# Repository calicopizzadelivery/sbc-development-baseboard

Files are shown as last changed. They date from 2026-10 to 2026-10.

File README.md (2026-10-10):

# sbc-development-baseboard

One board carrying the hardware you need to develop on and remotely manage an
attached single-board computer: a microcontroller that is a USB device to the
target and a console to you, four individually switched USB-A ports, an FTDI
header straight to the workstation, two isolated
SPDT relays on screw terminals, a level-shifted serial console, and a switched
supply for the target itself.

It replaces a bench that currently takes an FRDM-K64F, a QT Py, an 8-channel
relay board, a two-tier USB hub cascade and a CP2102N dongle, wired together by
hand and documented in a port map that has to be re-surveyed whenever anything
is replugged.

## What it does

| Function | How |
|---|---|
| Type at the target | USB HID keyboard + mouse from the K64's device port |
| Cut power to any USB device | Four USB-A ports on two stacked receptacles, each with its own current-limited switch |
| Hard power-cycle the target | Switched +5V_TGT rail up to 3 A behind an eFuse, or any PSU up to 30 V / 5 A through an isolated relay |
| Toggle target I/O — FORCE_RECOVERY and friends | Two SPDT relays, dry contacts, Phoenix terminals |
| Read the target's serial console | MCU-owned UART, auto level translation 1.2–3.6 V |
| Read it from the workstation directly | FT231X on an internal hub port, standard 6-pin FTDI header, 3.3 V |
| Do all of it from somewhere else | 10/100 Ethernet to the workstation |
| Do all of it with no network | USB CDC console over the onboard DAPLink |

Every one of those is addressable from the same ASCII protocol the relay
controller and the HID injector already speak — one line in, one line out,
starting `OK` or `ERR`. See **[docs/protocol.md](docs/protocol.md)**.

## The shape of it

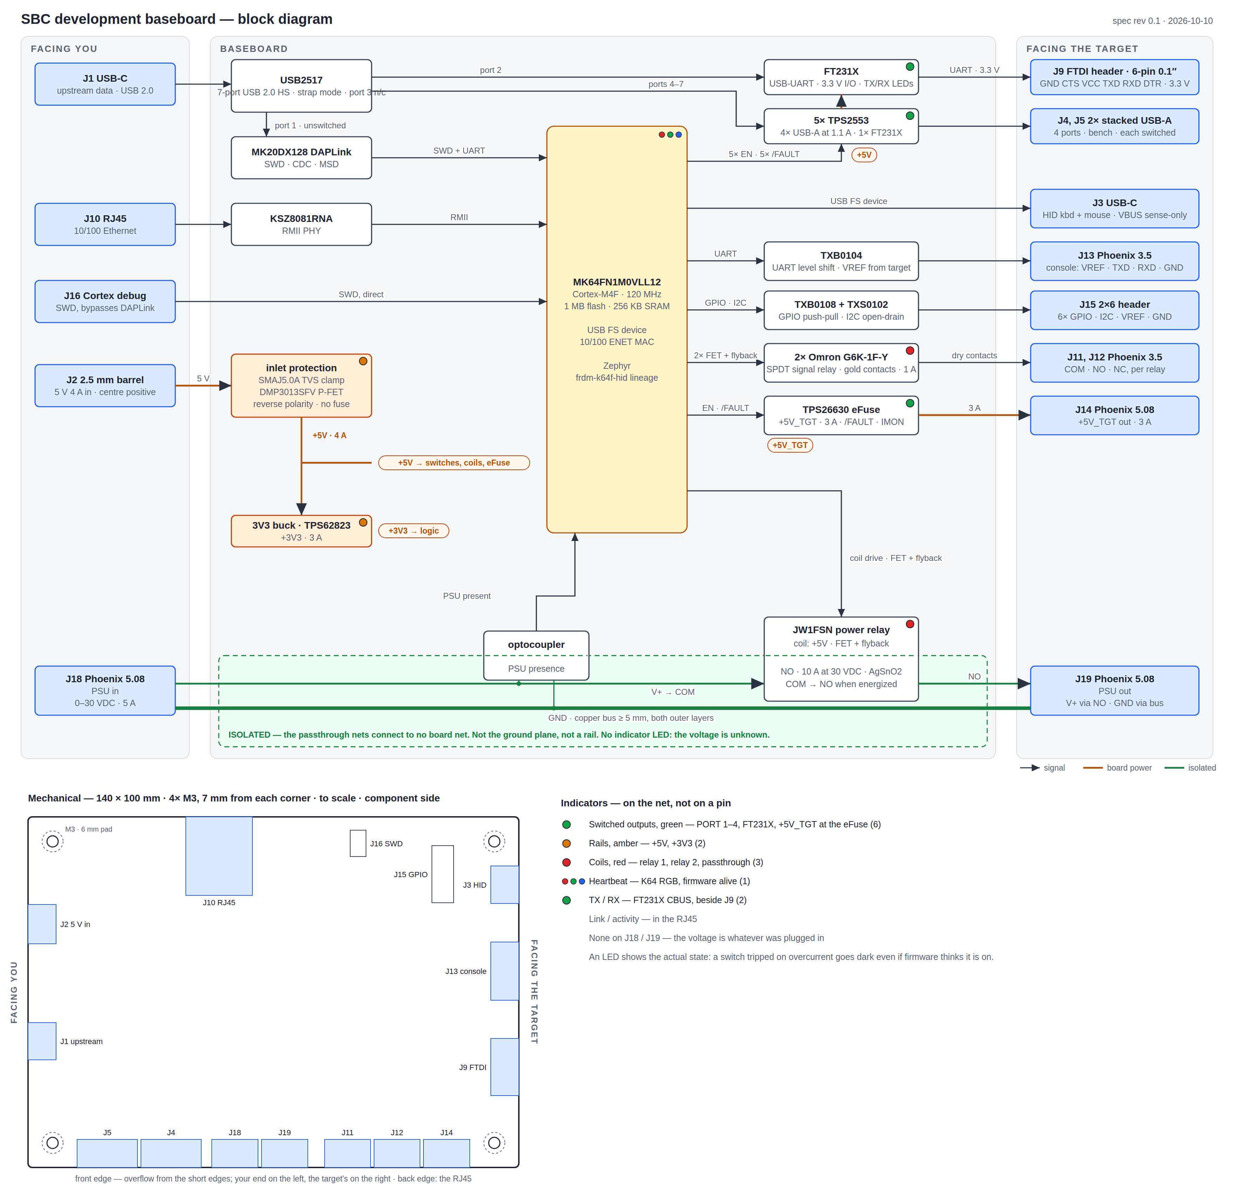
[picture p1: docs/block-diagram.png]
Block diagram


```
workstation ──USB-C──> hub ──> 4x USB-A (switched)     ──> whatever you hang on the bench
                           ──> FT231X, FTDI header     ──> target's console, direct
            ──RJ45───> K64 ──> USB-C device port       ──> target's USB host port
                           ──> UART + VREF             ──> target's console
                           ──> 2x SPDT dry contacts    ──> target's recovery/reset pins
                           ──> switched +5V, 3 A       ──> target's supply
 target PSU ──Phoenix──> isolated relay, NO, 5 A       ──> target's supply, any voltage
 5 V adapter ──barrel──> +5V, one rail, 4 A, 20 W      ──> everything but the passthrough
```

140 × 100 mm, four M3 corner holes. Your connectors leave the left edge, the
target's the right; an LED on every rail, every switched output and every relay
coil, and none on the passthrough, whose voltage is whatever you plugged in.

One USB-C for the workstation and a barrel jack for power (2026-10-10; two
USB-C inlets, a PD charger beside the workstation port, until then). A
workstation port that carries data offers 15 W at best, and four switched ports
plus a target rail need more than that, so power has its own connector: a
5 V 4 A adapter on a 2.5 mm barrel jack, 20 W, which firmware budgets across
the ports and the target rail. A USB-C PD sink feeding two 5 V bucks did that
job first, and went because of what it cost the board rather than the bench:
339 parts became 270, and the one rail layer no longer carries a 3 A inlet
beside two 6 A rails, which is where the router stalled at 98 open connections
on six layers. Keeping power off the workstation link also means the board stays
alive when that link is down, so the MCU can power-cycle the entire USB tree
including its own path back to you.

## Where the design came from

Most of the non-obvious decisions here are bench scars from the Jetson work, not
preferences. They are written up in full in
**[docs/hardware-spec.md](docs/hardware-spec.md)**; the short version:

- **Nothing the MCU depends on sits downstream of a switch it controls.** The
  DAPLink, the Ethernet PHY and the MCU itself are all upstream. `OFF ALL` can
  never take out the console.
- **Rails boot to the state that does no harm.** USB ports and the target rail
  come up powered; relays come up de-energized. Resistors set this while the MCU
  is still in reset, so a reset never drops a load or asserts recovery.
- **The device port cannot back-feed the target.** Its VBUS is sense-only
  through a blocking element. This is the fix for the failure where cutting the
  target's power left it half-alive for 90 seconds because a self-powered
  FRDM-K64F was pushing 5 V up its own device port.
- **The relays are signal relays with gold-clad contacts.** Switching a 1.8 V
  logic pin is a dry circuit; silver power-relay contacts grow an oxide film
  that such a signal cannot break down.
- **The MCU owns the target's console.** No USB-UART bridge to wedge and look
  exactly like a target that is not booting.
- **The target's PSU passes through on its own nets.** A 19 V / 3 A return
  current has no business on the board's ground plane or its USB shields. It
  crosses one relay contact — normally open — so nothing powers until the
  baseboard says so, and a dead baseboard leaves the target off.

## Status

Specification, a generated schematic (KiCad 10, a root sheet and eight sub-sheets, ERC clean) and
a generated, placed six-layer board, both in
[`hardware/kicad/sbc-baseboard/`](hardware/kicad/sbc-baseboard/) with a
[PDF](hardware/kicad/sbc-baseboard/sbc-baseboard.pdf) of the schematic for
review. The board is placed and bulk-routed by the house standard's engine
(see [hardware/kicad/README.md](hardware/kicad/README.md)) and is being
routed again for the barrel-jack inlet (2026-10-10; the board routed before
it, with the PD inlet and the two bucks, stopped at 98 open connections on
six layers and 116 on four); the hand pass that finishes the routing is open.
No firmware.

Next: the routing and the hand pass on the board, then firmware.

## Layout

```
docs/hardware-spec.md   block diagram, part selection, power and pin budgets,
                        safe states, and the open questions
docs/protocol.md        the console protocol, across both transports
docs/block-diagram.*    the diagram above, SVG source and rendered PNG
scripts/block-diagram.py regenerates both; run it with every configuration change
hardware/kicad/         the KiCad project (sbc-baseboard/) and the generator that
                        produced its first pass (gen/) — see hardware/kicad/README.md
hardware/datasheets/    the parts that matter
```

## Related

- [`frdm-k64f-hid`](../frdm-k64f-hid) — the HID injector firmware this board inherits
- [`qtpy-relay-controller`](../qtpy-relay-controller) — the relay protocol and its safe-state rules
- [`nvidia-jetson-tv`](../nvidia-jetson-tv) — the target that motivated all of it

## Licence

Apache-2.0. See [LICENSE](LICENSE).

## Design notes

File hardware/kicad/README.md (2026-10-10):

# KiCad project

`sbc-baseboard/` is the KiCad 10 project: a root sheet and eight sub-sheets,
a project symbol library for the parts the standard libraries lack, an ERC
report, a PDF of every sheet and a BOM.

```
sbc-baseboard/
  sbc-baseboard.kicad_pro   project
  sbc-baseboard.kicad_sch   root: sheet index, mounting holes, the verify-before-fab list
  power.kicad_sch           barrel-jack inlet J2, its TVS and reverse-polarity FET, +5V bulk, the +3V3 buck
  mcu.kicad_sch             K64, USB device port J3, SWD J16, heartbeat
  ethernet.kicad_sch        KSZ8081RNA, magjack
  hub.kicad_sch             USB2517, upstream J1, four switched USB-A, FT231X switch
  ftdi.kicad_sch            FT231X, J9 header, jumpers
  daplink.kicad_sch         MK20DX128 DAPLink
  target.kicad_sch          console, GPIO/I2C breakout, +5V_TGT eFuse
  relays.kicad_sch          two signal relays, PSU passthrough relay and its opto monitor
  libs/                     the house symbol libraries (ecad-libraries), a git submodule pinned to a tag
  sym-lib-table             names them calico-ic and calico-electromechanical, as ${KIPRJMOD}/../libs/...
                            and the stacked USB-A as two units (one per port)
  sbc-baseboard.pdf         all nine sheets
  erc.txt, bom.csv
```

Reference designators are numbered by sheet: R1xx/C1xx power (the inlet
and the +3V3 buck), 2xx MCU, 3xx Ethernet, 4xx hub, 5xx FTDI, 6xx DAPLink,
7xx target I/O (the +5V_TGT eFuse among them), 8xx relays and passthrough.

## How it was made, and the handoff

The schematic was **generated**, by `gen/build.py`. That generator pulls
symbols from KiCad's own libraries (so the embedded copies match what KiCad
ships), builds the missing symbols from datasheet pin tables, lays each sheet
out around its main component (`gen/fanout.py`: lanes leave the IC's pins at
pin pitch, and connectors, series parts, pull-ups and power symbols are drawn
at the ends of the lanes — the style in
[ecad-standards](https://github.com/calicopizzadelivery/ecad-standards)), and
writes the `.kicad_sch` files directly. It then runs `kicad-cli sch erc` and
exports the PDF and BOM. Pin-position maths and power-symbol net naming were
calibrated against `kicad-cli`'s netlist export before any real sheet was
built.

Five checks guard every build and all pass at zero: `kicad-cli sch erc
--severity-all`; `gen/check_geom.py`, which finds wire ends and pin ends that
land on a foreign wire with no junction (the shorts a netlist shows only as a
merged net) and any two wires drawn over each other;
`gen/netcheck.py`, which traces wire-level connectivity in each sheet and
reports any net carrying two rails; and `gen/check_layout.py`, which reports
text over outlines, wires or other text, wires through a part body, and power
symbols pointing the wrong way (GND always hangs down, rails always stand up),
anything on the sheet frame or the title block, pin numbers treated as text
like any other, and pin names inside a symbol that print over each other
(`gen/check_pins.py`, run on library symbols too; its `--gaps` option lists the
closest name pairs). Text widths come from a per-glyph table fitted to the text
extents KiCad writes into its own PDF export. The fifth is reproducibility:
build, `git add` the outputs, build again, and `git status` must be empty. The netlist was also diffed against the
first label-style pass with passive renumbering factored out, so the re-layout
changed drawing, not connectivity (the JP501 default and the J1 VBUS divider
tap, which became a local label, are the two intended exceptions).

**Nothing is drawn over anything else.** Routes into a stacked connector
from one side take staggered columns and rows (the route bound for the
farthest pin gets the outermost column and the nearest row), a tag before a
route ends where the route's target lies, several routes into one pin share
one stub, and a second tap on a wire lands beside the first, never on it.
The geometry check is at zero on every sheet: no wire end on a foreign wire
without a junction, no two wires sharing a stretch.

**The FTDI header is an Adafruit FTDI Friend.** J9 is GND, CTS, VCC, TX, RX,
RTS in that order; VCC is 5 V by default (JP502, bridged A–C) or 3.3 V from
the FT231X's regulator (B–C); pin 6 is RTS by default (JP501, bridged A–C)
or DTR. Logic is 3.3 V. The first pass left J9's VCC pin on an open jumper
only, so it floated by default; the bridged jumpers fix that.

**The DAPLink K20 follows the FRDM-K64F OpenSDA circuit.** DAPLink's k20dx
port reads SWDIO on PTC7 and drives it on PTC6, so both are on the SWDIO
net; the FRDM's 33 Ω series resistors on the K20's USB pair are fitted. See
[reference-design-review.md](../../docs/reference-design-review.md).

**Differential pairs are named for the router.** Every USB 2.0 pair carries
net names `<base>_P` / `<base>_N`, the suffixes KiCad's PCB editor pairs up:
`J1_D`, `J3_D` and `PORT1_D`..`PORT4_D` on the receptacle side of each ESD
array, `HUB_UP` and `HUB_DN1`..`HUB_DN7` at the hub, `K64_USB` and
`FTDI_USB` at the chips (the ESD arrays' pass-through pins and the FT231X's
series resistors each split a pair into two nets, and both halves are named).
The project file carries a `USB` net class matched by pattern
(`*_USB_?`, `*_D_?`, `*HUB_UP_?`, `*HUB_DN?_?`); the patterns are globs over
the full hierarchical name, so a sheet-local net such as `/USB hub/PORT1_VBUS`
is matched only by a pattern that starts with `*` (the port VBUS nets sat in
`Default` until 2026-10-08 for want of that star, and the standard's engine
now stops on a class that no net resolves to). Its differential width and
gap are 0.33 / 0.20 mm, 90 Ω over the ground plane beside each outer layer on
the six-layer stackup (the fab's calculator rules when the stackup is
confirmed); the `ETH` class 0.29 / 0.25 mm for 100 Ω. Route each pair as a pair, no stubs,
over an unbroken reference plane. The power classes are matched the same
way: `PWR_4A` (2.5 mm tracks or pours, 1.0 mm / 0.5 mm vias, three rail vias
per pad) for `+5V` and `*+5V_TGT`, the one inlet rail and the eFuse's
switched output (2026-10-10; until then `PWR_6A` carried the two bucks'
6 A outputs and the PD inlet's `VBUS_IN` ran at 3 A); `USB_VBUS_3A` (2 mm,
1.0 mm vias) for `*PORT?_VBUS` and `*FTDI_VBUS` only; `PWR_1A` (0.6 mm) for
`+3V3`; `PSU_3A` and `PSU_ISO` for the passthrough and its sense lines;
`Default` at 0.2 mm.

**Builds are reproducible.** Every UUID in the generated files is derived,
not drawn: a UUID5 in a namespace made from the project name, keyed by what
the element is (a symbol by its reference and unit, a pin by its symbol, a
wire by its sheet and ends, a label by its sheet, net and position, a sheet by
its file name; identical keys get a counter in draw order). The ERC report
header and the PDF's creation date are pinned to the title-block date. So two
builds of one design give byte-identical files, a commit touches only the
sheets whose design changed, and once layout starts a regenerated sheet keeps
its footprints linked, since the board links footprints to symbols by UUID
path. The costs are the ones KiCad itself has: renaming a reference is a new
symbol, moving a wire or label is a new UUID (nothing outside the sheet refers
to those), and the power symbols, numbered in draw order per sheet, renumber
when one is inserted before them. Keep it that way: never write a random UUID
into the output, and never let an export's timestamp into a tracked file.

**The generator is bring-up tooling, not the source of truth.** The moment
anyone edits the schematic in KiCad, the KiCad files are the design and
`gen/` is history: re-running `build.py` would overwrite the edits. The honest
next step is layout.

```bash
cd gen && ./build.py        # regenerate everything (only while nothing has been hand-edited)
```

## Layout

The board file `sbc-baseboard.kicad_pcb` was generated once, by the
standard's placement engine (`standards/tools/placer.py`, the ecad-standards
repository as a submodule at `standards/`, on KiCad's `pcbnew` Python module)
called from `gen/pcb.py`, from the schematic's netlist, the project file and
the directives in `gen/layout.py`, which are
[docs/layout-directives.md](../../docs/layout-directives.md) as data. It
carries the 140 × 100 mm outline with 2 mm corners, the four M3 holes on GND
7 mm from the corners with their corner keep-outs, Advanced Circuits' 6-layer
stackup, the 270 footprints with their nets (339 until 2026-10-10, when the
USB-C PD inlet, its STUSB4500 controller, bus buffer and programming header
and the two 5 V bucks went and a barrel jack came; 481 connections, 499
before), the L2 and L5 ground planes with the isolated PSU_GND islands, and
`sbc-baseboard.kicad_dru` with the passthrough's isolation rules.

The placement follows
[ecad-standards/layout.md](https://github.com/calicopizzadelivery/ecad-standards/blob/main/layout.md)
section 3: the edge connectors are locked at the directives' positions,
facing outward; the ICs are anchored by flow (the table in the directives:
power enters at J2 on the left edge, its reverse-polarity FET Q101 anchored
at (20, 30) behind the jack with the TVS, gate pull-down, bulk capacitors
and LED around it as the inlet island, the +3V3 buck U105 at (41, 41) as
the one regulator city, laid out from its datasheet figure, and the eFuse
U704 behind J14; the corner the two bucks occupied, x 10..70, y 3..36, is
largely empty since 2026-10-10);
the two parts that straddle the isolation barrier are fixed; every other
part is placed at the pin it serves, by the generator, in five passes (small
decoupling capacitors at their pins, the large parts on an IC's own pins,
bulk capacitors, the small parts on those pins, then parts hosted by other
passives), each on its host's nearest side with the pad on the host's net
facing it, packed outward in rings; since 2026-10-10 the owner's hand
placement outranks all of this (the directives' Placement section: the
saved board is harvested into `gen/hand_placement.py` by the standard's
`tools/handplace.py`, every part fixed where the owner put it, and the
generator reproduces it), so the engine's own placement is what a part
gets until the owner moves it. Small resistors, capacitors, diodes and
transistors that are not on a current-carrying, pair or switching-loop net go
to the bottom, tucked under their host's pin row, clear of through-hole pads
and exposed-pad via fields (the directives' Sides section); the rest stay on
top. The lanes the directives declare (the PSU passthrough: J18 to the relay
to J19) are laid first as footprint keep-outs on both sides and as 2 mm
tracks, so nothing is placed in the way of the 3 A path. ESD parts go down
before anything else, on top, in the first ring at their connector's signal
pins; the USB arrays are flow-through, turned with their receptacle-side
pins toward the receptacle, and both nets of each pair are in the `USB`
class (the schematic build refuses a `_P`/`_N` pair outside it). `placement.txt`
records every part's host, side and ring; the generator prints the parts it
could not keep within 8 mm of their pin. The silkscreen pass places each reference designator where it
overlaps nothing (1.0 mm, then 0.8 mm text) and omits it otherwise, per the
standard's section 6; ICs and connectors are never omitted, their designator
steps out to the nearest pocket instead, and the generator lists those too.
The fabrication layer keeps every designator.

The pairs are laid by the engine as pair lanes (both members at the class's
differential geometry, escapes, the USB-C bridges, two layer changes where
a pair must pass under the port pairs, lengths matched by a bump), the ESD
arrays and series parts anchored for it; the PSU passthrough is laid as
single-net lanes; the one rail, +5V, is a chain of rectangles on L4
referenced to the L5 ground plane, from the jack (x 3..42, y 22..40)
through the 3V3 buck's input, down beside the relay region, along the port
switches, across above the passthrough region to the FTDI switch, the
relays and the eFuse behind J14, which the standard's rails gate holds to
one piece (2026-10-10; until then VBUS_IN, +5V_PORTS and +5V_TGT were
three rails on that layer, the two 6 A ones and the 3 A inlet competing
for it); +5V_TGT leaves the eFuse to J14 as a track in the same class;
+3V3 is routed, in its 0.6 mm `PWR_1A` class, since on six layers a plane
for it would cost the third routing layer. What is left is routed by
FreeRouting through the standard's `tools/autoroute.py` with all of that
locked (`gen/pcb.py --route`; the directives' `FREEROUTING` setting names
the binary), and the hand pass finishes from there. KiCad Routing Tools
was tried on the same board as a second opinion (2026-10-07): two hours in
it had 25 connections left and 1 646 DRC errors, having routed below the
fab's track and via floors and through the keep-outs; FreeRouting honours
the Specctra rules and the fixed lanes, so it stays the bulk router.

`gen/pcb.py` also runs `kicad-cli pcb drc --severity-all --refill-zones`
(the planes are filled for the check and not saved, so a plane that fails to
fill or strays into a keep-out shows; the unconnected count is the ratsnest's
and does not credit the planes); its report is `drc.txt`.

The board as last routed (2026-10-09, six layers, with the PD inlet and the
two bucks still on it; the barrel-jack board of 2026-10-10 started from a
copper reset and is being placed by hand before it is routed again, so
until that routing is committed these are the previous board's figures) is the engine's
placement on the 140 × 100 mm outline, bulk-routed by FreeRouting on L1,
L3 and L6 over the locked lanes, rail vias and planes (`gen/pcb.py --route
--copper`, 24 passes, 5 h 12 min on one thread of which 55 min were its
fanout stage, 122 open connections by its own count after its optimiser)
and given the standard's copper pass: 3 050 track segments, 42 % of the
track length on the top, 37 % on L3 and 21 % on the bottom (of the
router's own, 47 % on L3); 939 vias, of which 237 are the rail vias beside
the pads on the plane nets (156 on ground, 39 on +5V_PORTS, 26 on VBUS_IN,
14 on +5V_TGT, 2 on the passthrough's ground; 14 pads fewer than their
class's count and 115 none at all, both listed in `placement.txt`), 24 the
lanes' own layer changes, 332 ground stitching on the 5 mm grid (2.3
stitching vias per cm² outside the isolated region, 3.5 ground vias per
cm² with the rail vias) and 346 the router's; ground floods over 54 % of
the top and 67 % of the bottom, notched around the passthrough block,
which floods its own `PSU_GND`, all saved filled; the ground planes on L2
and L5 over 76 % each. The three L4 rails are each one piece; +3V3 is
routed at 0.6 mm, 243 segments and 496 mm. The 282 lane tracks are locked
and intact: nine pairs matched to 0.00 mm (six by bumps, three by
symmetric legs), the two Ethernet pairs 2.5 mm apart over their 7.4 to
10.9 mm from jack to PHY, where no bump fits. The router laid the wide
classes at the 2 mm cap apart from the pad-entry necks; five segments run
on at a pad's width more than a millimetre beyond the pad (three on +3V3,
one each on +5V_PORTS and FTDI_VBUS) and are listed for the hand pass to
widen. 98 of the 499 connections
are left for the hand pass: 27 on ordinary signals (61 on four layers), 2
on the HUB_DN2 pair (its shunt capacitors, off the lane), 20 on +3V3, 21
on the port and FTDI VBUS nets, 15 on the 6 A class (the eFuse output's 2
among them), 9 on ground (3 of them the RJ45's ground pin and shield pegs,
inside the magnetics void where no plane reaches), 3 on the passthrough's
sense lines and 1 on the passthrough: the power ones mostly pads with no
room beside them for a rail via, and the port and FTDI VBUS stubs. DRC reports no
errors; its warnings are 23 starved thermals (10 at the three USB-C
receptacles' outer ground pads, whose peg holes leave a flood one spoke,
the rest IC, connector and passive ground pads the routing crowds; the
generator writes that check at warning severity) and one flood neck narrower than
the fab's minimum beside a ground via. From here the board file is the
source of truth and is edited in KiCad; `gen/pcb.py` is not run again over
it, except `--copper`, which adds only what is missing and saves the
board with its fills (the pours are in the file as it is opened and rendered;
until 2026-10-08 the pass stripped them, so the renders showed bare laminate
where the floods are). The schematic generator stays usable: its
derived UUIDs keep the footprints linked.

**The router's settings were measured** (2026-10-08 and 09) on scratch
copies of this placement, each routed from the same placed board with the
standard's wrapper and given the copper pass; open connections after it:
FreeRouting's own costs with the 10 µm clearance margin, 116 (the four-layer
board of 2026-10-08); the margin removed and the small via allowed to every class, 122
(noise: the router had been using the small via on the wide nets all
along); the width cap at 1 mm, 111 (17 fewer on the wide nets, 10 more on
the signals); the cap with via cost 25 and starting rip-up cost 200, 96;
the costs alone with the 2 mm cap, 99, the best on the signals (48 against
61) and on +3V3 (9 against 13). Opening the rail layer to signal routing
made FreeRouting drop the rails as connections (888 open at its first
pass) and run out of time. The costs are the wrapper's defaults from
ecad-standards 743d3a5 on; the cap stays at 2 mm, the margin is gone. The
six-layer board above was routed with them.

The ICs' own layout rules, with sources, are in
[docs/layout-guidelines.md](../../docs/layout-guidelines.md).

The engine's numbers (ring gap, tuck depth, through-hole margin, designator
sizes, which side decoupling takes) are calibrated against 79 published
KiCad boards from Olimex, MNT, SparkFun and Raspberry Pi, measured by
`scripts/harvest-placement.py` (the standard's `tools/harvest.py`) over a
local mirror; the comparison and the
decisions are in [docs/reference-boards.md](../../docs/reference-boards.md)
and in the standard's section 9.

Layout order, per the standard's section 8: the edge connectors against the
mechanical drawing (done: they are locked), the isolated passthrough block
(done: fixed parts, island, rules), then by hand the far-placed parts and
the indicator LEDs, the USB 2.0 pairs from each receptacle through its ESD
array to the hub, the 3V3 buck's switching loop and the +5V rail's `PWR_4A`
pours, and the rest.

State on 2026-10-10, after the first hand pass and the lane redraw: the
generator reproduces the hand placement (271 parts fixed, 84 on the
bottom), the lanes were redrawn around the hand-placed parts where a path
exists (K20_USB enters the DAPLink from the resistors' side over C605 and
past C603; HUB_DN2 crosses the board at y = 54.8, below the DAPLink's
crystal and above Q803; PORT2_D_N's bottom leg passes U408; the standard's
corridors now keep parts off a leg's own side only, so C301 under the ETH
lanes and R211, R435 and D404 under HUB_DN6's leg no longer count), and
`placement.txt`'s "hand placement" section lists what still stands on a
lane: C403 and C406 under the hub's bottom row (HUB_DN1, HUB_DN2, HUB_DN4,
HUB_DN5), the crystal Y401 and its load capacitor C416 at its left column
(HUB_UP, HUB_DN6, HUB_DN7) and R209 at U408's exit (HUB_DN4): the hub's
USB pairs and +3V3 pins alternate along those rows, so a decoupling
capacitor laid against its pin on top sits across a pair's exit, and the
crystal at its pins sits across the upstream pair's. The DRC gate reports
66 errors (138 before the redraw): the lanes laid through those five parts
(shorts, clearance, keep-outs, mask bridges, four hole clearances) and
six hand-placed courtyard overlaps (R211/R433, C105/U105, U403/R208,
C417/R208, U408/R209, C606/Y601); the crossings are gone. 24 pairs of
hand-fixed parts stand closer than the packing margin and 23 gaps between
cities are narrower than 2 mm. The board is not routed before the gate is
clean.

## Design decisions that were made during capture

These are also reflected in `docs/hardware-spec.md`.

- **Hub port map, strap mode.** USB2517 in strap mode (CFG_SEL = 000) so the
  USB tree needs no firmware. In strap mode the self-powered flag shares a pin
  with the non-removable strap, which only covers ports 1-3 — so the DAPLink
  and FT231X went to ports 1 and 2, port 3 is strap-disabled, and the USB-A
  ports are hub ports 4-7. The hub's SMBus is not connected to the K64.
- **Clock tree.** KSZ8081RNA with a 25 MHz crystal in its default 25 MHz mode;
  its 50 MHz REF_CLK output drives the K64's EXTAL0. This is the FRDM-K64F
  arrangement and what Zephyr's `frdm_k64f` board file expects.
- **Power inlet.** A 5 V 4 A (20 W) adapter on a Kycon KLDX-0202-BC barrel
  jack, 2.5 mm centre pin, centre positive, through-hole on the left edge
  (2026-10-10; a USB-C PD inlet with an STUSB4500 sink, its PCA9517A-buffered
  I2C and Qwiic programming header and two TPS54560B 5 V bucks until then,
  which cost 69 of the board's 339 parts and two 6 A rails). An SMAJ5.0A
  TVS at the centre pin; a DMP3013SFV P-channel MOSFET as reverse-polarity
  protection, drain at the jack, source on the rail, gate to GND through
  100 kΩ, body diode toward the rail; 2 × 47 µF, a 100 µF electrolytic and 100 nF on the one +5V
  rail; an amber LED. No series fuse: the adapter limits the inlet, the eFuse
  the target rail, the TPS2553s the ports. The rail feeds the four port
  switches, the FT231X's switch, the three relay coils, the TPS62823 +3V3
  buck and the eFuse. The four ports at their limits, the target at 3 A and
  the board's 0.5 to 0.7 A can sum past 4 A; firmware keeps the 20 W
  budget. The K64's I2C0 and the three PD pins are no-connect, five GPIO
  freed.
- **eFuse.** TPS26630 (in the library) switches +5V_TGT to J14 at 3 A
  (RILIM 6.04 kΩ 1 %, the datasheet's 18 kΩ·A / IOL; 3.65 kΩ for 5 A until
  2026-10-10), UVLO 4.3 V (196k/75k), IMON through 20 kΩ to a K64 ADC pin
  (about 1.7 V at 3 A) and /FLT to a K64 GPIO.
- **I2C translation.** TXS0102 instead of PCA9306, because a 3.3 V target gives
  VREF equal to the K64 rail, which PCA9306 cannot handle.
- **Magjack.** Kycon G7LX-A88S7-BP-GY, because its library symbol names the
  LED pins.
- **K64 USB regulator.** VREGIN is fed only from J3's VBUS through a Schottky,
  so the K64 cannot back-feed the target and its D+ pull-up vanishes when the
  target is off.

## Verify before fab

Listed on the root sheet and in the spec's open questions: K803 JW1FSN pad
mapping, DAPLink k20dx pin assignments, TPS2553 ILIM and TPS26630 UVLO/ILIM
(6.04 kΩ → 3 A) at bring-up, the inlet FET's drop at 4 A, USB2517 VBUS_DET
divider, KSZ8081 crystal load. (The TPS54560B compensation, the STUSB4500
from VSYS alone and the PCA9517A isolation with VCC(B) = 0 went with the PD
inlet, 2026-10-10.)

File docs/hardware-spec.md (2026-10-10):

# SBC development baseboard — hardware specification

*Rev 0.1, 2026-09-12. Specification only; nothing here has been built.*

The board consolidates the hardware used to develop on and remotely manage an
attached SBC. It follows the FRDM-K64F paradigm — an application MCU with a USB
device port facing the target and a separate debug/console path facing the
developer — and extends it with switched USB port power, switched target power,
isolated relay contacts and a level-shifted target console.

---

## 1. Block diagram

Block diagram

*Generated by [`scripts/block-diagram.py`](../scripts/block-diagram.py), which
writes the SVG and renders the PNG, dated in the corner. **When the
configuration changes, change the script, run it, and commit all three in the
same commit as the spec.** The mermaid version below is the same topology, kept
for GitHub's inline rendering.*

```mermaid
flowchart LR
  subgraph WS["facing you"]
    direction TB
    J1["J1 USB-C<br/>upstream data"]
    J10["J10 RJ45<br/>10/100"]
    J2["J2 barrel jack<br/>5 V 4 A in"]
    J18["J18<br/>PSU in"]
  end

  subgraph BD["baseboard"]
    direction TB
    HUB["USB2517<br/>7-port USB 2.0 HS"]
    DAP["MK20DX128<br/>DAPLink<br/>SWD + CDC + MSD"]
    MCU["MK64FN1M0VLL12<br/>Cortex-M4F 120 MHz"]
    PHY["KSZ8081RNA<br/>RMII"]
    INL["SMAJ5.0A + DMP3013SFV<br/>clamp, reverse polarity"]
    B33["TPS62823<br/>+3V3"]
    SW["5x TPS2553<br/>4 ports + FT231X"]
    FTDI["FT231X<br/>USB-UART, 3.3 V"]
    TSW["TPS26630 eFuse<br/>+5V_TGT, 3 A"]
    RLY["2x SPDT<br/>signal relay"]
    PT["passthrough<br/>SPDT power relay, 5 A NO"]
    LT["TXB0104 / TXB0108<br/>TXS0102"]
  end

  subgraph TG["facing the target"]
    direction TB
    J3["J3 USB-C<br/>HID"]
    J13["J13<br/>console"]
    J11["J11, J12<br/>COM/NO/NC"]
    J14["J14<br/>supply"]
    J9["J9<br/>FTDI header"]
    J19["J19<br/>PSU out"]
    J15["J15<br/>GPIO + I2C"]
  end

  J1 --> HUB
  HUB -->|"ports 4-7"| SW --> UA["J4, J5<br/>2x stacked USB-A"]
  HUB -->|"port 2"| FTDI --> J9
  SW -.->|VBUS| FTDI
  HUB -->|"port 1, unswitched"| DAP
  DAP -->|"SWD + UART"| MCU
  J10 --> PHY --> MCU
  J2 --> INL
  INL -.->|"+5V"| SW
  INL -.->|"+5V"| TSW
  INL -.->|"+5V"| RLY
  INL -.->|"+5V"| PT
  INL -.->|"+5V"| B33

  MCU -->|"6x EN + 6x /FAULT"| SW
  MCU -->|"USB FS device"| J3
  MCU -->|UART| LT --> J13
  MCU -->|"GPIO + I2C"| LT --> J15
  MCU -->|"2x FET + flyback"| RLY --> J11
  MCU -->|"EN + /FAULT"| TSW --> J14
  J18 --> PT --> J19
  MCU -->|"FET + flyback"| PT
```

Power is a separate tree; see [§4](#4-power).

Read the arrows into `SW` and `TSW` as the important ones: **port power is
switched by the MCU's own GPIO, not by the hub.** The hub's `PRTPWR` outputs
respond to the *host's* `SetPortFeature(PORT_POWER)` requests, which is the
wrong authority for a bench tool. Cutting a port has to work whether or not a
host is attached and whether or not the host agrees.

---

## 2. Connectors

| Ref | Type | Faces | Purpose |
|---|---|---|---|
| J1 | USB-C receptacle | workstation | Hub upstream data. USB 2.0 only, UFP (5.1 kΩ Rd on both CC). |
| J2 | 2.5 × 5.5 mm barrel jack | adapter | 5 V 4 A (20 W) power in, centre positive: Kycon KLDX-0202-BC, through-hole, horizontal. No data. (2026-10-10; a USB-C PD sink until then.) |
| J3 | USB-C receptacle | target | K64 USB FS device port — HID keyboard/mouse. UFP, **VBUS sense-only**. |
| J4, J5 | USB-A, 2× double-stacked | bench | Hub ports 4–7, two per receptacle, each individually switched (port 1 is the DAPLink, port 2 the FT231X, port 3 disabled). |
| J9 | 6-pin 0.1″ header | target | FT231X UART on hub port 6. Standard FTDI pinout: GND, CTS, VCC, TXD, RXD, RTS/DTR. **3.3 V levels.** |
| J10 | RJ45 + magnetics + LEDs | workstation | 10/100 Ethernet. |
| J11, J12 | 3-pos pluggable 3.5 mm | target | Relay 1 and 2: COM, NO, NC. |
| J13 | 4-pos pluggable 3.5 mm | target | Console: VREF, TXD, RXD, GND. |
| J14 | 2-pos pluggable 5.08 mm | target | Switched +5V_TGT and GND. |
| J15 | 2×6 header, 2.54 mm | target | 6× level-shifted GPIO, I2C SDA/SCL, VREF, GND. |
| J16 | 10-pin Cortex debug | you | Direct SWD to the K64, bypassing DAPLink. |
| J18 | 2-pos pluggable 5.08 mm | PSU | Target passthrough in: V+, GND. 0–30 VDC, 5 A. Isolated from every board net. |
| J19 | 2-pos pluggable 5.08 mm | target | Target passthrough out: V+ through the relay's **NO** contact, GND on the copper bus. Unpowered until commanded. |

Pluggable terminal blocks rather than fixed: a relay's wiring can be unplugged
as a unit and reinstalled the same way, which fixed screw terminals do not give
you. Phoenix MC 1,5/n-G-3,5 headers with MC 1,5/n-ST-3,5 plugs; MKDS 1,5/n-5,08
if you would rather have fixed terminals and do not mind rewiring.

### Why a barrel jack

The brief asked for one USB-C. It cannot be the one, for a reason worth
stating plainly: a USB-C receptacle is a data role and a power role at once.
The board has to be a **UFP** for data, because the hub's upstream port is the
device side of the link to the workstation, and a workstation port that
presents data sources 5 V at 0.9 A, or 15 W if it does PD — enough for the
MCU, not for four switched ports, a bridge and a target rail. Power Role Swap
could in principle ask the workstation for more, but what you get back
depends entirely on the host, which makes the board's capability a property
of whatever it is plugged into. That is not a bench tool. So **J1 is data,
J2 is power**, and J2 carries no data.

Until 2026-10-10 J2 was a second USB-C receptacle: a PD sink negotiating
60 W from a charger into two 5 V bucks, one for the ports and one for the
target, so that every port at its limit plus a 5 A target fitted at once. It
went for the layout's sake. The inlet and its bucks were 69 of the
board's 339 parts (270 since), and the inlet's 3 A rail competed with two 6 A rails for the
one rail layer — the four-layer board plateaued at 116 open connections
after FreeRouting (99 with tuned costs), and six layers reached 98. The 60 W
rationale is withdrawn with them. J2 is now a 2.5 mm barrel jack for a
5 V 4 A adapter, and **the board is budgeted at 20 W**.

What 20 W means: the limiters on the board — four port switches at 1.1 A,
the eFuse at 3 A, the board's own 0.5 to 0.7 A — add up to about twice what
the adapter supplies, and the adapter is the only limit on the sum. Firmware
keeps the budget, refusing to enable more load than 20 W allows (§4). The
typical bench — ports at 2 A, a target at 1 to 2 A, the board at 0.5 A — is
the adapter; every port at its limit and a 3 A target at once is not, and is
no longer a case the board is built for.

The split is still a feature rather than a cost. With J2 alone the MCU, the
relays, the PHY and the target rail are all live, so the board can
power-cycle the whole USB tree — including J1, the path back to the
workstation — and come back. A single-inlet board cannot cut its own
upstream without cutting itself.

### J9, the FTDI header

A second serial console, and a different kind from J13. J13 is owned by the
K64: level-adaptive, captured to a ring buffer, reachable over Ethernet. J9 is
an FT231X on hub port 6, so it appears on the **workstation** as a plain
`/dev/ttyUSB*` and the K64 never sees it. That is the one you want when the
thing you are debugging is the baseboard's own firmware, or when a tool insists
on a real serial device.

The pinout is the one every "FTDI header" means — the TTL-232R cable and the
SparkFun/Arduino breakouts agree on pins 1–5:

| Pin | Signal | Cable colour | Direction |
|---|---|---|---|
| 1 | GND | black | |
| 2 | CTS# | brown | into the FT231X |
| 3 | VCC | red | see below |
| 4 | TXD | orange | **out** of the FT231X — wire to the target's RX |
| 5 | RXD | yellow | **into** the FT231X — wire to the target's TX |
| 6 | RTS# / DTR# | green | out of the FT231X |

Pin 1 is silkscreened `BLK` and pin 6 `GRN`, as the breakouts do, because that
is how people actually orient the cable. TXD and RXD are named from the
FT231X's side, which is also the convention, and the silkscreen carries arrows.

**The header is the Adafruit FTDI Friend** (decided 2026-10-06), jumpers
included. **Pin 6 is RTS# by default** (JP501, bridged A–C), DTR# when the
jumper is cut and bridged B–C; the Friend ships RTS and the Arduino IDE
toggles both, so either uploads to a Pro Mini. **Pin 3 VCC is 5 V by
default** (JP502, bridged A–C), from `FTDI_VBUS` — the switched port supply,
so FTDI CYCLE cuts it — or the FT231X's `3V3OUT` (50 mA) when bridged B–C.
This is a deliberate exception to the §5 back-feed rule: an FTDI header is
expected to power the little board it is plugged into, exactly as the Friend
does, and it is the only board rail that reaches the target by design.

**It is a 3.3 V port.** `VCCIO` comes from `3V3OUT`. Connected to a 1.8 V
console, TXD drives 3.3 V into the target's RX pad. 470 Ω in series with TXD
and pin 6 holds that to a couple of milliamps through the target's clamp, so
the mistake is survivable, but it is still a mistake — **1.8 V consoles go on
J13**, which follows VREF. Question 12 asked whether pin 3 should be able to
*take* a VREF instead; it cannot, because the Friend's pin 3 is an output.

**Its VBUS goes through a TPS2553, like a port, but it is not a port.** The
bench notes record a CP2102N that stayed enumerated and openable while
delivering nothing, and was read as a dead target. The remedy was to
power-cycle its hub port. The FT231X is a better chip, and the failure is not
specific to a chip. So its VBUS is switchable — `FTDI CYCLE` — but under its
own verb, **outside the `PORT ALL` sweep**, booting on. The thing you are
reading the boot log on cannot be swept away.

Hub ports 6 and 7 are flagged non-removable in the USB2517's configuration,
which is what they are. Two LEDs on the FT231X's CBUS pins show TX and RX
activity at the header. TVS on all four signals; the header will be hot-plugged.

### Placement and form factor

**140 × 100 mm (140 × 80 until 2026-10-07, when the routed board proved
too tight and 20 mm was added between the middle blocks and the front
edge), four M3 mounting holes 7 mm in from each corner (10 mm until the
first placement pass, 2026-10-06); connectors, ICs, relays and large parts
on top, small passives on the bottom (one side until the placement pass).** Connectors that face you leave the **left** edge; connectors that
face the target leave the **right** edge. Those are the rules. Here is what
they produce once the arithmetic is done.

A corner hole with a 6 mm standoff pad keeps edge connectors out of the first
~13 mm at each end of an edge (the edges were packed from 14 mm with the
holes at 10 mm; at 7 mm the keep-out is 10.5 mm and the connectors stayed), so
each 100 mm edge has about **74 mm** of usable length (54 mm while the
board was 80 mm tall) and each 140 mm edge about **114 mm**. The target-side
connectors alone — J3, J13, J11, J12, J14, J19, at Phoenix 3.5 and 5.08 mm
body widths — come to **73 mm**. They did not fit on an 80 mm edge in any
order, and on the 100 mm edge they would fill it to the last millimetre, so
the arrangement below stands.

So the short edges carry the primary cable connectors, and the rest go on the
**front** long edge at the end that matches their direction — your things at
the left end, the target's at the right. The back edge was to carry nothing,
so the board could sit against a wall or a DIN rail; at layout (2026-10-06)
the RJ45 moved there, alone, so the two left-edge connectors (both USB-C until 2026-10-10)
could spread along the left edge. The wall and the rail are given up.

| Edge | Connectors | Bodies |
|---|---|---|
| Left, 74 mm usable | J2 power in · J1 upstream, split around the middle | 22 mm |
| Back, 114 mm usable | J10 RJ45 | 19 mm |
| Right, 74 mm usable | J3 HID · J13 console · J19 PSU out | 37 mm |
| Front, left end | J4, J5 USB-A stacks · J18 PSU in | 39 mm |
| Front, right end | J9 FTDI (right-angle) · J11, J12 relays · J14 +5V_TGT | 52 mm |
| Inboard, vertical | J16 Cortex debug · J15 GPIO header | — |

Revised at layout (2026-10-06), see [layout-directives.md](layout-directives.md):
the RJ45 measures 22 mm, so it went to the back edge; J19 moved beside J18
so the isolated passthrough is one region; J9 took the right edge. The
barrel jack (2026-10-10) took the USB-C PD receptacle's place on the left
edge: its front face at the edge, its body 14.5 mm inboard, the
reverse-polarity FET and the clamp behind it.

J16 and J15 are pin headers that take a ribbon or jumpers from any direction,
so they earn no edge. J9 is right-angle because that is what an FTDI header is.

If everything must leave the short edges, the board needs to be **100 mm**
tall: 74 mm usable per edge takes the target-side set with 13 mm of gaps to
spare. That is the alternative to the front-edge overflow, and a one-line
change here.

The mechanical inset on the block diagram is to scale.

---

## 3. Part selection

| Block | Part | Notes |
|---|---|---|
| Application MCU | **MK64FN1M0VLL12** | 100-LQFP, Cortex-M4F 120 MHz, 1 MB flash, 256 KB SRAM, USB FS OTG, 10/100 MAC. Same die as the FRDM-K64F, whose schematic is public and serves as the reference design. |
| Ethernet PHY | **KSZ8081RNA** | RMII, same part as the FRDM, so the Zephyr devicetree carries over. Clocked the FRDM way: 25 MHz crystal on XI/XO, RMII 25 MHz mode (the RNA power-up default), REF_CLK outputs 50 MHz into the K64's EXTAL0. Zephyr's `frdm_k64f` board file says `microchip,interface-type = "rmii-25MHz"`, which is this arrangement. |
| Debug/console MCU | **MK20DX128VFM5** running DAPLink | CMSIS-DAP SWD + USB CDC + mass-storage drag-drop, exactly as OpenSDA v2 does today. |
| USB hub | **USB2517** (or USB2517i) | Strap-configured (CFG_SEL = 000), so the USB tree comes up with no firmware: port 1 DAPLink, port 2 FT231X, port 3 disabled by strap, ports 4–7 to the USB-A receptacles. NON_REM = 11 and LOCAL_PWR = 1 from three resistors. The hub's SMBus is not connected to the K64. 24 MHz crystal. |
| Port switches, 5× | **TPS2553** | Four USB-A ports and the FT231X's VBUS. Adjustable current limit via `ILIM`, soft-start, open-drain `/FAULT`. |
| USB-A receptacles, 2× | double-stacked USB 2.0 Type-A, through-hole | Würth WR-COM dual-port class (61400826021). Two ports per body, shield tabs to chassis. Four ports on two bodies rather than five with one on its own. |
| USB-UART bridge | **FT231XS** | SSOP-20 (`FT231XQ` for QFN). Bus-powered from hub port 6; `3V3OUT` feeds `VCCIO`. CBUS0/1 drive TX/RX LEDs. |
| FTDI header | 6-pin 0.1″, right-angle, board edge | J9. Two solder jumpers: pin 6 RTS#/DTR#, pin 3 VCC. 470 Ω series on TXD and pin 6. |
| Target rail switch | **TPS26630RGE** | 4.5–60 V, 0.6–6 A eFuse, in the KiCad library (TPS25940 is not). ILIM 6.04 kΩ 1 % → 3 A, the datasheet's RILIM = 18 kΩ·A / IOL (3.65 kΩ → 5 A until 2026-10-10, when the 20 W inlet set the budget); UVLO 196k/75k → 4.3 V; `/FLT` to the K64; IMON 20 kΩ, about 1.7 V at 3 A, into a K64 ADC pin for target current. Its input is +5V, its output the switched target rail +5V_TGT. |
| Power inlet | **Kycon KLDX-0202-BC** | J2: 2.5 mm centre pin, 5.5 mm sleeve, centre positive, through-hole, horizontal, for a 5 V 4 A (20 W) adapter. KiCad's `Barrel_Jack_Switch` symbol, the switch contact (pin 3) unused. (2026-10-10; a USB-C PD receptacle with an STUSB4500 sink and two TPS54560B 5 V bucks until then — §2.) |
| Inlet clamp | **SMAJ5.0A** | D101, SMA, from the jack's centre pin to GND. |
| Reverse-polarity protection | **DMP3013SFV** | Q101, P-channel, PowerDI3333-8: −30 V, 12 A, 9.5 mΩ. Drain at the jack, source on +5V, gate to GND through R102 100 kΩ, body diode toward the rail. 2 × 47 µF + 100 µF/10 V 1210 and 100 nF on +5V behind it, and the rail's amber LED. No series fuse: the adapter limits the inlet, the eFuse the target rail, the TPS2553s the ports. |
| 3V3 buck | **TPS62823DLC** | U105. 3 A synchronous, +5V → +3V3. ("Buck 3" until 2026-10-10, when bucks 1 and 2 went with the PD inlet.) |
| Magjack | **Kycon G7LX-A88S7-BP-GY** | 10/100 with LEDs. Chosen over the Würth part because its library symbol names the LED pins. |
| Relays, 2× | **Omron G6K-1F-Y**, 5 V coil | 1 Form C (SPDT), gold-clad contacts, 1 A / 30 VDC, ~30 mA coil. |
| Power relay | **Panasonic JW1FSN-DC5V** | 1 Form C, load on the **NO** contact: 10 A at 30 VDC resistive, AgSnO2, sealed. 530 mW coil, 106 mA at 5 V. Alternates: Omron G2R-1 DC5, G5LE-1 DC5. Ratings in §4. |
| Relay drivers, 3× | 2N7002 (signal relays), AO3400A (power relay) + 1N4148W flyback each | One FET per coil (Q801, Q802, Q803), gate pulldown to ground — see §5. |
| PSU presence detect | LTV-817-class optocoupler | Optional. The only component that touches the passthrough, across an isolation barrier — see §4. |
| UART translation | **TXB0104** | Auto-direction, push-pull. `VCCA` from J13's VREF pin. |
| I2C translation | **TXS0102** | Open-drain auto-direction with internal pull-ups. Chosen over PCA9306 because a 3.3 V target makes VREF equal to the K64 rail, and PCA9306 needs VREF2 > VREF1. Range 1.65–3.6 V. **Do not** use a TXB part for I2C. |
| GPIO translation | **TXB0108** | Same VREF as the console. |
| ESD | USBLC6-2SC6 or TPD2E2U06 per USB pair | Plus TVS on the screw-terminal nets. |

### Two notes on parts that are easy to get wrong

**Relay contact material.** The two relays exist to short things like
FORCE_RECOVERY to ground — a *dry circuit*, microamps at 1.8 V. Silver contacts
on a general-purpose power relay develop a sulphide film that needs tens of
volts or hundreds of milliamps to break down, so such a relay can read as closed
on a multimeter and still not pull a logic pin low. Gold-clad contacts on a
signal relay are specified for exactly this. The ceiling is then 1 A, which is
why target power is a separate switched rail rather than a third relay.

**TXB parts are push-pull only.** A TXB0104 or TXB0108 has weak (~4 kΩ) one-shot
assisted drivers and will fight any external pull-up below about 50 kΩ; on an
open-drain net it simply does not work. The console is push-pull, so TXB is
right there; I2C is open-drain, so it gets a PCA9306. The GPIO breakout is TXB,
which means **the header's pins are push-pull and must not be used as
open-drain** — document that on the silkscreen.

### Indicators

An LED on every load switch output, every power rail, and every relay coil, so
a glance at the board answers "is it powered" and "is it asserted" without a
console. Colour says which kind:

| Colour | Means | On | Count |
|---|---|---|---|
| **Green** | a switched output is live | PORT 1–4 switched VBUS · FT231X switched VBUS · +5V_TGT at the eFuse output | 6 |
| **Amber** | a rail is up | +5V at the inlet · +3V3 | 2 |
| **Red** | a coil is energized | relay 1 · relay 2 · passthrough relay | 3 |
| RGB | heartbeat | K64 — firmware alive, which profile | 1 |
| Green ×2 | TX / RX | FT231X CBUS, beside J9 | 2 |
| Link / act | | in the RJ45 | — |

The output and coil LEDs sit **on the net, not on an MCU pin**: a port LED
hangs off the switched VBUS, a coil LED sits across the coil and is driven by
the FET. They show the actual state rather than the commanded one — a switch
that has tripped on overcurrent goes dark even though firmware thinks it is on
— and they cost no pins. About 25 mA in total; not budgeted separately.

**No LED on the passthrough.** J18 and J19 carry whatever the target's PSU is,
5 to 30 V, and an indicator sized for one end of that range is wrong at the
other. The only element across the passthrough is the optocoupler's emitter,
which exists *because* the voltage is unknown and has its series resistance
sized for the whole range. `psu=present` on the console is the indicator.

---

## 4. Power

### Tree

```
J2 ──> D101 ──> Q101 ──> +5V ──┬──> 4x TPS2553 ──> J4, J5
     SMAJ5.0A   DMP3013SFV     ├──> 1x TPS2553 ──> FT231X
     to GND     reverse        ├──> 3x relay coil
                polarity       ├──> TPS62823 ──> +3V3
                               └──> TPS26630 eFuse ──> +5V_TGT ──> J14
```

One 5 V rail, straight from the adapter (2026-10-10; a USB-C PD inlet, an
STUSB4500 sink and two TPS54560B 5 V bucks — one for the ports, one for the
target — until then). The inlet is a clamp and a pass FET. D101, an SMAJ5.0A,
clamps the jack's centre pin to ground. Q101, a DMP3013SFV P-channel MOSFET, passes
it to the rail: drain at the jack, source on +5V, gate held at ground by
R102 100 kΩ, body diode toward the rail. A reversed adapter leaves the FET
off and the body diode reverse-biased; a correct one turns it on through
9.5 mΩ, about 40 mV at 4 A. Behind it C101 and C102, 47 µF/10 V, C103, 100 µF/10 V electrolytic (the hub's
downstream ports want 120 µF of bulk on their rail), and C104,
100 nF, are the rail's bulk capacitance, and D102, amber, shows the rail.

There is no series fuse: the adapter limits the inlet, the eFuse limits the
target rail and the TPS2553s limit the ports.

The second buck used to keep a target's inrush — large and poorly
characterised, since you do not know what is on the other end of J14 — off
the rail the hub ports share. The eFuse does that now: +5V_TGT is behind its
3 A current limit, so the target cannot pull more than that from the shared
rail at any instant. What the ports and the board draw beside it is the
budget below.

`+3V3` is the TPS62823, U105, from `+5V`: a regulated input and a narrow
conversion ratio for the logic supply.

The target passthrough (J18 → J19) is deliberately absent from this tree. It
is not a board rail and draws nothing from the adapter; see below.

### Budget

| Rail | Load | Typical | At the limiters |
|---|---|---|---|
| +5V | 4× USB-A, each TPS2553 at 1.1 A | 4 × 0.5 A = 2.0 A | 4 × 1.1 A = 4.4 A |
| | FT231X, and J9 VCC if jumpered | 10 mA | 60 mA |
| | 3× relay coil — 2× G6K at 30 mA, JW1FSN at 106 mA | 170 mA | 170 mA |
| +5V_TGT | target SBC, behind the 3 A eFuse | 1.0–2.0 A | 3.0 A |
| +3V3 | K64 ~100 mA, KSZ8081 ~60 mA, USB2517 ~250 mA, DAPLink ~30 mA, translators ~20 mA | 0.30 A | 0.50 A |
| **Total at 5 V** | | **≈4 A (20 W)** | **≈8 A (40 W)** |

The adapter is 5 V at 4 A, and it is the only limit on the sum: the port
switches, the eFuse and the board can together ask for about twice what it
gives, and nothing on the board — no inlet fuse, no contract — stops them.
So **firmware keeps the budget**. It refuses to enable more load than 20 W
allows, reporting `ERR POWER BUDGET` rather than browning out the rail and
dropping every device at once; `POWER` reports the rail's presence and the
eFuse's `IMON` current, the one measurement the board has, and there is no
contract to read (2026-10-10; until then the STUSB4500's negotiated RDO set
the budget). This is the single most load-bearing argument for the MCU
owning port power rather than the hub: the hub has no idea what the inlet
can give. The typical bench — ports at 2 A, a target at 1 to 2 A, the board
at 0.5 A — is the adapter. Every port at its limit plus a 3 A target is
twice it.

Per-port limit is set to ~1.1 A by the `ILIM` resistor: a 500 mA device plus
inrush headroom, and well under what a single port could otherwise pull from a
shared rail.

### Target passthrough

Not every target runs from 5 V. An Xavier AGX ships with a 19 V / 3 A supply,
and the board's own +5V_TGT rail — inside the 20 W budget, behind a 3 A eFuse — is
the wrong tool for it. So J18 and J19 pass an external PSU straight through,
the board's only involvement being one relay contact in the high side.

```
J18 (PSU in)   V+  ──> relay COM ── NO ──> V+   J19 (target out)
               GND ──> copper bus, ≥5 mm, both outer layers ──> GND
```

**The passthrough nets are independent of every board net.** Not the ground
plane, not any rail. The relay's coil is on the board; its contacts are not.
Three reasons, all of which matter at 19 V / 3 A:

- The board is not in the PSU's return path. 3 A does not flow through the
  ground plane, out through the USB shields to the workstation, or down the
  console cable's GND.
- Any PSU can be attached — 5 to 30 V, either polarity, floating or
  earth-referenced — and the board neither knows nor cares.
- A fault on the target's supply side cannot reach the board's logic.

The target's ground still meets the board's through J3 and J13, as it would on
any bench. The point is that the *power* current does not.

**NO, not NC.** The relay is de-energized with the target *off*. Nothing on J19
powers until the baseboard is up and has been told to, and a baseboard that has
lost its own power, or been unplugged, leaves the target off. A target cannot
come up unexpectedly, and a coil cannot energize by accident. Rev 0.1 had this
the other way — NC, the §5 rule taken one step further, so a dead baseboard
still passed power — and it was switched on 2026-10-03 for the workflow: on this
bench, power is something the baseboard *grants*.

The cost is the mirror image, and it is a real one: **a baseboard reset is a
target power cycle.** The gate pulldown drops the coil the instant the K64
enters reset, and firmware cannot pick it up until it is running — a few hundred
milliseconds at best, which is longer than an SBC's input capacitance will hold
it up. Firmware persists the commanded state and restores it first thing at
boot, so the target comes back without anyone asking; but it does come *back*.
The §5 line "resetting the baseboard must not reset the target" holds for
+5V_TGT and the ports, and not for this rail. If that ever matters, the hardware
answer is a latching relay — Omron's G2RK-1 is the double-winding version of the
G2R-1, in the same datasheet, 5 A at 30 VDC, and it holds its state with no coil
power through any reset and through power loss. It is not fitted.

**The load sits on the NO contact, so the headline rating is the one that
applies.** It was going to sit on NC, where SPDT power relays are commonly
derated in a table further into the datasheet, which is why these were read off
the datasheets on 2026-10-03; the table stays as the record:

| Relay | Form C at 30 VDC, resistive | NC derated? | Contacts | 5 V coil |
|---|---|---|---|---|
| **Panasonic JW1FSN** | **10 A** | no | **AgSnO2** | 530 mW |
| Omron G2R-1 | 10 A | no | Ag-alloy | 530 mW |
| Omron G5LE-1 | 8 A, carry 10 A | no | Ag-alloy | ≈400 mW |
| Schrack RT314005 | 16 A rated; ≈10 A at 30 VDC off the breaking curve | no — NC rated 16 A | AgNi 90/10 | 400 mW |
| Omron G5Q-1 | 5 A NO | **3 A NC** | — | — |
| Omron G5LE-1-E | 16 A NO at 250 VAC | **12 A NC** | — | — |

The G5Q-1 is the trap in one line: a "10 A" relay whose NC contact carries 3 A.
On NO, every part in the top half is simply its headline figure. The JW1FSN
stays the pick for its AgSnO2 contacts: an SBC's input is a bank of bulk
capacitance, so every `TGT PSU ON` closes into an inrush of tens of amps for
microseconds, which AgSnO2 tolerates and AgNi pits under. At an AGX's 3 A the
contact runs at 30 % of rating; at the design figure of 5 A, 50 %. The 5 A
design rating stays, and the copper with it. Resistive and capacitive loads are
assumed and no snubber is fitted, so an inductive load on J19 needs its own.

**Copper.** 5 A continuous at a 10 °C rise wants about 2.7 mm of 1 oz outer
copper by IPC-2221. The run is not short: J18 is at the front-left and J19 on
the right edge (§2), so V+ and GND each cover about 110 mm. At **8 mm** wide on
both outer layers, via-stitched and paralleled, that is roughly 4 mΩ per
conductor — 20 mV and 0.1 W each at 5 A. Use ≥8 mm, and put the relay next to
J19 so the switched segment is the short one. The relay's contact pins get solid
pads, no thermal relief. Keep ≥1 mm from every board net, so the isolation is
visible in the layout and not only in the netlist.

**Presence detect, optional, fitted by default.** An optocoupler across J18: LED
in series with a resistor sized to stay within limits from 5 to 30 V (split for
dissipation), an antiparallel diode so a reversed PSU does no harm, transistor
side on a K64 GPIO. That gives `psu=present` in `STATE` without breaking the
isolation, and it is the only component on the board that touches the
passthrough at all. It is the difference between "the target is not booting"
and "the PSU is not plugged in".

---

## 5. Safe states

Every rail's state while the MCU is in reset is set by a resistor, not by
firmware, because K64 GPIO are inputs at reset and stay that way until code
runs. Choose each switch's enable polarity so the passive state is the safe one.

| Load | State in reset | Set by | Why |
|---|---|---|---|
| J4, J5 USB-A ports, FT231X | **ON** | pull-up on active-high `EN` | Never silently drop power. A watchdog reset must not disconnect the console adapter you are reading the target's boot log on — which on this board may be the FT231X itself. |
| +5V_TGT | **ON** | pull-up on `EN` | Same. Resetting the baseboard must not reset the target. |
| Relay 1, 2 | **DE-ENERGIZED** | 100 kΩ gate pulldown | A relay that energizes at boot asserts FORCE_RECOVERY on every reset of the controller. Which way that fails is the installer's choice — SPDT gives both NO and NC on the terminal block. |
| Passthrough relay | **OFF** (de-energized, NO open) | 100 kΩ gate pulldown, and the relay itself | Nothing on J19 powers until firmware is up and has been told to. The cost — a baseboard reset drops the target — is accepted; see §4. |

This is carried straight from the relay controller, where the two firmware
profiles boot opposite ways for exactly these reasons, and where a unit test
asserts each one.

Two matching firmware rules:

1. **Write the output register before enabling the driver.** On K64, `PDOR`
   before `PDDR`. Reversing them drives the pin's reset value for as long as it
   takes to reach the next instruction, which is enough to click a relay.
2. **The relay pins are never configured as anything but GPIO outputs.** No
   alternate-function pin shared with a peripheral that might drive it.
3. **Restore the passthrough's persisted state immediately after rule 1**,
   before the network, before USB, before anything that can block. Every
   millisecond here is target downtime.

### Back-feed

The failure to design out: a self-powered board pushing 5 V up its own device
port into the target, so cutting the target's power leaves it half-alive. On the
current bench this takes 90 seconds to decay, the console goes silent, and the
whole thing reads as a dead module rather than a power problem. `jetson-power.py`
works around it in software by cutting the back-feed port first.

Here it is a hardware rule: **J3's VBUS is an input only.** A >100 kΩ divider for
presence detection, and if the K64's `VREGIN` is fed from it at all, through a
blocking element. No path from any board rail onto J3's VBUS, on any layer.

That removes the VBUS path entirely. What remains is the 1.5 kΩ D+ pull-up,
which can trickle a milliamp or so into the target's PHY rail — orders of
magnitude below what holds an SBC alive, and not worth a data mux to fix.

---

## 6. Pin budget

100-LQFP, checked against function so that pin count does not become a surprise
during capture.

| Function | Pins |
|---|---|
| RMII to PHY — TXD0/1, TXEN, RXD0/1, RXER, CRS_DV, MDIO, MDC | 9 |
| RMII 50 MHz reference | 1 |
| USB FS device — DP, DM, VREGIN, VOUT33 | 4 (dedicated) |
| Port power — 4× EN, 4× /FAULT | 8 |
| FT231X power — EN, /FAULT | 2 |
| Target power — EN, /FAULT | 2 |
| Relays — 3× gate | 3 |
| PSU presence — optocoupler | 1 |
| Target UART — TXD, RXD | 2 |
| DAPLink CDC UART — TXD, RXD | 2 |
| I2C — target breakout (separate bus) | 2 |
| GPIO breakout | 6 |
| Hub `RESET_N`, PHY interrupt | 2 |
| SWD — SWCLK, SWDIO, `RESET_b` | 3 |
| Status — RGB heartbeat; every other LED is on its net, §3 | 3 |
| **Total signal** | **50** |

Comfortable in a 100-LQFP after power and analogue pins, and five pins freer
than it was (2026-10-10: the PD sink's I2C0 and its three status lines went
with the PD inlet; 53 signal pins until then). Two things to note: the
target's I2C is on its own bus, I2C1, so a target that hangs SDA low takes
out nothing of the board's — I2C0 is free and the hub's SMBus is not
connected; and the port LEDs can move behind a shift register if layout
wants the pins back, since their timing does not matter.

### Allocation (as captured)

| K64 pins | Function |
|---|---|
| PTA5, PTA12–17, PTB0, PTB1 | RMII (same as FRDM-K64F) |
| PTA18 (EXTAL0) | 50 MHz REF_CLK from the PHY |
| PTA0, PTA3, RESET_b | SWD (J16 and DAPLink) |
| PTB16, PTB17 | UART0 to the DAPLink CDC |
| PTC3, PTC4 | UART1 to the target console (J13) |
| PTC10, PTC11 | I2C1 to the target (J15) through the TXS0102 |
| PTC0, PTC1, PTC2, PTC5 / PTC6–PTC9 | PORT1–4 EN / FAULT |
| PTC12, PTC13 | FTDI EN / FAULT |
| PTC14, PTC15, PTB2 | TGT_EN, TGT_FAULT, TGT_IMON (ADC0_SE12) |
| PTC16, PTC17, PTC18 | relay 1, relay 2, passthrough coil |
| PTB3 | PSU_PRESENT |
| PTB18, PTB22 | HUB_RESET, PHY_INT |
| PTB19, PTB20, PTB21 | heartbeat RGB |
| PTD0–PTD5, PTD6 | GPIO1–6 to J15, J3 VBUS sense |
| spare | PTA1, PTA2, PTB23, PTD7, PTE0–6, PTE26, the ADC/DAC pins; PTE24, PTE25 (I2C0) and PTB9, PTB10, PTB11 (pins 31, 32, 57, 58, 59), no-connect since the PD inlet went (2026-10-10) |

---

## 7. Firmware

Zephyr, extending `frdm-k64f-hid`. That application already splits its command
layer from its transport — it takes a line and a reply function — so the
Ethernet listener is an addition rather than a rewrite.

Three transports, one parser:

| Transport | Path | For |
|---|---|---|
| USB CDC | DAPLink on hub port 1 → J1 | Local work, bring-up, and whenever the network is the thing that is broken |
| TCP | Ethernet → J10 | Remote management, the normal case |
| SWD | DAPLink → J16 | Debugging the baseboard itself |

J9 is not a transport. It reaches the workstation through the hub and the K64
cannot see it; the only thing firmware does with it is power-cycle it.

Protocol in **[protocol.md](protocol.md)**. It keeps the `OK`/`ERR` single-line
convention both existing firmwares use, and the persistent `SETID` identity from
the relay controller — several of these will share a workstation, and a script
that picks the wrong board cuts power to the wrong machine.

The RGB heartbeat from the QT Py carries over: a glance at the board says the
firmware is running and its loop is not wedged.

---

## 8. Open questions

| # | Question | Blocks |
|---|---|---|
| 1 | ~~Per-port current limit — 0.75 A or 1.1 A?~~ **Resolved** at four ports: 1.1 A. See §4. | — |
| 2 | ~~Clock tree~~ **Resolved** from Zephyr's `frdm_k64f` board file (`rmii-25MHz`): 25 MHz crystal on the PHY, its 50 MHz REF_CLK into the K64. Captured that way. | — |
| 3 | DAPLink board ID and MSD volume name. A custom DAPLink build can name the volume anything; `frdm-k64f-hid/scripts/flash.sh` already reads `LABEL=${MBED_LABEL:-MBED}`, so agreeing with it is one environment variable rather than a change. Decide the name. | Firmware tooling |
| 4 | USB VID/PID. **Deferred indefinitely, by decision (2026-10-03).** `frdm-k64f-hid` ships `2fe3:0001`, the Zephyr project's VID, and the hub and DAPLink will want identifiers too; all of it stays as-is on the bench. Revisit only if a board leaves the lab. | — |
| 5 | K64 lead time. If it is bad, the fallback is an RP2350 + W5500, which costs the Zephyr board port and the FRDM tooling. | BOM |
| 6 | ~~Does J14 need a raw inlet pass-through for 12 V targets?~~ **Resolved** by J18/J19: any PSU passes through, isolated. J14 stays for 5 V targets that want to live inside the 20 W budget without a PSU of their own. | — |
| 7 | ~~Form factor and mounting~~ **Resolved:** 140 × 100 mm (140 × 80 until 2026-10-07), four M3 at 7 mm from each corner (10 mm until the first placement pass), you on the left edge, the target on the right, overflow to the front edge. §2. | — |
| 8 | Authentication on the TCP transport. Today anything that can reach the port can cut the target's power and assert its recovery pins. A trusted segment is the assumption; decide whether that is good enough. | Remote management outside the lab |
| 14 | ~~DAPLink k20dx HIC pin assignments~~ **Resolved** (2026-10-06) against DAPLink's `k20dx/IO_Config.h` and `uart.c` and the FRDM-K64F OpenSDA schematic: SWCLK PTC5, SWDIO out PTC6 **and SWDIO in PTC7** (both on the SWDIO net, as on the FRDM), nRESET PTB1, LED PTD4, UART1 PTC3 RX / PTC4 TX. The FRDM's 33 Ω series resistors on the K20's USB D+/D− are now fitted. PTD6 (POWER_EN) and PTD7 (VTRG_FAULT_B) stay unconnected: nothing here for them to switch or sense. | — |
| 15 | Component values around every IC follow its datasheet typical application or evaluation board; the comparison and the deliberate deviations are in [reference-design-review.md](reference-design-review.md). Still to confirm at bring-up: crystal load capacitors against the crystals ordered, TPS26630 MODE/OVP strapping and ILIM (6.04 kΩ → 3 A), TPS62823 inductor saturation, the inlet FET's drop at 4 A, JW1FSN pad mapping. | power / hub / target sheets |
| 11 | ~~Power relay NC rating~~ **Resolved** against the datasheets: Panasonic JW1FSN-DC5V, 10 A at 30 VDC on the form C with no NC derate, AgSnO2. G2R-1 and G5LE-1 also pass; G5Q-1, at 3 A NC, does not. The load has since moved to the NO contact, where the headline figure applies. Table in §4. | — |
| 12 | ~~J9 pin 3 as a VREF input~~ **Resolved** (2026-10-06): J9 mirrors the Adafruit FTDI Friend, whose pin 3 is a VCC *output*. Pinout GND, CTS, VCC, TX, RX, RTS; VCC = 5 V by default (JP502 A–C bridged) or 3.3 V (B–C); pin 6 = RTS by default (JP501 A–C bridged) or DTR; 3.3 V logic. No VREF-input position; 1.8 V consoles use J13. | — |
| 13 | ~~Passthrough at boot~~ **Resolved:** restore the last commanded state. A watchdog reset must not strand a remote target. The G2RK-1 latching relay stays unfitted unless the reset gap proves to matter. | — |

Item 4 is deferred on purpose. It only becomes expensive if a board leaves the
lab, and a VID has lead time of its own, so that is the moment to start it.
Items 9 and 10 were about the PD sink's NVM and its programming circuit, and
went with the PD inlet (2026-10-10).

---

## 8a. Stackup and controlled impedance

Advanced Circuits' standard 6-layer 0.062" stackup (their drawing,
2026-10-09; the board was four layers until then and ran out of routing
room): 1 oz copper on all six layers, two 2116 prepreg sheets (≈ 0.009",
εr ≈ 4.3; 9.8 mil pressed by their prepreg guide) between L1 and L2, L3
and L4, and L5 and L6, a 0.014" core between L2 and L3 and between L4 and
L5; 0.062" ± 10 %. Their standard stackups are not guaranteed unless the
order specifies them: order the board as Custom / Controlled Dielectric,
and confirm at quote time that both cores are 0.014" (one of their pages
shows 0.005" for the second core; if that is what they build, the rail
and the inner routing layer swap places). L2 and L5 are the
ground planes, L3 routes, L4 carries the +5V rail, drawn as rectangles
(the three power rails until 2026-10-10). The USB 2.0 pairs run
on the outer layers as 90 Ω edge-coupled microstrip over the ground plane
beside them: **0.33 mm traces, 0.20 mm gap** (centred on 90 Ω across the
Kirschning-Jansen and IPC-2141 estimates for a 0.249 mm dielectric at
εr 4.3 with 1 oz copper); the Ethernet pairs at 100 Ω, 0.29 mm and
0.25 mm. These are the `USB` and `ETH` net classes'
differential width and gap in the project file. State the stackup in the
fab notes and ask for controlled impedance on those classes; the fab's
impedance calculator has the last word on the width and gap.

### Current pathways

Laid out for the current in the class name, on 1 oz outer copper at a
10 °C rise (IPC-2221: 3 A ≈ 1.4 mm, 4 A ≈ 2.3 mm), rounded up. Each class
is a net class directive flag on the schematic and a pattern in the project
file.

| Class | Nets | Current | Width | Vias per layer change |
|---|---|---|---|---|
| `PSU_3A` | PSU_VP, PSU_VOUT, PSU_GND (J18 → K803 → J19) | 3 A continuous | 2 mm or pour | two, 0.5 mm drill |
| `USB_VBUS_3A` | PORT1–4_VBUS, FTDI_VBUS | 3 A each | 2 mm or pour | two, 0.5 mm drill |
| `PWR_4A` | +5V, +5V_TGT | 4 A (+5V_TGT 3 A, at the eFuse) | 2.5 mm or pour; +5V is rectangles on L4 | two, 1.0 mm vias on a 0.5 mm drill; three rail vias beside each pad |
| `PWR_1A` | +3V3 | 1 A | 0.6 mm, routed on an inner layer | one |

`PWR_4A` replaced `PWR_6A` (4 mm, +5V_PORTS and +5V_TGT at 6 A) on
2026-10-10, when the one 4 A inlet rail replaced the two buck rails, and
VBUS_IN left `USB_VBUS_3A` with the PD inlet.

J1's and J3's VBUS carry no load (sense only) and are not classed.

## 9. Schematic

Captured 2026-10-04 in KiCad 10, under
[`hardware/kicad/sbc-baseboard/`](../hardware/kicad/sbc-baseboard/): a root
sheet and eight sub-sheets (power, MCU, Ethernet, hub, FTDI, DAPLink, target
I/O, relays and passthrough), 331 parts and 354 nets at capture, 270 parts
since the PD inlet went (2026-10-10), **ERC clean at every severity**, with
[`sbc-baseboard.pdf`](../hardware/kicad/sbc-baseboard/sbc-baseboard.pdf) for
review and a BOM. Reference designators are numbered by sheet (1xx power …
7xx target I/O, 8xx relays).

Every sheet is drawn around its main component: nets leave the IC as wires,
fanning out in pin order, and whatever a net connects to sits at the end of
its wire — the connector at the page edge, the series part in line, the
pull-up hanging from its rail. Labels are kept for nets that leave the page
(and three local taps: the two VBUS dividers and the J15 breakout). The rules
are written down in the
[ecad-standards](https://github.com/calicopizzadelivery/ecad-standards)
repository so later boards read the same way. How this one was generated,
and the rule that the KiCad files become the source of truth the moment they
are hand-edited, is in [`hardware/kicad/README.md`](../hardware/kicad/README.md).

Two part-level details settled during capture, worth knowing when reading
the sheets: the single-line ESD diodes on the console and FTDI lines
are PESD5V0S1UL in SOD-882, drawn with KiCad's own symbol so the cathode is
on the line and the anode on GND; and the stacked USB-A receptacles J4/J5 use
a two-unit project symbol, one unit per port, so each port block (switch,
ESD array, receptacle) is drawn as its own straight-through cluster.

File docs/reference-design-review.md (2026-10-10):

# Reference-design review

Every IC's surrounding parts were checked against the implementation its
maker publishes: the datasheet's typical application or design example, and
the evaluation board where its schematic was available. The point is to ship
proven values and to know exactly where and why this board departs from them.
Checked 2026-10-04 against the documents named per part; "changed" means the
schematic was brought in line in commit `reference-design review`. On
2026-10-10 the USB-C PD inlet went and a 5 V 4 A barrel jack came: the rows
for the STUSB4500, its PCA9517A bus buffer and the two TPS54560B bucks are
gone, the rows for the jack and the reverse-polarity FET are new, and the
rows that named the old rails are reworded.

| IC | Source | Reference implementation | This board | Verdict |
|---|---|---|---|---|
| Kycon KLDX-0202-BC (J2) | Kycon drawing: 2.5 mm centre pin, 5.5 mm sleeve, through-hole, horizontal, with a switch contact | three pins: centre, sleeve and the switch contact | KiCad's `BarrelJack_Kycon_KLDX-0202-xC_Horizontal`, drawn from the drawing (not re-measured here); the `Barrel_Jack_Switch` symbol with pin 3, the switch contact, unused; centre positive, the sleeve on GND; D101 SMAJ5.0A from the centre pin to GND (2026-10-10) | Matches as far as the library's footprint does; the drawing is to be checked against the ordered part's revision before fabrication. |
| DMP3013SFV (Q101) | Datasheet (no application figure: a reverse-polarity pass FET needs none) | P-channel, −30 V, 12 A, 9.5 mΩ, PowerDI3333-8; as a reverse-polarity switch its drain faces the supply, its source the load, its gate goes to ground, and the body diode conducts toward the load until the channel enhances | drain at the jack's centre pin, source on +5V, gate to GND through R102 100 kΩ, body diode toward the rail; C101/C102 47 µF/10 V 1210 and C103 100 nF on +5V, D102 amber through R101 1 kΩ | Matches. No series fuse by design: the adapter limits the inlet, the eFuse the target rail, the TPS2553s the ports. |
| TPS62823 (U105) | Datasheet §9.2 typical application, §9.2.2.2–3 | L 470 nH (XFL4015-471, 6.6 A sat); C_in 10 µF; C_out 2×10 µF or 22 µF (up to 150 µF allowed); R2 100 kΩ recommended, R1 = R2·(VOUT/0.6 − 1); C_ff = 12 µs / R2 = 120 pF | L101 470 nH/4 A; C104 10 µF; C105/C106 22 µF; R104 100 kΩ, R105 453 kΩ (3.32 V), C107 120 pF (the power sheet's designators renumbered on 2026-10-10 when the PD inlet and the two 5 V bucks went; the input is the inlet's +5V, buck 1's +5V_PORTS until then); EN tied to VIN; PG open | **Changed**: the divider was 100 kΩ/22.1 kΩ with no feed-forward capacitor; now the recommended set. Check the chosen inductor's saturation rating is at least 4.5 A. |
| TPS2553 (U403–U407) | Datasheet §10.2.3 "typical application as USB power switch" | 0.1 µF at IN; R_FAULT 100 kΩ; R_ILIM 20 kΩ (1.2 A example), 15–232 kΩ allowed; ≥ 120 µF bulk per hub on the downstream side | 100 nF at each IN plus the rail's bulk; FAULT pull-ups 10 kΩ (faster edge, within limits); R_ILIM 23.7 kΩ ≈ 1.1 A; 22 µF per port plus the inlet's two 47 µF on +5V (194 µF on buck 1's +5V_PORTS until 2026-10-10) | Matches. The FAULT pull-ups sit at the K64 as one column of resistors to +3V3 (the datasheet allows them anywhere on the net). |
| TPS26630 (U704) | Datasheet §9.2.2.1 (R_ILIM = 18/I_OL kΩ), electrical characteristics (UVLO 1.2 V, dVdT 2 µA / 25 V/V, IMON 27.9 µA/A) | R_ILIM 9.09 kΩ for 2 A; dVdT capacitor per ramp time; IMON resistor sized for the ADC | R708 6.04 kΩ → 3 A (2026-10-10, the 20 W inlet's budget; 3.65 kΩ → 4.9 A for the 60 W PD inlet's 5 A target until then); UVLO 196 kΩ/75 kΩ → 4.34 V rising; dVdT 10 nF → 5 V/ms; IMON 20 kΩ → 0.56 V/A, about 1.7 V at 3 A; MODE, OVP, PGTH to GND; PGOOD open | Matches the spec's intent. Confirm at bring-up that MODE = GND selects the wanted fault response (latch or retry) and that OVP tied low is acceptable. |
| USB2517 (U402) | Datasheet pin table; EVB-USB2517 schematic | RBIAS 12.0 kΩ 1 %; 24 MHz crystal with 33 pF; VDD18 and VDD18PLL 1 µF + 0.1 µF; VDD33 0.1 µF per pin + 4.7 µF; VBUS_DET from upstream VBUS through 100 kΩ/100 kΩ with 1 µF; RESET_N 100 kΩ pull-up + 0.1 µF; straps 10 kΩ; TEST to GND | R404 12.0 kΩ 1 %; 24 MHz + 2×33 pF; 1 µF + 100 nF on each 1.8 V pin; 7×100 nF + 4.7 µF; VBUS_DET 100 kΩ/100 kΩ + 1 µF; RESET_N 10 kΩ + 1 µF, driven by the K64; 10 kΩ straps; TEST to GND | **Changed**: VBUS_DET was 10 kΩ/22 kΩ (3.4 V at the pin, above VDD33); now the evaluation board's divider. |
| KSZ8081RNA (U301) | Datasheet pin table, §11 magnetics | REXT 6.49 kΩ 1 %; VDD_1.2 2.2 µF + 0.1 µF; MDIO and INTRP each need an external 1.0 kΩ pull-up; 25 MHz crystal; REF_CLK 50 MHz to the MAC; on-chip termination; transformer centre taps to 0.1 µF each, not to a supply; PHYAD straps have internal pull-downs (address 0) | R311 6.49 kΩ 1 %; C306/C307 2.2 µF + 100 nF; MDIO 1 kΩ, INTRP 1 kΩ; 25 MHz + 2×22 pF; 33 Ω series on REF_CLK; TCT/RCT 100 nF to GND; no straps (the K64's RMII pins are inputs at reset); 75 Ω ×4 + 1 nF/2 kV Bob Smith | **Changed**: the MDIO pull-up was 4.7 kΩ; the datasheet requires 1.0 kΩ. Crystal load capacitors depend on the crystal's CL: confirm 22 pF against the part ordered. |
| MK64FN1M0VLL12 (U201) | Datasheet; FRDM-K64F arrangement (RMII clock from the PHY, USB regulator) | VREGIN 2.2 µF, VOUT33 2.2 µF; VDDA filtered; VBAT; RESET_b and NMI_b pulled up; 32.768 kHz crystal with load capacitors per its CL | C201/C202 2.2 µF; FB201 + 100 nF + 10 µF on VDDA/VREFH; VBAT to +3V3; 10 kΩ pull-ups, 1 µF on reset; Y201 with 2×12 pF; EXTAL0 fed by the PHY's 50 MHz through R307 33 Ω; D201 BAT54 feeds VREGIN only from J3 VBUS | Matches. Confirm 12 pF against the 32.768 kHz crystal's CL (FRDM-K64F uses a 12.5 pF part). |
| MK20DX128VFM5 (U601) | mbed HDK "DAPlink-K20DX v1.0.0" interface schematic; DAPLink k20dx HIC | USB 5 V into VREGIN, VOUT33 feeds VDD/VDDA; crystal on XTALIN/XTALOUT (8 MHz per the k20dx firmware); SWD and UART pin use per the HIC; reset button | VREGIN from +5V with 2.2 µF; VOUT33 → K20_3V3 with 2.2 µF + 2×100 nF; 8 MHz + 2×18 pF; SWCLK PTC5, SWDIO PTC6, UART1 PTC3/PTC4, nRESET PTB1, LED PTD4; 10 kΩ + 100 nF + button on RESET | Matches. Confirm 18 pF against the 8 MHz crystal's CL. |
| FT231XS (U501) | Datasheet fig. 6.1 "bus powered configuration" | 27 Ω in series with USBDM/USBDP and 47 pF to GND on the bus side; VCC through a ferrite bead with 10 nF + 4.7 µF + 100 nF; 3V3OUT 100 nF; VCCIO from 3V3OUT; RESET# may be tied to 3V3OUT; CBUS LEDs | R504/R505 27 Ω, C502/C503 47 pF; VCC is the TPS2553-switched FTDI_VBUS with 10 µF + 100 nF at the pin and 10 µF at the switch (no ferrite); C501 100 nF; VCCIO from 3V3OUT; RESET# 10 kΩ to 3V3OUT; 470 Ω LEDs | **Changed**: the USB series resistors and capacitors were missing. The ferrite bead is replaced by the power switch and its bulk capacitor: a deliberate deviation. |
| TXB0104, TXB0108, TXS0102 (U701–U703) | Datasheets | 0.1 µF per supply; OE pulled low through a resistor until the supplies are up; VCCA ≤ VCCB | 100 nF per supply; OE tied to VCCA = VREF_TGT, which is the target's own rail; VCCB = +3V3 is always up | Deviation by design: OE follows the target rail, so the translators are off whenever the target is off, and VCCA never exceeds VCCB. |
| USBLC6-2SC6, PESD5V0S1UL, SMAJ5.0A (ESDA25W at the PD inlet's CC pins until 2026-10-10) | Datasheets | Line-side placement next to the connector | As drawn | Matches. |
| LTV-817, G6K-2F-Y, JW1FSN | Datasheets | 1–10 mA LED current; 5 V coils with flyback diodes; drivers rated for the coil current | 2×1.8 kΩ (1–8 mA over 5–30 V); 1N4148W on every coil; 2N7002 for the 20 mA signal relays, AO3400A for the 106 mA power relay | Matches. |
| GCT USB4105 (J1, J3; J2 too until 2026-10-10) | Drawing rev B4, "Recommended PCB Layout": 12 × 1.15 contact pads, 2 × Ø0.65 board-lock peg holes 5.78 mm apart, 4 × Ø0.60 shell slots | KiCad's footprint reproduces the drawing; its outer ground pads sit 0.19 mm from the peg holes | House footprint (ecad-libraries 0.3.6): the same pad for pad, with the four outer ground pads A1, A12, B1, B12 shortened 1.15 → 1.05 mm at the peg end, hole to copper 0.29 mm at those pads; the next pads in (A4, A9, B4, B9) stay at KiCad's 0.26 mm, the footprint's new minimum | Deviates from the drawing by 0.1 mm on four ground pads (9 % less solder area each) so the fab's 0.25 mm hole-to-copper minimum holds without an exception; the shell slots carry the mechanical load. |

## FRDM-K64F OpenSDA, revisited for the DAPLink K20 (2026-10-06)

The FRDM-K64F schematic (rev E4, sheet 4 "OpenSDA interface") agrees with
DAPLink's `k20dx` IO_Config.h: SWCLK PTC5, SWDIO PTC6 driving and PTC7
reading the same line, nRESET PTB1, LED PTD4, UART1 PTC3/PTC4. Two things
the first pass missed, both now fitted: PTC7 was unconnected (DAPLink reads
SWDIO through it, so SWD would never have worked), and the FRDM's 33 Ω
series resistors on the K20's USB D+/D− (R20/R22). The FRDM's level shifters
between the K20 and its target are not needed here: the K64 target runs at
the K20's 3.3 V. PTD6 (POWER_EN) and PTD7 (VTRG_FAULT_B) are left open; the
firmware drives one and ignores the other.

## Open items for bring-up

- Crystal load capacitors (24 MHz 33 pF, 25 MHz 22 pF, 8 MHz 18 pF, 32.768 kHz
  12 pF) are right only for crystals with the matching CL: confirm when the
  crystals are chosen.
- TPS26630: MODE and OVP strapping (the limit is 3 A since 2026-10-10,
  under the 4 A adapter; until then 4.9 A, checked against the buck's 6 A
  switch limit).
- TPS62823: inductor saturation rating (≥ 4.5 A).

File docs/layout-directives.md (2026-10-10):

# Layout directives

What the board is placed from. Everything here comes from
[hardware-spec.md](hardware-spec.md) §2 and §8a and the block diagram; when
one of them changes, this file changes with it. The origin is the board's
top-left corner, X to the right, Y down, in millimetres, as KiCad draws it.

## Outline and stackup

- **140 × 100 mm**, 1.6 mm, 2 mm corner radius (140 × 80 until 2026-10-07,
  when 20 mm of board was added below y = 52: everything behind the front
  edge, from the USB-A stacks and the passthrough region to the relays and
  the eFuse, moved 20 mm with the edge, and the band between the hub, the
  3V3 buck and the K20 and the front-edge blocks is the room gained. The
  routed 140 × 80 board was discarded with the change and stays in history).
  Components on **both sides** by the rule under Sides below (2026-10-06; top
  side only before that).
- Advanced Circuits standard 6-layer 0.062" (their drawing, 2026-10-09;
  four layers until then: the router left 116 connections open on two
  routing layers, 99 with its costs tuned, and the wall was the layer
  count): 1 oz on all six layers; L1 signal and ground flood, two 2116
  sheets (9.8 mil pressed), L2 **ground plane**, 0.014" core, L3 signal,
  two 2116 sheets, L4 the **+5V rail**, 0.014" core, L5 **ground plane**, two 2116
  sheets, L6 signal and ground flood. Order it Custom / Controlled
  Dielectric (their standard stackups are not guaranteed otherwise) with
  controlled impedance on the `USB` and `ETH` classes, and confirm both
  cores are 0.014".

## Mounting holes

Four M3, plated, on GND, centred **7 mm in from each corner**: (7, 7),
(133, 7), (7, 93), (133, 93), moved out from 10 mm on 2026-10-06 for 3 mm
more room inboard. A 6 mm standoff pad on each; the corner square of
10.5 mm around each hole carries nothing else. The edge connectors were
packed from 14 mm after each corner while the holes were at 10 mm and stay
where they are (their positions are locked in `gen/layout.py`).

## Edges and what faces where

The user sits at the **left** edge; the target is at the **right** edge; the
**front** long edge takes the overflow, each end matching its direction; the
**back** edge carries the RJ45 alone (2026-10-06: moved there from the left
edge so the two left-edge connectors, both USB-C then, could spread out
around the middle of the left edge and the lower-left corner stopped
crowding; the board no longer lies flat against a wall or a DIN rail, which
the spec accepted).

| Edge | Connectors, in order from the back corner to the front | Faces | Courtyards (measured) |
|---|---|---|---|
| Left (x = 0), 74 mm usable | J2 barrel power in (Kycon KLDX-0202-BC, 2.5 × 5.5 mm, through-hole, horizontal, centre positive: origin y = 30, its front face at the edge and its body 14.5 mm inboard, pins at y 30 and 34.7; a USB-C PD receptacle until 2026-10-10) · J1 USB-C upstream (centred y = 64; y = 74 until 2026-10-10, when it moved 10 mm up the edge toward the middle), split around the middle | adapter / workstation | 11.2 + 10.6 = 21.8 mm |
| Back (y = 0), 114 mm usable | J10 RJ45, from x = 45 (from x = 14 until 2026-10-07, when the PD inlet's two 5 V bucks took the back-edge corner beside J2; from x = 71 until 2026-10-10, when the bucks had gone and the jack and its PHY moved 26 mm back toward the corner to open the K64's side, the two reset buttons in a column beside the jack) | workstation | 19.0 mm wide, 22.4 mm deep |
| Right (x = 140), 74 mm usable | J3 USB-C HID (centred y = 19.3) · J13 console (origin y = 49.2) · J9 FTDI right-angle (origin y = 65.0), J13 moved 10 mm and J9 20 mm down the edge on 2026-10-07, leaving 11 mm between courtyards (they were packed 1.5 mm apart in the back half) | target | 10.6 + 16.5 + 16.3 = 43.4 mm |
| Front (y = 100), left end | J5, J4 USB-A stacks (J5 at x = 19, J4 at x = 37: swapped on 2026-10-06 so each stack's pairs reach the hub row they are wired to without crossing) · J18 PSU in (x = 56.4) · J19 PSU out (x = 70.7), both 2 mm right since 2026-10-08 so J4's shield pads stand 2.6 mm from the passthrough region (their copper still enters its 2 mm creepage band by 0.9 mm; the fills keep the creepage, DRC agrees) | bench / PSU | 17.2 + 17.2 + 13.2 + 13.2 = 60.8 mm |
| Front (y = 100), right end | J14 +5V_TGT · J12, J11 relays | target | 13.2 + 13.05 + 13.05 = 39.3 mm |
| Inboard | J16 Cortex debug · J15 GPIO header · J601 K20 SWD (J17, the PD programming header, top entry, until 2026-10-10) | any | — |

Four things moved from the spec's first table once the footprints were
measured (2026-10-06): the RJ45's courtyard runs 22 mm along the edge, not 16, so the left edge
could not also take J17, the PD programming header, which went inboard as a
top-entry part (and went altogether with the PD inlet on 2026-10-10); the
RJ45 then went to the back edge so J1 and J2 could spread;
**J19 sits beside J18** so the PSU passthrough is one compact isolated
region behind the two of them instead of a strip across the board; and J9
takes J19's place on the right edge, where an FTDI header facing the
target belongs anyway. Bodies are packed 1 mm apart from 14 mm after each
corner. Edge connectors sit with their mating face flush with the edge, or
on the footprint's own "PCB Edge" mark where it has one (the USB-C
receptacles overhang by 1.1 mm; the barrel jack's front face sits at the
edge). The mating face is the end of the body
farthest from the solder pins, which sit at the rear of every horizontal
connector in KiCad's library (the RJ45's long axis runs inboard, so it mates
along it); a pin header mates where its pins point. Checked in the 3D view.

## Keep-outs

- The 10.5 mm square at each corner (standoff pad and screw head): nothing
  but the hole, enforced as rule areas.
- **Isolation**: the PSU passthrough (J18, J19, K803's contact side, the
  opto-coupler's LED side, D807, R810, R811) sits in its own region behind
  J18/J19 at the front, x 50–86, y 62–100 (x 48–84 until 2026-10-08, y
  42–80 on the 80 mm board), with the barrier running through K803 between
  its coil and contact pins and through U801 between its LED and transistor
  pins, both at x = 66. A part of the region keeps the 2 mm creepage from
  every part and connector outside it by placement, and a board-net plane
  that enters the region's grown outline is refused at generation. It has its own **PSU_GND** copper on
  L2 with **no board ground plane under it**, and a 2 mm creepage gap to
  every board net, enforced by DRC rules (`sbc-baseboard.kicad_dru`: board
  nets' tracks and vias are kept out of the region, a board-net zone may not
  lie inside it, and the creepage clearance applies to every board-net item
  that carries a net; the relay's unused NC contact has no net and sits inside
  the region by placement). The L2 ground plane is drawn as one outline
  notched around the region from the front edge. Only the opto-coupler and
  the relay body cross the gap.
- **Lanes** (below): no part on a leg's own side inside its corridor, and
  none on either side around a lane via (standard 2.5, since 2026-10-10;
  until then both sides everywhere).
- Under J10: no plane or pour on any layer under the jack's body (its pins
  span the body, so the whole body is the void; the pins' tracks pass),
  drawn by the generator as the rule area `void_J10_magnetics` from
  `COPPER_VOIDS`.
- **Voids between cities** (standard 3.1): every two parts of different
  schematic islands on one side of the board keep 2 mm apart; the routing
  between blocks runs in those voids. The void holds per side, so a split
  channel's switch may sit under the other channel's. Connectors, holes, ESD parts and lone
  symbols at a connector stand outside the cities.
- No part other than an edge connector within 3 mm of any edge (a
  tailoring of ECSS-Q-ST-70-12C 14.3.2 c, whose 5 mm is for the assembler's
  conveyor; the assembler is consulted).
- Parent standard for everything not stated here: ECSS-Q-ST-70-12C Rev.1,
  with the tailorings listed in ecad-standards/layout.md section 0.

## Lanes

A lane is a corridor reserved for one routed path, from pad to pad through
axis-aligned legs, as wide as its class's track plus the class clearance plus
0.25 mm each side, kept free of parts on both sides of the board, and laid as
copper by the generator at the class width. Two lanes carry the PSU
passthrough (`LANES` in `gen/layout.py`):

| Lane | Net, class | Path |
|---|---|---|
| PSU_VP | PSU_VP, `PSU_3A` (2 mm) | J18 pin 1, up to y = 85, right to the x of K803 pin 6 (COM), up into the relay |
| PSU_VOUT | PSU_VOUT, `PSU_3A` (2 mm) | K803 pin 4 (NO), down to y = 93 under J19's body past its GND pin, left to the x of J19 pin 1, up into it |

PSU_GND goes from J18 pin 2 to J19 pin 2 through the PSU_GND island on L2.

The pairs are lanes too (standard, section 2 step 5 and section 3.8): the
generator lays both members at the class geometry, matched in length, with
the escapes, the receptacles' bridges and the layer changes it needs, and
refuses a lane whose members would cross. The ESD arrays and the series
parts are anchored so the lanes can be declared before placement.

| Pair lane | From | To | Path | Layer changes |
|---|---|---|---|---|
| J1_D | J1 (B7/A6 members; A7/B6 bridged behind the row) | U401 | direct | — |
| HUB_UP | U401 | U402 pins 59/58 | right to x = 15, up to the pins' row under the port pairs, right to x = 31.5 and into the hub | 2 (under HUB_DN6/DN7) |
| PORT1_D, PORT3_D | J4 / J5 front rows | U408 / U410 | direct, straight above their pads | — |
| PORT2_D, PORT4_D | J4 / J5 back rows | U409 / U411 | single-net lanes on the bottom through the front row's pin gaps, up to the array's pads | 1 each |
| HUB_DN4, HUB_DN5 | U408, U409 | U402 bottom row | up to y = 69, left, up (DN4); up to y = 67.5, left, up (DN5) | — |
| HUB_DN6, HUB_DN7 | U410, U411 | U402 left row | up the left of the hub, right into the row, nested, 1.2 mm apart | — |
| HUB_DN1 | U402 pins 2/1 | R602/R603 (hub side) | down to y = 66.6, under the port pairs on the bottom, up along x = 50.5, right across the band at y = 38.75 | 2 |
| K20_USB | R602/R603 | U601 pins 3/4 | right to x = 60, up to y = 41.7 over C605, right to x = 77.5, down past C603 and into the K20's left row, which faces the resistors since the hand pass (until 2026-10-10: right to x = 92 and back into the row from the east) | — |
| HUB_DN2 | U402 pins 4/3 | R505/R504 (hub side) | down to y = 65.6, under the port pairs, up along x = 52.1, right across the band at y = 54.8 below the DAPLink's crystal and above Q803, down at x = 112, right above the FTDI at y = 62, down at x = 126.6, left into the resistors (until 2026-10-10 the band was y = 41.5, through where the hand pass put the DAPLink; a band at y = 48 between the DAPLink and its crystal would have cut the crystal's and C602/C604's tracks off from the chip) | 2 |
| FTDI_USB | R505/R504 | U501 pins 11/12 | direct | — |
| J3_D | J3 (A7/A6 middle members; B7/B6 bridged at both ends of the row) | U202 | direct | — |
| K64_USB | U202 | U201 pins 10/11 | left, up to y = 6 along the back edge, left, down into the K64's top row | — |
| ETH_TD, ETH_RD | J10 pins 1/2, 3/6 | U301 pins 6/5, 4/3 | 100 Ω class ETH; TD jogs right to its pins, RD straight down | — |

Four arrays (U408 to U411) and U202 are drawn with the house symbol
USBLC6-2SC6-IO2up (D- on I/O2), because with their connector-side pins toward
the receptacle the pair would otherwise cross itself (standard 3.8); U401
keeps the stock symbol. The hub's two downstream pairs for the K20 and the
FTDI leave adjacent 0.5 mm pins: their centre lines are shifted 0.1 mm
apart and the FTDI pair turns first.
The VP leg at y = 85 keeps the 2 mm creepage to the opto-coupler's board-side
pins (y ≤ 82); the VOUT leg at y = 93 clears J19's GND pad by the class
clearance. The lanes' corridors stop at the courtyards of the parts they join
and appear in the board as footprint keep-out rule areas named `lane_*`, one
per leg on the leg's own layer, and `lane_*_via` on both layers around each
lane via. The USB 2.0 pairs get their lanes when the pairs are placed
(standard, section 8.3).

After the first hand pass (2026-10-10) the lanes were redrawn around the
hand-placed parts where a path exists: K20_USB and HUB_DN2 as in the table,
PORT2_D_N's bottom leg at x = 43.1 past U408 with its via at y = 81.9, and
the legs that only had bottom-side parts under them (C301 under the ETH
lanes; R211, R435 and D404 under HUB_DN6's vertical leg) are clear under
the per-side rule. No path exists into the hub's left column and bottom
row: its USB pairs and +3V3 pins alternate along both (pins 1-4, 8-9 and
11-12 with +3V3 at 5 and 10; pins 53-56 and 58-59 with +3V3 at 52 and 57),
so a decoupling capacitor laid against its pin on top (C403 and C406 under
the bottom row) sits across a pair's exit, where the pair's escape runs
1.2 mm straight past the pad tips (1.5 mm from the pad centres) before
it can turn; the crystal Y401 at (30, 61), at the XTAL pins 60/61 with its
load capacitor C416 above it, closes the left column's approach (the
engine had put the crystal at (31.9, 63.5), below HUB_UP's line, with C416
beside it); and R209 stands 0.4 mm into HUB_DN4's exit from U408. Those
lanes keep their straight paths and the report names the parts, with the
depth by which each corridor overlaps them.

## Planes

L2 (In1.Cu) and L5 (In4.Cu) are the ground planes, one outline each
notched around the isolation region, which holds its own PSU_GND island on
both and on the rail layer; L3 (In2.Cu) routes with the outer layers. L4 (In3.Cu) carries the
one heavy rail, +5V (class `PWR_4A`), as rectangles, referenced to L5
across the core (the autorouter's DSN reader takes no concave plane), each
at its own priority, the rail one piece (the standard's rails gate
rasterises each rail with the others carving it and stops on a rail in
pieces): from the jack's centre pin, the FET and the bulk capacitors in the
inlet corner (x 3–42, y 22–40) to the 3V3 buck's input (x 36–62, y 40–48),
down the middle beside the relay (x 48–64, y 48–80), along the band over the
port switches (x 10–48, y 70–83; their pads at y 78.5 to 80.5), across
above the region to the DAPLink's VBUS (x 62–100, y 45–57) and on to the
FTDI switch (x 86–126, y 52–57), down to the relays (x 88–108, y 57–82)
and the switch behind J9 (x 108–126, y 57–77), and to the eFuse's input
behind J14 (x 108–137, y 77–97), which +5V_TGT leaves as a track to J14.
One rail since 2026-10-10; until then three: VBUS_IN at 3 A in the inlet
corner under the two bucks' VIN pins and down to the PD controller's VBUS
parts, +5V_PORTS at 6 A from buck 1's inductor along the path the +5V rail
now takes, and +5V_TGT at 6 A from buck 2's inductor down to a band at
y 36–40, across it below the PHY to the right edge and down it to the eFuse
and J14. +3V3 is
routed, in its 0.6 mm `PWR_1A` class (0.5 mm on four layers; an inner 1 oz
track carries about half of an outer one; on six layers a plane for
it would cost the third routing layer, so it stays routed): before that an
+3V3 base lay under the rails in five pieces, and the three rails of the
time cut it into
three islands that no rail via or router track joined, with 16 of its 45
rail vias standing in copper another rail had carved away; on one rail
layer the two 6 A trees and the 3 A inlet left no planar room for a fourth
net. The generator drops the rail vias into the rail; the autorouter adds
its own; the hand pass joins the pads the report lists with no room.

## Floods and stitching

Ground floods both outer layers (`GND_F`, `GND_B`) on the plane's outline,
notched around the isolation region by the 2 mm creepage, and the region
floods its own `PSU_GND` on both outer layers inside its outline
(`PSU_GND_F`, `PSU_GND_B`), all at the lowest priority with thermal
reliefs. Ground stitching sits on a 5 mm grid, 1.5 mm in from the edge,
kept out of the isolation region grown by its creepage; the region's own
ground is stitched on the same grid inside its outline inset by the
creepage. Vias are 0.6 mm on a 0.3 mm drill. The standard's `copper.py`
draws all of it over the routed board (`gen/pcb.py --copper`), moving a
via to the nearest clear spot where the routing is in the way, dropping one
that would cut a sliver off a rail or that the filled floods reach on fewer
than two layers, and adding one inside any pour island that holds a ground
pad but no via. Before the router, the generator drops **rail vias** beside
every SMD pad on a plane net (`RAIL_VIAS`: three for `PWR_4A`, two for the
3 A classes `USB_VBUS_3A` and `PSU_3A`, one otherwise; three for `PWR_6A`
until 2026-10-10), joined by a stub at the class width or the pad's narrower side, and
reports the pads the packed rings leave no room beside.

## Sides

Connectors, ICs, relays, inductors, crystals and their load capacitors,
switches, jumpers, LEDs, test points, the bulk and large capacitors, the
parts of the 3V3 buck's switching loop, the ESD arrays and the series parts on
the USB pairs, and every part on a `USB_VBUS_3A`, `PWR_4A` or `PSU_3A` net
stay on the **top**. Resistors and capacitors up to 1206, small diodes
(SOD-123) and SOT-23 transistors may go to the **bottom**, under the pin they
serve, 1 mm inside their host's courtyard edge, never within 1 mm of a
through-hole pad (hand soldering) or 0.6 mm of an exposed pad's via field.
The two stacked USB-A receptacles each carry two ports: the back rows'
load switches (U404, U406) and their capacitors go to the **bottom**
(`SIDES`, standard 3.7, 2026-10-07), the front rows' (U403, U405) stay on
top with the ESD arrays, so the area in front of each stack holds one
port's switch per side; the ports' indicator LEDs and their series
resistors stay on top. The corner keep-outs, the 3 mm edge zone, the lanes
and the isolation rule apply on both sides. The bottom carries nothing
taller than 3 mm (the standoffs). The area this frees on top is for the
blocks' copper zones.
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

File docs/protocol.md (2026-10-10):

# Console protocol

One ASCII command per line, one reply line starting `OK` or `ERR`. Verbs and
arguments are case-insensitive, `\n` and `\r\n` both work, blank lines are
ignored silently. This is the convention `qtpy-relay-controller` and
`frdm-k64f-hid` already use, so existing host tooling and shell idioms carry
over.

Identical over all three transports:

| Transport | Address | Notes |
|---|---|---|
| USB CDC | DAPLink on hub port 7, via J1 | 115200 baud, nominal — it is a CDC port |
| TCP | J10, port 7373 (configurable) | Several control sessions may be open at once |
| — | J16 SWD | Not a console; debug only |

Commands are atomic single lines, so interleaved control sessions cannot corrupt
each other. `CONSOLE` attach is the exception and is exclusive — see below.

> **There is no authentication.** Anything that can reach port 7373 can cut
> power to the target and assert its recovery pins. Put the management port on a
> trusted segment. Adding auth is [open question 8](hardware-spec.md#8-open-questions).

---

## Switching

| Command | Effect |
|---|---|
| `PORT <1-4\|ALL> ON\|OFF\|TOGGLE` | Power a USB-A port |
| `PORT <n\|ALL> PULSE [ON\|OFF] <ms>` | Invert (or force a state) for *ms*, then revert |
| `PORT <n>` | Report one port |
| `RELAY <1-2\|ALL> ON\|OFF\|TOGGLE` | Energize a relay coil |
| `RELAY <n\|ALL> PULSE [ON\|OFF] <ms>` | As above |
| `RELAY <n>` | Report one relay |
| `TGT 5V ON\|OFF\|TOGGLE` | The board's switched +5V_TGT rail on J14 |
| `TGT PSU ON\|OFF\|TOGGLE` | The external PSU passthrough, J18 → J19 |
| `TGT 5V\|PSU PULSE OFF <ms>` | Hold that supply dark for *ms* |
| `TGT CYCLE [5V\|PSU] [<ms>]` | `PULSE OFF` on one supply, or both if none is named. Default 5000 ms |
| `TGT` | Report both supplies |
| `FTDI ON\|OFF\|TOGGLE` | VBUS to the FT231X behind J9 |
| `FTDI CYCLE [<ms>]` | Power-cycle it, default 2000 ms; it re-enumerates on the workstation |
| `FTDI` | Report it |

Pulses are non-blocking and several can run at once; the console stays
responsive throughout, and the revert happens even if the host wanders off. A
pulse reverts to whatever the channel was set to beforehand, so `PULSE ON 500`
on something that was off returns it to off. Setting a channel outright cancels
any pulse still running on it. Range is 1–3600000 ms.

`ON` always means *the thing the channel exists to do is happening*: a port is
powered, the target is powered, a relay is energized. Which way a relay's
contacts run at that point is a wiring choice — SPDT gives you NO and NC on the
terminal block — so the protocol does not need to know.

`TGT PSU ON` energizes the passthrough relay and the target powers; de-energized
is off, which is also what an unpowered baseboard does. Firmware restores the
last commanded state at boot ([spec, open question 13](hardware-spec.md#8-open-questions)),
so a baseboard reset is a brief power cut to the target rather than a change of
state. A `PULSE` in flight across a reset is lost; the channel comes back to its
pre-pulse state.

`FTDI` is deliberately not `PORT 6`, though that is the hub port it sits on.
`PORT ALL OFF` does not touch it: the bridge you are reading the boot log on
must not be swept away by a script that is clearing the bench. `FTDI CYCLE`
exists for one reason — a USB-UART bridge that stays enumerated and openable
while delivering nothing, which the bench notes record happening and being
misread as a dead target.

`TGT CYCLE` with no supply named cycles both. A target uses one of the two, so
cycling the other is a no-op — and if a target ever uses both, cycling both is
the only thing that is actually a power cycle.

### There is no bare `ON` or `OFF`

`qtpy-relay-controller` accepts `OFF 3`, because on that board there was only
one kind of channel. Here there are three, and they do very different things:

```
> OFF 3
ERR AMBIGUOUS say PORT, RELAY or TGT
```

Guessing would mean a script written for the old board silently cutting the
target's power instead of a USB port. Refusing costs one edit per script and
cannot do that.

Note also that **`RELAY` means the two SPDT contacts, not USB power.** On the
old board `RELAY` addressed what were physically relays switching USB port
power; here those are `PORT`.

---

## Target console

| Command | Effect |
|---|---|
| `CONSOLE` | Attach this session to the target's UART. Escape with `~.` at line start |
| `CONSOLE BAUD <n>` | Set the target UART rate, persisted |
| `CONSOLE TAIL [<n>]` | Last *n* lines from the ring buffer, default 40 |
| `CONSOLE CLEAR` | Empty the ring buffer |

The MCU captures the target's console into a ring buffer continuously, whether
or not anyone is attached. So a boot that failed overnight is still readable in
the morning, and `CONSOLE TAIL` composes in a script — which an attached
interactive session does not.

Only one session may be attached at a time; a second gets
`ERR CONSOLE BUSY <transport>`.

This is J13. The other console, J9, is an FT231X that the workstation talks to
directly as a serial device; it has no commands here beyond `FTDI`.

---

## HID to the target

Unchanged from `frdm-k64f-hid` — the target sees a plain USB keyboard and mouse
on J3 and cannot tell the difference between this and someone at a keyboard.

| Command | Effect |
|---|---|
| `TYPE <text>` | Type the rest of the line literally, case preserved |
| `KEY <combo>` | Press and release, e.g. `KEY ctrl+alt+t` |
| `KEYDOWN <combo>` / `KEYUP <combo>` | Press and hold / release |
| `RELEASE` | Release every held key and button |
| `MOUSE MOVE <dx> <dy>` | Relative move, −127..127 per report |
| `MOUSE SCROLL <n>` | Wheel clicks |
| `MOUSE CLICK\|DOWN\|UP <button>` | `left`, `right` or `middle` |

`ERR USB NOT READY` means the target has not configured the HID interfaces.

---

## Breakout header

| Command | Effect |
|---|---|
| `GPIO <1-6> HIGH\|LOW\|IN` | Drive or release a breakout pin |
| `GPIO <n>` | Read one pin |
| `I2C SCAN` | Addresses present on the target bus |
| `I2C READ <addr> <reg> [<len>]` | Default length 1 |
| `I2C WRITE <addr> <reg> <byte>...` | |

The header's outputs are **push-pull** — a TXB0108 cannot drive an open-drain
net, and an external pull-up below ~50 kΩ will fight it. `HIGH` and `LOW` drive;
`IN` releases to high-impedance, which is the closest thing to open-drain the
translator can do.

Levels follow J13's VREF. With the target unpowered, VREF is 0 V, the translator
is disabled, and `GPIO` returns `ERR NO VREF` rather than pretending.

---
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

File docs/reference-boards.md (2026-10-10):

# Reference boards: measured placement practice

Why this exists: the layout engine (`hardware/kicad/gen/pcb.py`) and the
layout standard ([ecad-standards/layout.md](https://github.com/calicopizzadelivery/ecad-standards/blob/main/layout.md))
carry numbers (ring gaps, tuck depths, text sizes, side rules). Rather than
guess them, we measure them on boards that other people laid out well and
published in KiCad, and we set the standard from the measurement, so every
project after this one starts from the same calibrated rules.
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

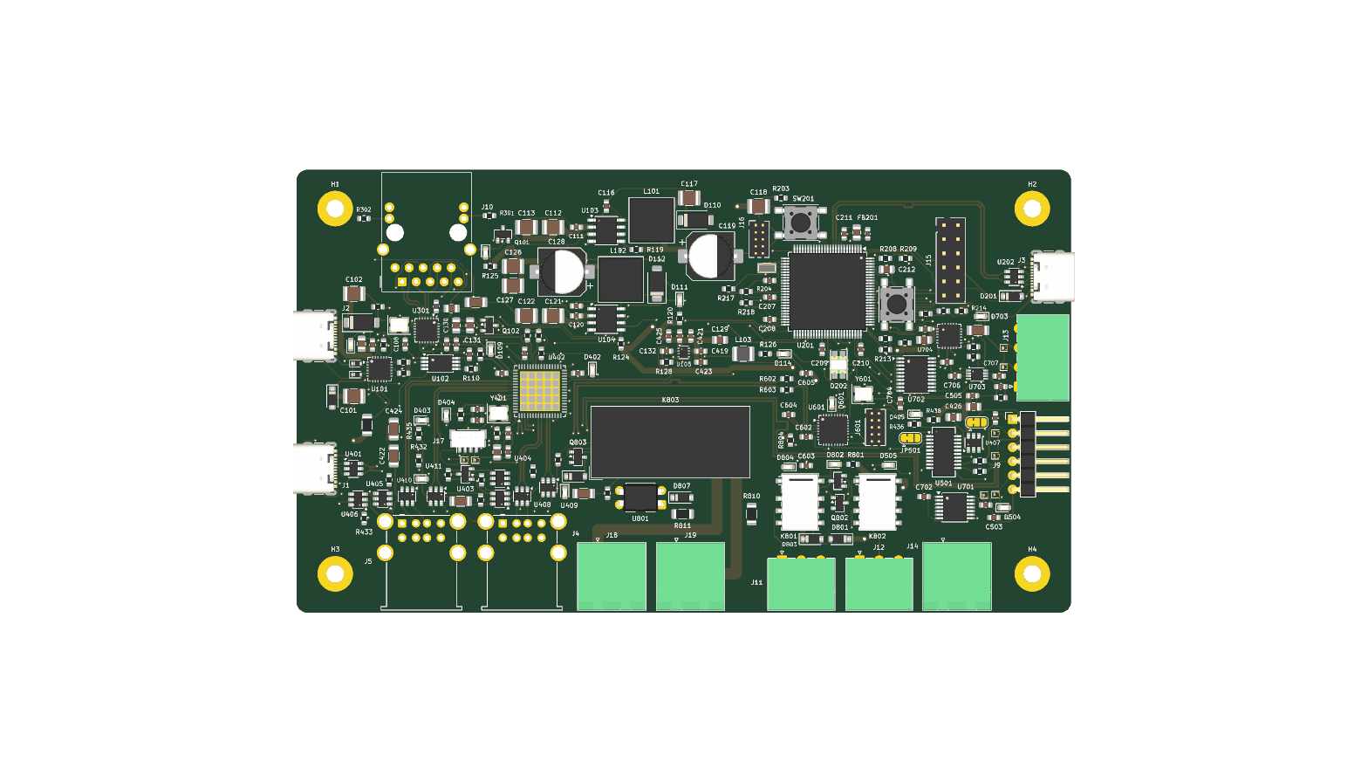
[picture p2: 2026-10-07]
docs/board-first-placement.png

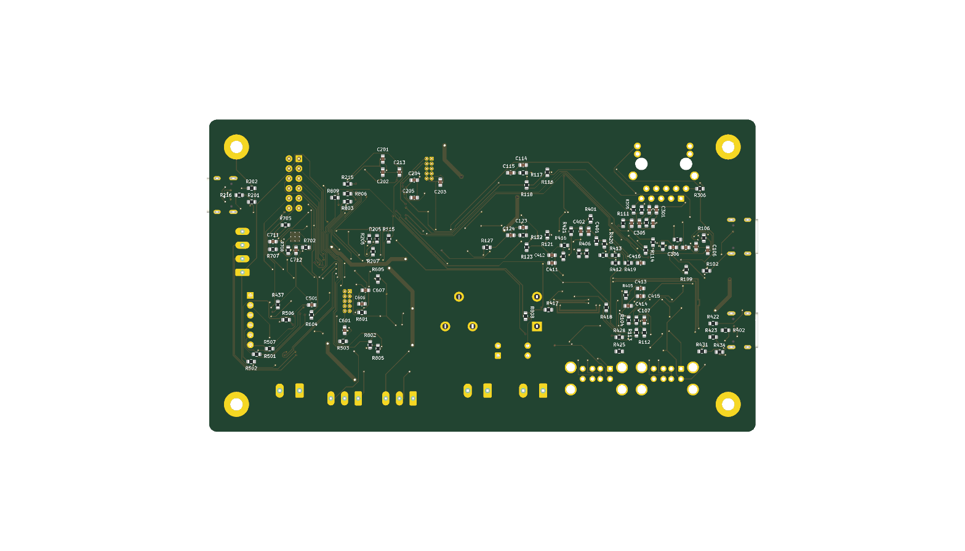
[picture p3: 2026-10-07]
docs/board-first-placement-bottom.png

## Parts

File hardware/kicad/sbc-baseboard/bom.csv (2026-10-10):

Reference | Value | Footprint | QUANTITY
C101,C102 | 47u/10V | Capacitor_SMD:C_1210_3225Metric | 2
C103 | 100u/10V | Capacitor_SMD:CP_Elec_8x10.5 | 1
C104,C206,C207,C208,C209,C210,C211,C213,C301,C302,C305,C309,C310,C403,C404,C405,C406,C407,C408,C409,C412,C414,C417,C419,C421,C423,C425,C501,C505,C601,C603,C604,C701,C702,C703,C704,C705,C706,C707,C708 | 100n | Capacitor_SMD:C_0603_1608Metric | 40
C105,C212,C214,C426,C504,C709 | 10u | Capacitor_SMD:C_0805_2012Metric | 6
C106,C107,C308 | 22u | Capacitor_SMD:C_0805_2012Metric | 3
C108 | 120p | Capacitor_SMD:C_0603_1608Metric | 1
C201,C202,C304,C602,C605 | 2u2 | Capacitor_SMD:C_0603_1608Metric | 5
C203,C401,C402,C411,C413 | 1u | Capacitor_SMD:C_0603_1608Metric | 5
C204,C205 | 12p | Capacitor_SMD:C_0603_1608Metric | 2
C303 | 1n/2kV | Capacitor_SMD:C_1206_3216Metric | 1
C306,C307 | 22p | Capacitor_SMD:C_0603_1608Metric | 2
C410 | 4u7 | Capacitor_SMD:C_0805_2012Metric | 1
C415,C416 | 33p | Capacitor_SMD:C_0603_1608Metric | 2
C418,C420,C422,C424,C710 | 22u | Capacitor_SMD:C_1206_3216Metric | 5
C502,C503 | 47p | Capacitor_SMD:C_0603_1608Metric | 2
C606,C607 | 18p | Capacitor_SMD:C_0603_1608Metric | 2
C711 | 1n | Capacitor_SMD:C_0603_1608Metric | 1
C712 | 10n | Capacitor_SMD:C_0603_1608Metric | 1
D101 | SMAJ5.0A | Diode_SMD:D_SMA | 1
D102,D103 | LED AMBER | LED_SMD:LED_0603_1608Metric | 2
D201 | BAT54 | Diode_SMD:D_SOD-123 | 1
D202 | RGB heartbeat | LED_SMD:LED_RGB_1210 | 1
D401,D402,D403,D404,D405,D504,D505,D601,D703 | LED GREEN | LED_SMD:LED_0603_1608Metric | 9
D501,D502,D503,D506,D701,D702 | PESD5V0S1UL | Diode_SMD:D_SOD-882 | 6
D801,D803,D805,D807 | 1N4148W | Diode_SMD:D_SOD-123 | 4
D802,D804,D806 | LED RED | LED_SMD:LED_0603_1608Metric | 3
FB201,FB301 | 600R@100MHz | Inductor_SMD:L_0603_1608Metric | 2
H1,H2,H3,H4 | M3 | MountingHole:MountingHole_3.2mm_M3_Pad | 4
J1 | USB-C upstream | calico:USB_C_Receptacle_GCT_USB4105-xx-A_16P_TopMnt_Horizontal_PegClear | 1
J2 | 5 V in, 2.5 mm | Connector_BarrelJack:BarrelJack_Kycon_KLDX-0202-xC_Horizontal | 1
J3 | USB-C HID to target | calico:USB_C_Receptacle_GCT_USB4105-xx-A_16P_TopMnt_Horizontal_PegClear | 1
J4,J5 | USB-A x2 | Connector_USB:USB_A_Wuerth_61400826021_Horizontal_Stacked | 2
J9 | FTDI header | Connector_PinHeader_2.54mm:PinHeader_1x06_P2.54mm_Horizontal | 1
J10 | RJ45 magjack 10/100 | Connector_RJ:RJ45_Kycon_G7LX-A88S7-BP-xx_Horizontal | 1
J11,J12 | COM/NO/NC | Connector_Phoenix_MC:PhoenixContact_MC_1,5_3-G-3.5_1x03_P3.50mm_Horizontal | 2
J13 | Console | Connector_Phoenix_MC:PhoenixContact_MC_1,5_4-G-3.5_1x04_P3.50mm_Horizontal | 1
J14 | +5V_TGT out | Connector_Phoenix_MSTB:PhoenixContact_MSTBA_2,5_2-G-5,08_1x02_P5.08mm_Horizontal | 1
J15 | GPIO + I2C | Connector_PinHeader_2.54mm:PinHeader_2x06_P2.54mm_Vertical | 1
J16 | SWD | Connector_PinHeader_1.27mm:PinHeader_2x05_P1.27mm_Vertical | 1
J18 | PSU in (isolated) | Connector_Phoenix_MSTB:PhoenixContact_MSTBA_2,5_2-G-5,08_1x02_P5.08mm_Horizontal | 1
J19 | PSU out (isolated) | Connector_Phoenix_MSTB:PhoenixContact_MSTBA_2,5_2-G-5,08_1x02_P5.08mm_Horizontal | 1
J601 | SWD (K20) | Connector_PinHeader_1.27mm:PinHeader_2x05_P1.27mm_Vertical | 1
JP501 | RTS/DTR | Jumper:SolderJumper-3_P1.3mm_Bridged12_RoundedPad1.0x1.5mm | 1
JP502 | VCC 5V/3V3 | Jumper:SolderJumper-3_P1.3mm_Bridged12_RoundedPad1.0x1.5mm | 1
K801,K802 | G6K-2F-Y DC5 | Relay_SMD:Relay_DPDT_Omron_G6K-2F-Y | 2
K803 | JW1FSN-DC5V | Relay_THT:Relay_SPDT_Panasonic_JW1_FormC | 1
L101 | 470n/4A | Inductor_SMD:L_1210_3225Metric | 1
Q101 | DMP3013SFV | Package_SON:Diodes_PowerDI3333-8 | 1
Q801,Q802 | 2N7002 | Package_TO_SOT_SMD:SOT-23 | 2
Q803 | AO3400A | Package_TO_SOT_SMD:SOT-23 | 1
R101,R309,R310,R426,R429,R432,R435,R438,R705,R803,R806,R809 | 1k | Resistor_SMD:R_0603_1608Metric | 12
R102,R104,R216,R401,R402,R701,R802,R805,R808 | 100k | Resistor_SMD:R_0603_1608Metric | 9
R103,R501,R502,R503,R507,R605 | 470 | Resistor_SMD:R_0603_1608Metric | 6
R105 | 453k | Resistor_SMD:R_0603_1608Metric | 1
R201,R202,R422,R423 | 5.1k | Resistor_SMD:R_0603_1608Metric | 4
R203,R204,R208,R209,R210,R211,R214,R308,R403,R405,R406,R407,R408,R409,R410,R411,R412,R413,R414,R415,R416,R417,R418,R419,R420,R421,R424,R427,R430,R433,R436,R506,R601,R604,R704,R706,R812 | 10k | Resistor_SMD:R_0603_1608Metric | 37
R205,R206,R207,R301,R302 | 330 | Resistor_SMD:R_0603_1608Metric | 5
R212,R213 | 4.7k | Resistor_SMD:R_0603_1608Metric | 2
R215 | 47k | Resistor_SMD:R_0603_1608Metric | 1
R303,R304,R305,R306 | 75 | Resistor_SMD:R_0603_1608Metric | 4
R307,R602,R603 | 33 | Resistor_SMD:R_0603_1608Metric | 3
R311 | 6.49k 1% | Resistor_SMD:R_0603_1608Metric | 1
R404 | 12.0k 1% | Resistor_SMD:R_0603_1608Metric | 1
R425,R428,R431,R434,R437 | 23.7k | Resistor_SMD:R_0603_1608Metric | 5
R504,R505 | 27 | Resistor_SMD:R_0603_1608Metric | 2
R702 | 75k | Resistor_SMD:R_0603_1608Metric | 1
R703 | 196k | Resistor_SMD:R_0603_1608Metric | 1
R707 | 20k | Resistor_SMD:R_0603_1608Metric | 1
R708 | 6.04k 1% | Resistor_SMD:R_0603_1608Metric | 1
R801,R804,R807 | 2.2k | Resistor_SMD:R_0603_1608Metric | 3
R810,R811 | 1.8k | Resistor_SMD:R_1206_3216Metric | 2
SW201 | RESET | Button_Switch_SMD:SW_SPST_PTS645Sx43SMTR92 | 1
SW601 | DAP RESET | Button_Switch_SMD:SW_SPST_PTS645Sx43SMTR92 | 1
U105 | TPS62823DLC | Package_SON:Texas_VSON-HR-8_1.5x2mm_P0.5mm | 1
U201 | MK64FN1M0VLL12 | Package_QFP:LQFP-100_14x14mm_P0.5mm | 1
U202,U401,U408,U409,U410,U411 | USBLC6-2SC6 | Package_TO_SOT_SMD:SOT-23-6 | 6
U301 | KSZ8081RNA | Package_DFN_QFN:QFN-24-1EP_4x4mm_P0.5mm_EP2.6x2.6mm | 1
U402 | USB2517 | Package_DFN_QFN:QFN-64-1EP_9x9mm_P0.5mm_EP7.15x7.15mm | 1
U403,U404,U405,U406,U407 | TPS2553DBV | Package_TO_SOT_SMD:SOT-23-6 | 5
U501 | FT231XS | Package_SO:SSOP-20_3.9x8.7mm_P0.635mm | 1
U601 | MK20DX128VFM5 | Package_DFN_QFN:QFN-32-1EP_5x5mm_P0.5mm_EP3.45x3.45mm | 1
U701 | TXB0104PW | Package_SO:TSSOP-14_4.4x5mm_P0.65mm | 1
U702 | TXB0108PW | Package_SO:TSSOP-20_4.4x6.5mm_P0.65mm | 1
U703 | TXS0102DCU | Package_SO:VSSOP-8_2.3x2mm_P0.5mm | 1
U704 | TPS26630RGE | Package_DFN_QFN:Texas_RGE0024H_VQFN-24-1EP_4x4mm_P0.5mm_EP2.7x2.7mm_ThermalVias | 1
U801 | LTV-817 | Package_DIP:DIP-4_W7.62mm | 1
Y201 | 32.768kHz | Crystal:Crystal_SMD_3215-2Pin_3.2x1.5mm | 1
Y301 | 25MHz | Crystal:Crystal_SMD_3225-4Pin_3.2x2.5mm | 1
Y401 | 24MHz | Crystal:Crystal_SMD_3225-4Pin_3.2x2.5mm | 1
Y601 | 8MHz | Crystal:Crystal_SMD_3225-4Pin_3.2x2.5mm | 1

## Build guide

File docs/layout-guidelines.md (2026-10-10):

# Layout guidelines from the ICs' datasheets

What each part's maker says about placing it, with the source, and how the
board meets it. Rule 3.2 of
[ecad-standards/layout.md](https://github.com/calicopizzadelivery/ecad-standards/blob/main/layout.md):
best effort, written down; a row that is not met says why. Status is
*planned* until the board is routed, then *met* or *not met (reason)*.

| Part | Guideline (source) | On this board | Status |
|---|---|---|---|
| **USBLC6-2SC6** U202, U401, U408–U411 | Flow-through ESD array for USB 2.0: placed as close as possible to the connector, the pair routed through the device (connector-side pins 1/3, device-side pins 6/4) with no stub, ground pin to the plane by a via, the pair kept at its impedance through it (ST USBLC6-2 datasheet, application information; st.com unreachable to the fetcher, wording to confirm against the PDF). | Generated placement puts each array first, on top, in the receptacle's first ring at its D+/D- pins, pins 1/3 toward the receptacle; both nets of each pair are in the `USB` class (0.33 / 0.20 mm, 90 Ω on the six-layer stackup); ecad-standards/layout.md 3.8. | planned |
| **PESD5V0S1UL** D501–D503, D506, D701, D702 | Single-line ESD at the connector, the protected trace passing the diode, short ground return (Nexperia datasheet, application information). | At J9's and J13's pins, first ring, on top, pad toward the pin. | planned |
| **KLDX-0202-BC** J2, **SMAJ5.0A** D101, **DMP3013SFV** Q101 | The inlet (2026-10-10; a USB-C PD receptacle, the STUSB4500 and two TPS54560B bucks until then): the jack's front face at the board edge with its pins at the rear (the Kycon drawing); the TVS at the jack's pin like any ESD part, first, on top, its ground pad to the plane by a via (standard 3.8); the reverse-polarity pass FET in the rail directly behind the jack with its gate pull-down at the gate pin and the bulk capacitors at its source, the current path short and wide (the DMP3013SFV datasheet has no layout figure: a pass FET needs none). | J2 at (13.9, 30) on the left edge; D101 at (19.3, 34) in J2's first ring at the centre pin, on top; Q101 anchored at (20, 30), drain at the jack, source on +5V; C103 100 nF in its first ring and C101/C102 47 µF at (12, 22.7) and (7.3, 22.8) on the rail side, R102 100 kΩ on the bottom under the gate pin, the amber LED and R101 at (13, 20); the +5V rail leaves the corner as an L4 rectangle (x 3–42, y 22–40, class `PWR_4A`) | planned |
| **TPS62823** U105 | Input capacitor(s) as close as possible to VIN and PGND; SW connection to the inductor short; the VOUT regulation loop (COUT and its ground) short; the FB divider close to FB and AGND. (datasheet SLVSDV6C §11.1) | a city above the hub, where the +5V rail's inlet rectangle hands to the next (at buck 1's output until 2026-10-10), placed from Figure 52 as a template (standard 3.2, `LAYOUTS["TPS62823"]`): input 10 µF 1.7 mm from VIN beside the inductor on the power-pin side, inductor 5.8 mm from SW (the figure butts it to the IC; the XAL inductor's courtyard sets ours), output 22 µF 4.8 and 7.0 mm at the inductor's output, divider and feed-forward at FB on the opposite side, all top side | planned |
| **TPS2553** U403–U407 | 100 nF bypass near IN and GND with a low-inductance trace; bulk plus 100 nF on OUT for transient loads; RILIM trace as short as possible; PowerPAD to the ground plane with wide short copper. (datasheet SLVS841F §12.1) | each switch between its hub pins and its receptacle; 100 nF at IN, 22 µF at OUT, RILIM at the pin | planned |
| **TPS2663** U704 | 0.1 µF or more from IN_SYS to GND, loop minimised; high-current path short and sized for at least twice full load; RILIM, dVdT, IMON, UVLO, OVP, PGTH parts at their pins with short ground returns; RILIM trace short and away from switching signals; protection parts at OUT and GND; PowerPAD soldered to the ground plane under the device. (datasheet SLVSE94G §9.6.1) | target group behind J14; the +5V rail reaches IN as an L4 rectangle (x 108–137, y 77–97) and +5V_TGT leaves OUT to J14 as a track, both in class `PWR_4A` (2.5 mm, 1.0 mm / 0.5 mm vias, three rail vias per pad); RILIM 6.04 kΩ for 3 A (2026-10-10; a `PWR_6A` polygon and 3.65 kΩ for 5 A until then) | planned |
| **USB2517** U402 | All GND to one solid ground plane, no separate planes. 0.1 µF at each VDDA33 pin (5, 10, 52, 57) plus 1 µF shared; 1 µF + 0.1 µF at VDD33CR (24); 0.1 µF at VDD33 (46); 0603 or smaller. RBIAS 12 kΩ 1 % as close to pin 63 as possible with a dedicated low-impedance ground. Crystal: load capacitors at XTAL1/XTAL2 to ground, values from the crystal's CL and stray capacitance. TVS on the same layer as the USB trace, vias behind it, 5 pF budget for connector, trace and protection; USB connector GND straight to a large ground plane. (Hardware Design Checklist DS00004211A §2.3, 3.0, 4.2, 6.1, 7.1) | one ground plane on L2; decoupling per pin from the schematic; RBIAS at pin 63; crystal cluster at pins 60/61; ESD arrays at each receptacle on L1 | planned |
| **KSZ8081RNA** U301 | VDD_1.2: 2.2 µF + 0.1 µF; VDDA_3.3 from the 3.3 V rail through a ferrite bead with 22 µF + 0.1 µF; VDDIO 22 µF + 0.1 µF. Magnetics: the PHY-side centre taps not connected to any supply, each to ground through its own 0.1 µF, TX and RX centre taps separate; cable-side TX centre tap through 75 Ω and 1 nF/2 kV to chassis. Continuous ground plane under the PHY and the traces to the magnetics, no other signals through the area; TX/RX as 100 Ω pairs, length matched. (datasheet DS00002199E §3.11, §11; Microchip application notes) | magnetics inside J10 (magjack); the PHY beside the jack with the pairs straight in; no copper on any layer under the jack's magnetics side | planned |
| **FT231XS** U501 | USB D+/D− as a matched pair with the 27 Ω series resistors and 47 pF close to the pins; 3V3OUT decoupled with 100 nF close to the pin; VCC decoupling at the pin; solid ground. (datasheet DS_FT231X §6; AN_146 USB Hardware Design Guidelines, to be read: the site blocks automated fetches) | FTDI group behind J9; pair from the hub side, series parts at the pins | planned, source to confirm |
| **MK64FN1M0VLL12** U201, **MK20DX128VFM5** U601 | 100 nF at every VDD pin, bulk nearby; VDDA through the ferrite with its own capacitors; VREFH decoupled; crystal next to EXTAL/XTAL with the load capacitors between; USB pair direct to the ESD array. (FRDM-K64F reference design; Kinetis hardware design guidelines) | decoupling per pin from the schematic; crystals in their clusters | planned |
| **USBLC6-2SC6** U202, U401, U408–U411 | In line with the pair next to the receptacle, on the pair's layer, ground pin straight to the plane. (USB2517 checklist §4.2 for any TVS) | each at its receptacle | planned |
| **G6K-2F-Y** K801, K802; **JW1FSN** K803; **LTV-817** U801 | Creepage across the contact-to-coil and LED-to-transistor barriers per the parent's insulation distances; the isolated region's rules in the directives (2 mm). | barrier through the relay and opto bodies, DRC rule | planned |
| **Phoenix MC / MSTB**, USB-A, USB-C, RJ45 | Plug entry at the edge, body flush or on the footprint's edge mark; the pins at the rear. | generator rule, 3D check | planned |

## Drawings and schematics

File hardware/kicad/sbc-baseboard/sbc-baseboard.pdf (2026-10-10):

1 | 2 | 3 | 4 | 5 | 6 | 7 | 8

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
Size: A3 | Rev: 0.1
KiCad E.D.A. 10.0.6 | Id: 1/9 | F Date: 2026-10-03

## Title: SBC development baseboard

### File: sbc-baseboard.kicad_sch

### Sheet: /

### sbc-development-baseboard

### 140 x 80 mm, four M3. Spec: docs/hardware-spec.md

USB hub

File: hub.kicad_sch

Target I/O

File: target.kicad_sch

Relays File: relays.kicad_sch Power File: power.kicad_sch | MCU

File: mcu.kicad_sch

FTDI File: ftdi.kicad_sch | DAPLink File: daplink.kicad_sch
Ethernet File: ethernet.kicad_sch H2M3 H1M3 | H3M3 | H4M3 GND | GND | GND | GND Reference designators: 1xx power, 2xx MCU, 3xx Ethernet, 4xx hub, 5xx FTDI, 6xx DAPLink, 7xx target I/O, 8xx relays and passthrough. - KSZ8081 crystal load (22 pF) and 50 MHz REF_CLK series resistor - USB2517 VBUS_DET divider (10k/22k) vs the EVB; LED_A/B strap pull-downs

VERIFY BEFORE FAB (also in docs/hardware-spec.md section 8): - TPS2553 ILIM at bring-up; TPS26630 UVLO/ILIM (6.04k -> 3 A); the inlet FET's drop at 4 A - DAPLink K20: pins verified against DAPLink k20dx and the FRDM-K64F OpenSDA circuit; confirm SWD at bring-up

switched +5V_TGT eFuse, and an isolated PSU passthrough on a 5 A relay. 5 V 4 A in on a 2.5 mm barrel jack. 140 x 100 mm, six layers.

One board for remote development on an attached SBC: K64 as USB HID to the target and Ethernet to the workstation,

### SBC DEVELOPMENT BASEBOARD - schematic first pass, generated 2026-10-04

four switched USB-A ports, FT231X FTDI header, two isolated SPDT signal relays, level-shifted console and GPIO/I2C, - K803 JW1FSN contact pad mapping (COM 6 / NO 4 / NC 2) against the Panasonic drawing

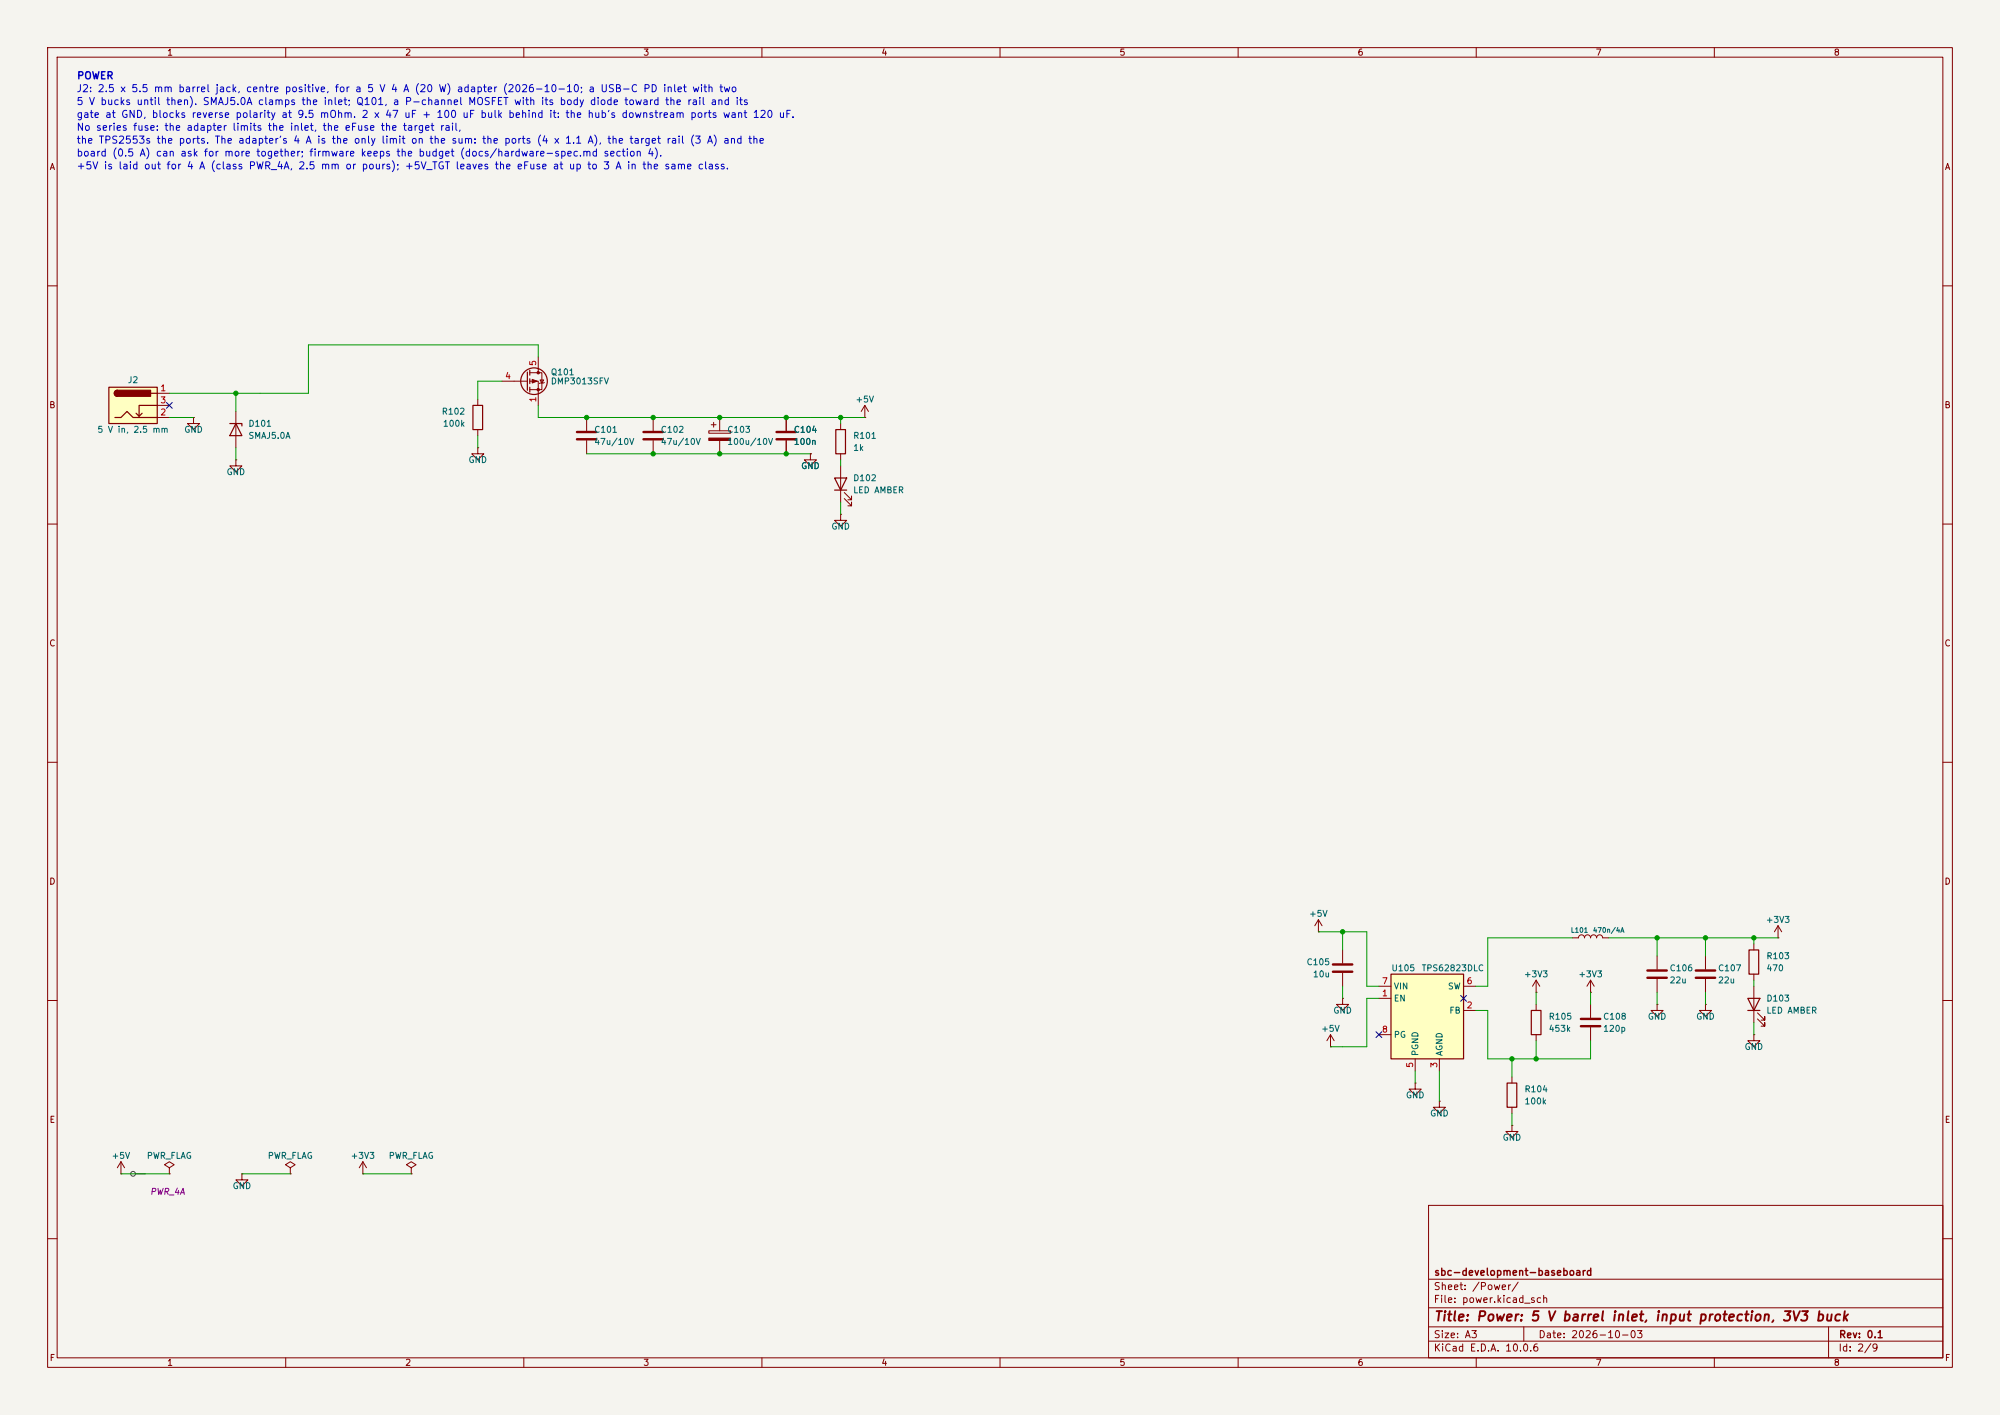
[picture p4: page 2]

POWER
J2: 2.5 x 5.5 mm barrel jack, centre positive, for a 5 V 4 A (20 W) adapter (2026-10-10; a USB-C PD inlet with two
gate at GND, blocks reverse polarity at 9.5 mOhm. 2 x 47 uF + 100 uF bulk behind it: the hub's downstream ports want 120 uF.
No series fuse: the adapter limits the inlet, the eFuse the target rail,
the TPS2553s the ports. The adapter's 4 A is the only limit on the sum: the ports (4 x 1.1 A), the target rail (3 A) and the
board (0.5 A) can ask for more together; firmware keeps the budget (docs/hardware-spec.md section 4).
+5V is laid out for 4 A (class PWR_4A, 2.5 mm or pours); +5V_TGT leaves the eFuse at up to 3 A in the same class.

sbc-development-baseboard
Sheet: /Power/
File: power.kicad_sch
Title: Power: 5 V barrel inlet, input protection, 3V3 buck

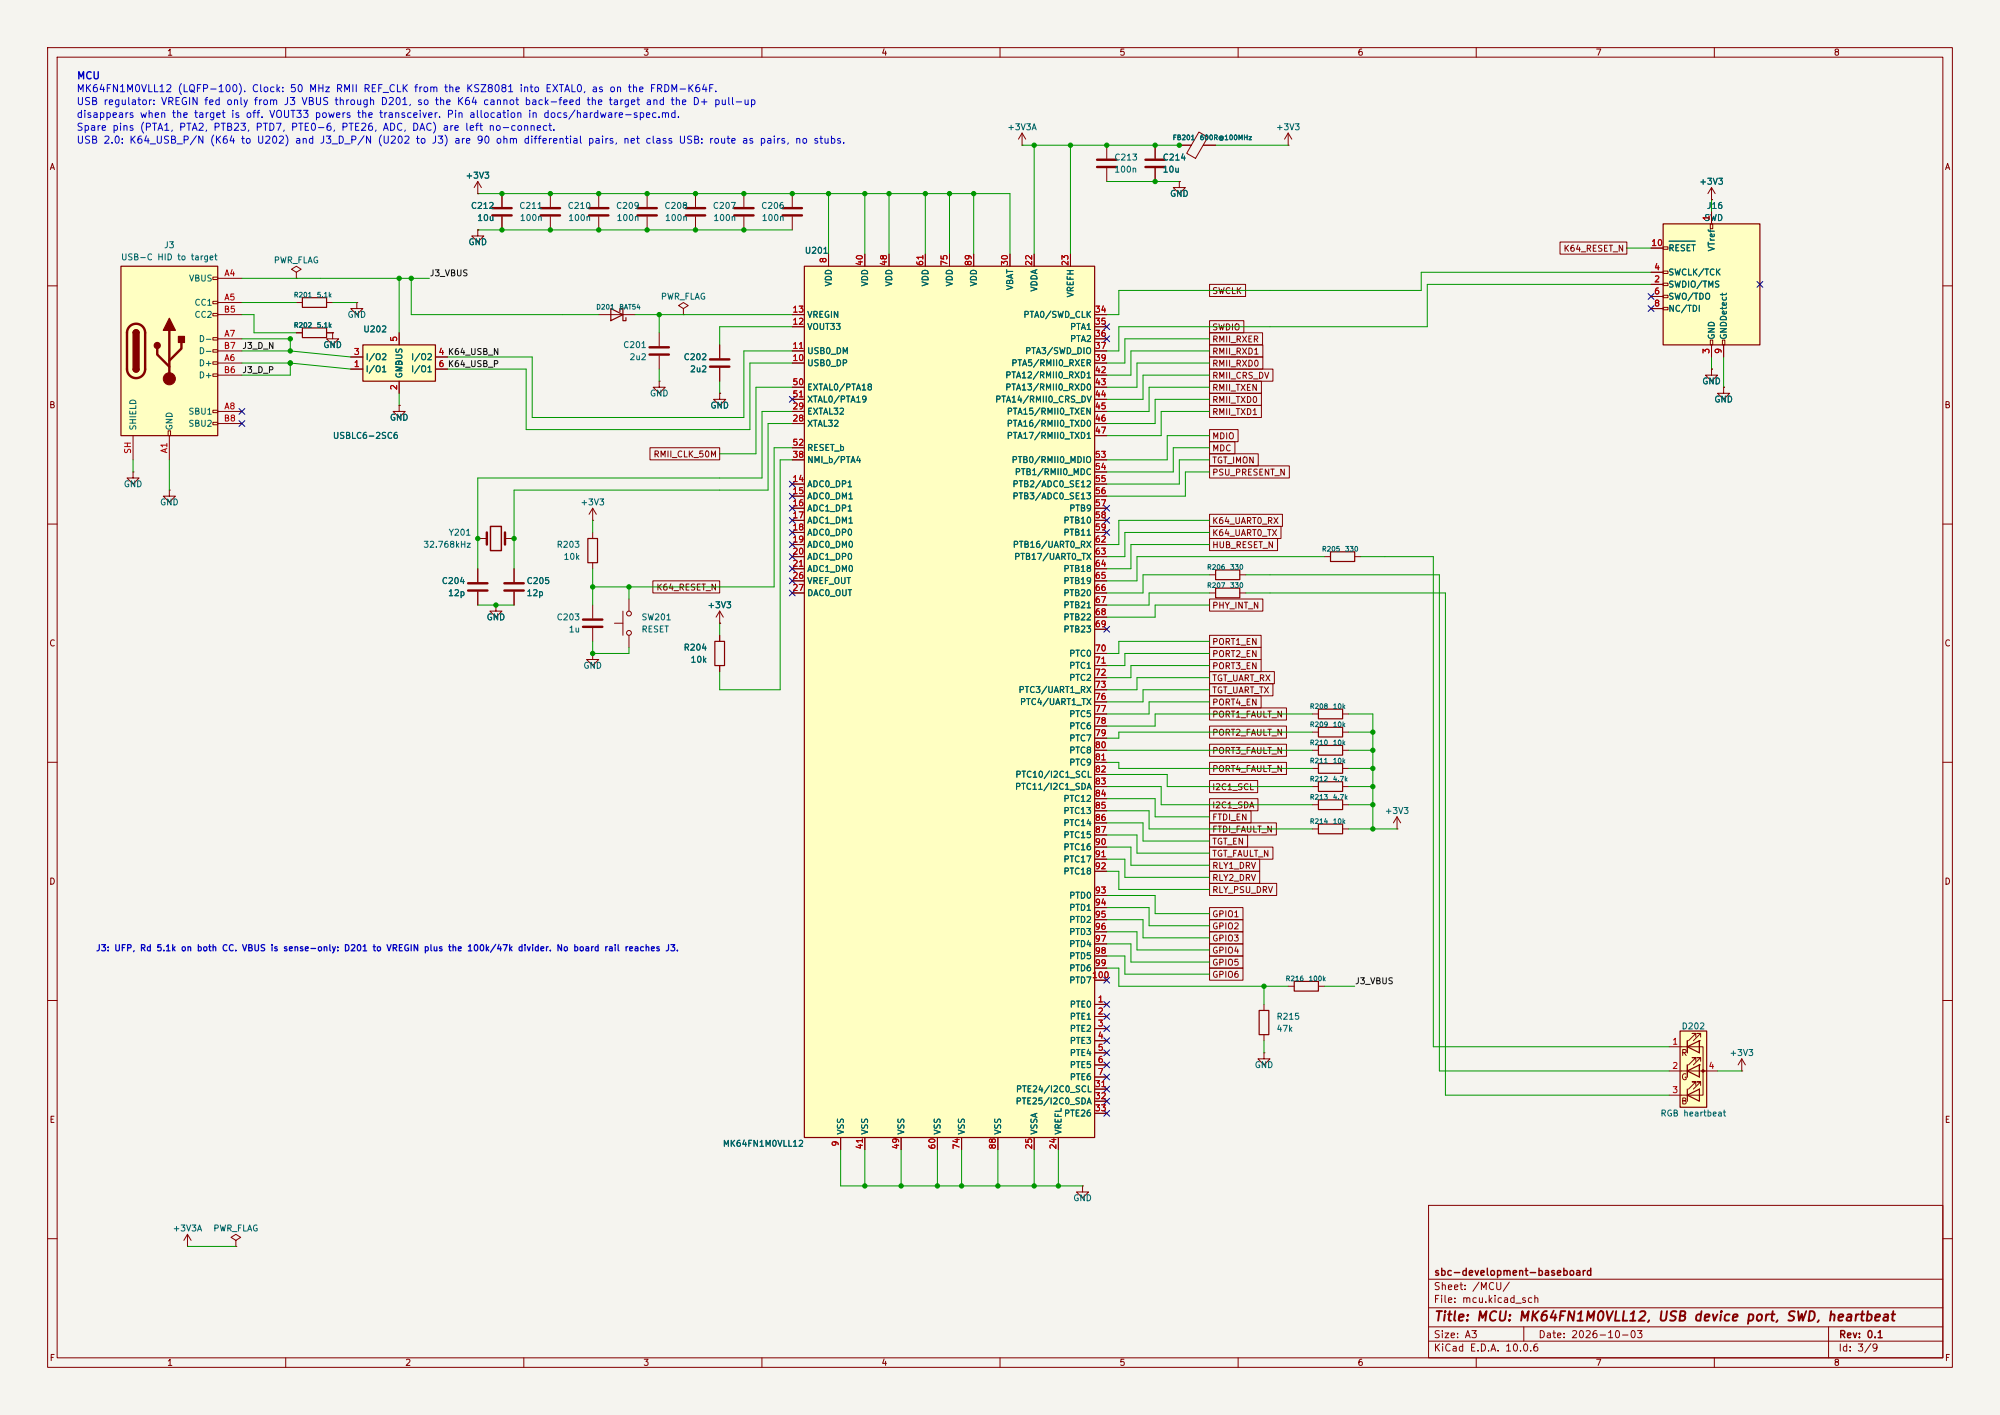
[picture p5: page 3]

MCU
MK64FN1M0VLL12 (LQFP-100). Clock: 50 MHz RMII REF_CLK from the KSZ8081 into EXTAL0, as on the FRDM-K64F. GND
USB regulator: VREGIN fed only from J3 VBUS through D201, so the K64 cannot back-feed the target and the D+ pull-up
disappears when the target is off. VOUT33 powers the transceiver. Pin allocation in docs/hardware-spec.md.
Spare pins (PTA1, PTA2, PTB23, PTD7, PTE0-6, PTE26, ADC, DAC) are left no-connect.
USB 2.0: K64_USB_P/N (K64 to U202) and J3_D_P/N (U202 to J3) are 90 ohm differential pairs, net class USB: route as pairs, no stubs.

J3 USB-C HID to target

J3: UFP, Rd 5.1k on both CC. VBUS is sense-only: D201 to VREGIN plus the 100k/47k divider. No board rail reaches J3.

sbc-development-baseboard
Sheet: /MCU/
File: mcu.kicad_sch
Title: MCU: MK64FN1M0VLL12, USB device port, SWD, heartbeat

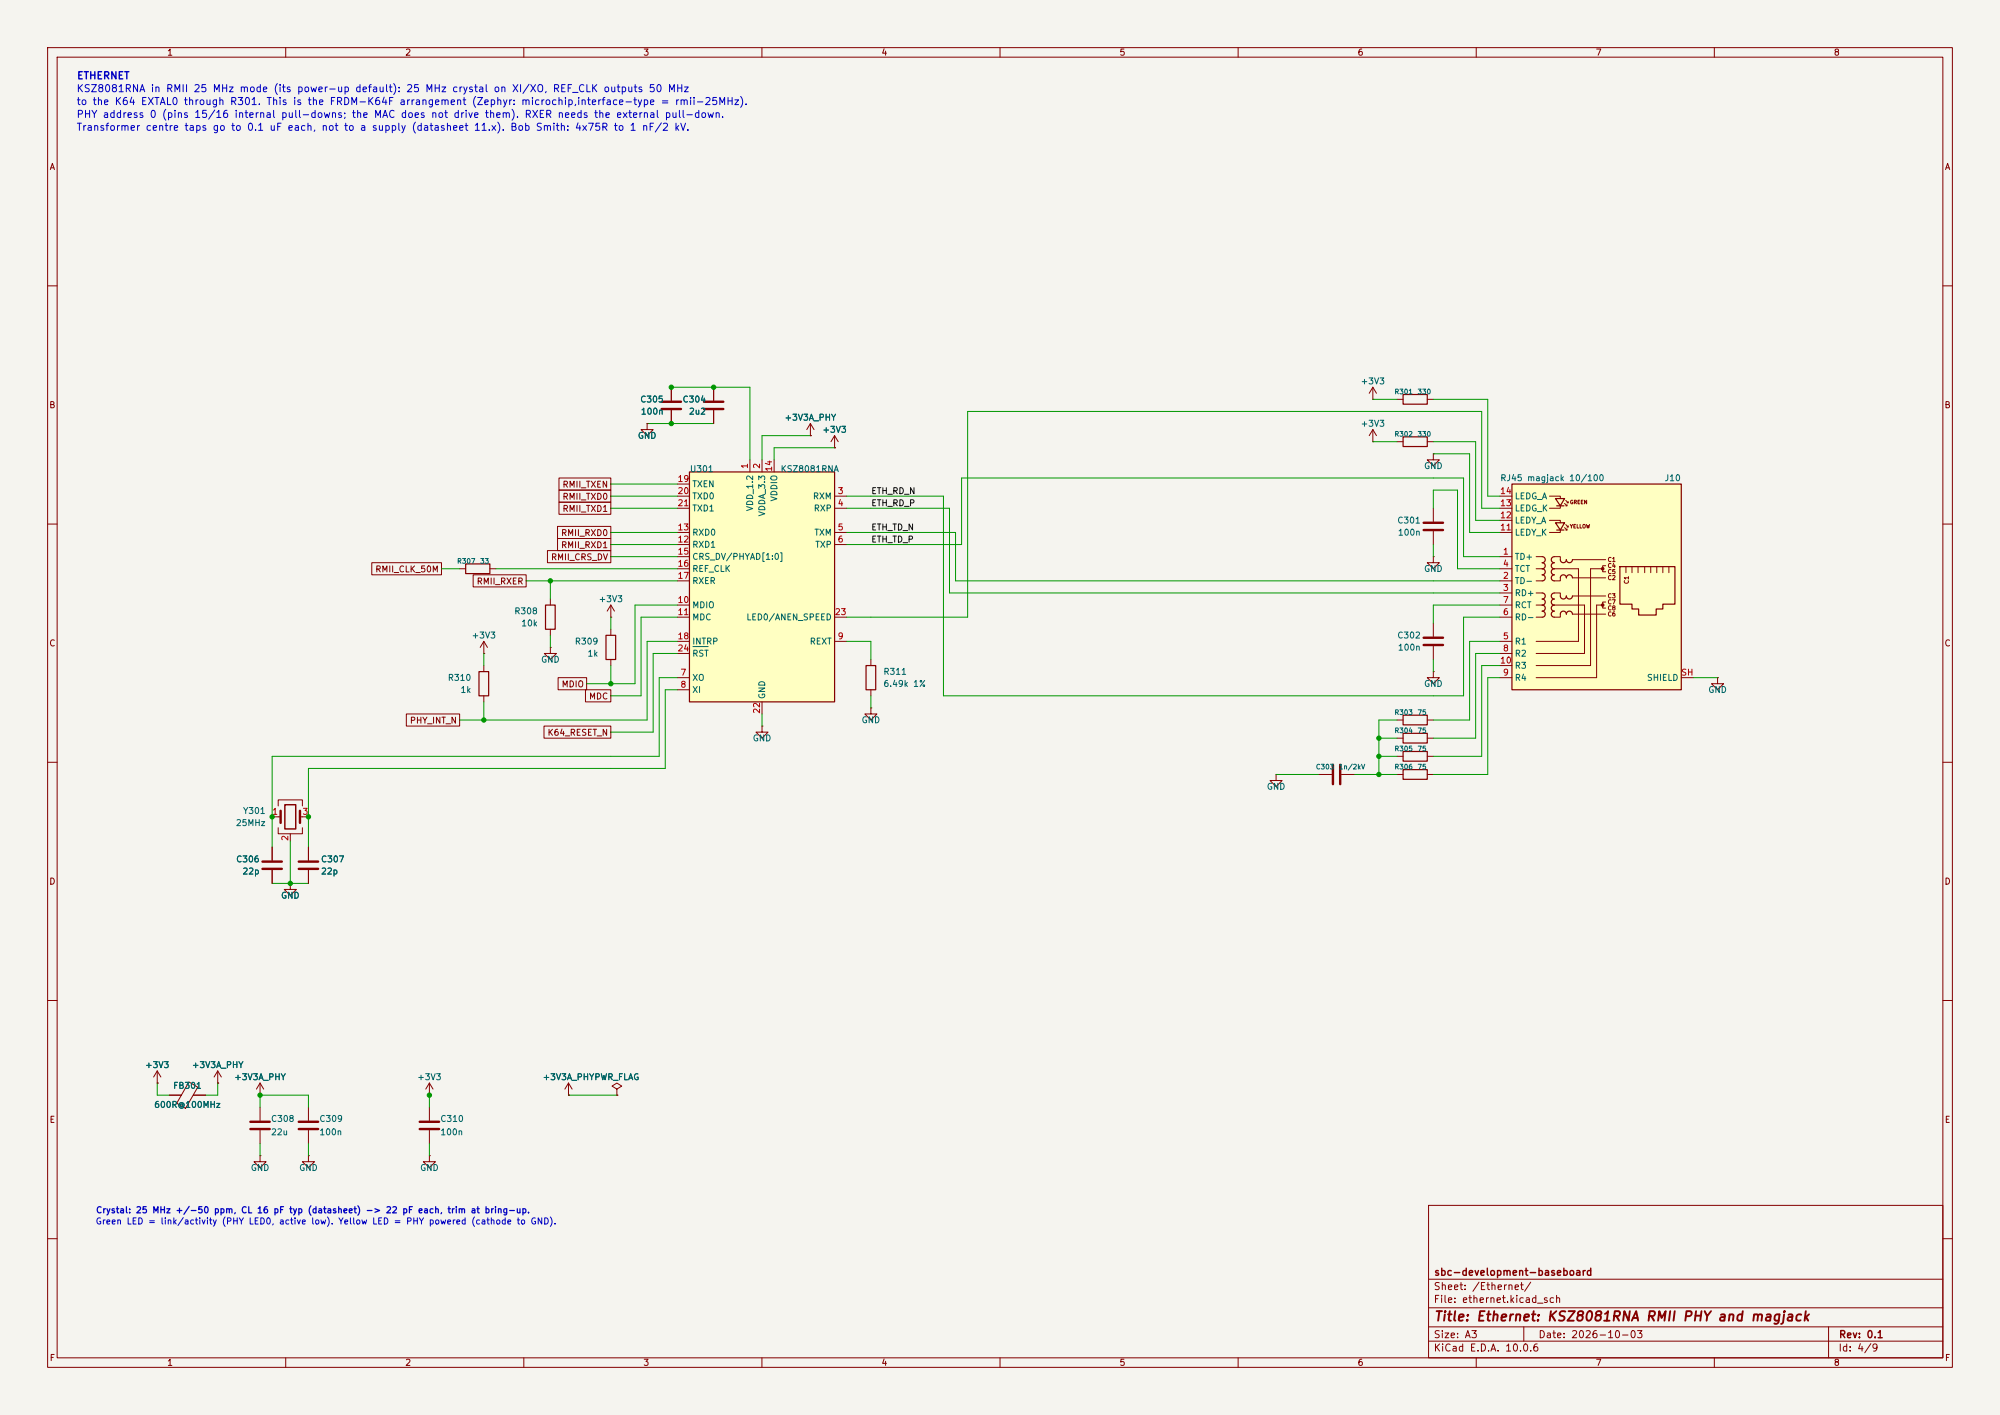
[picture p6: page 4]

ETHERNET
KSZ8081RNA in RMII 25 MHz mode (its power-up default): 25 MHz crystal on XI/XO, REF_CLK outputs 50 MHzC304
to the K64 EXTAL0 through R301. This is the FRDM-K64F arrangement (Zephyr: microchip,interface-type = rmii-25MHz).
PHY address 0 (pins 15/16 internal pull-downs; the MAC does not drive them). RXER needs the external pull-down.
Transformer centre taps go to 0.1 uF each, not to a supply (datasheet 11.x). Bob Smith: 4x75R to 1 nF/2 kV.

Crystal: 25 MHz +/-50 ppm, CL 16 pF typ (datasheet) -> 22 pF each, trim at bring-up. Green LED = link/activity (PHY LED0, active low). Yellow LED = PHY powered (cathode to GND).

sbc-development-baseboard
Sheet: /Ethernet/
File: ethernet.kicad_sch
Title: Ethernet: KSZ8081RNA RMII PHY and magjack

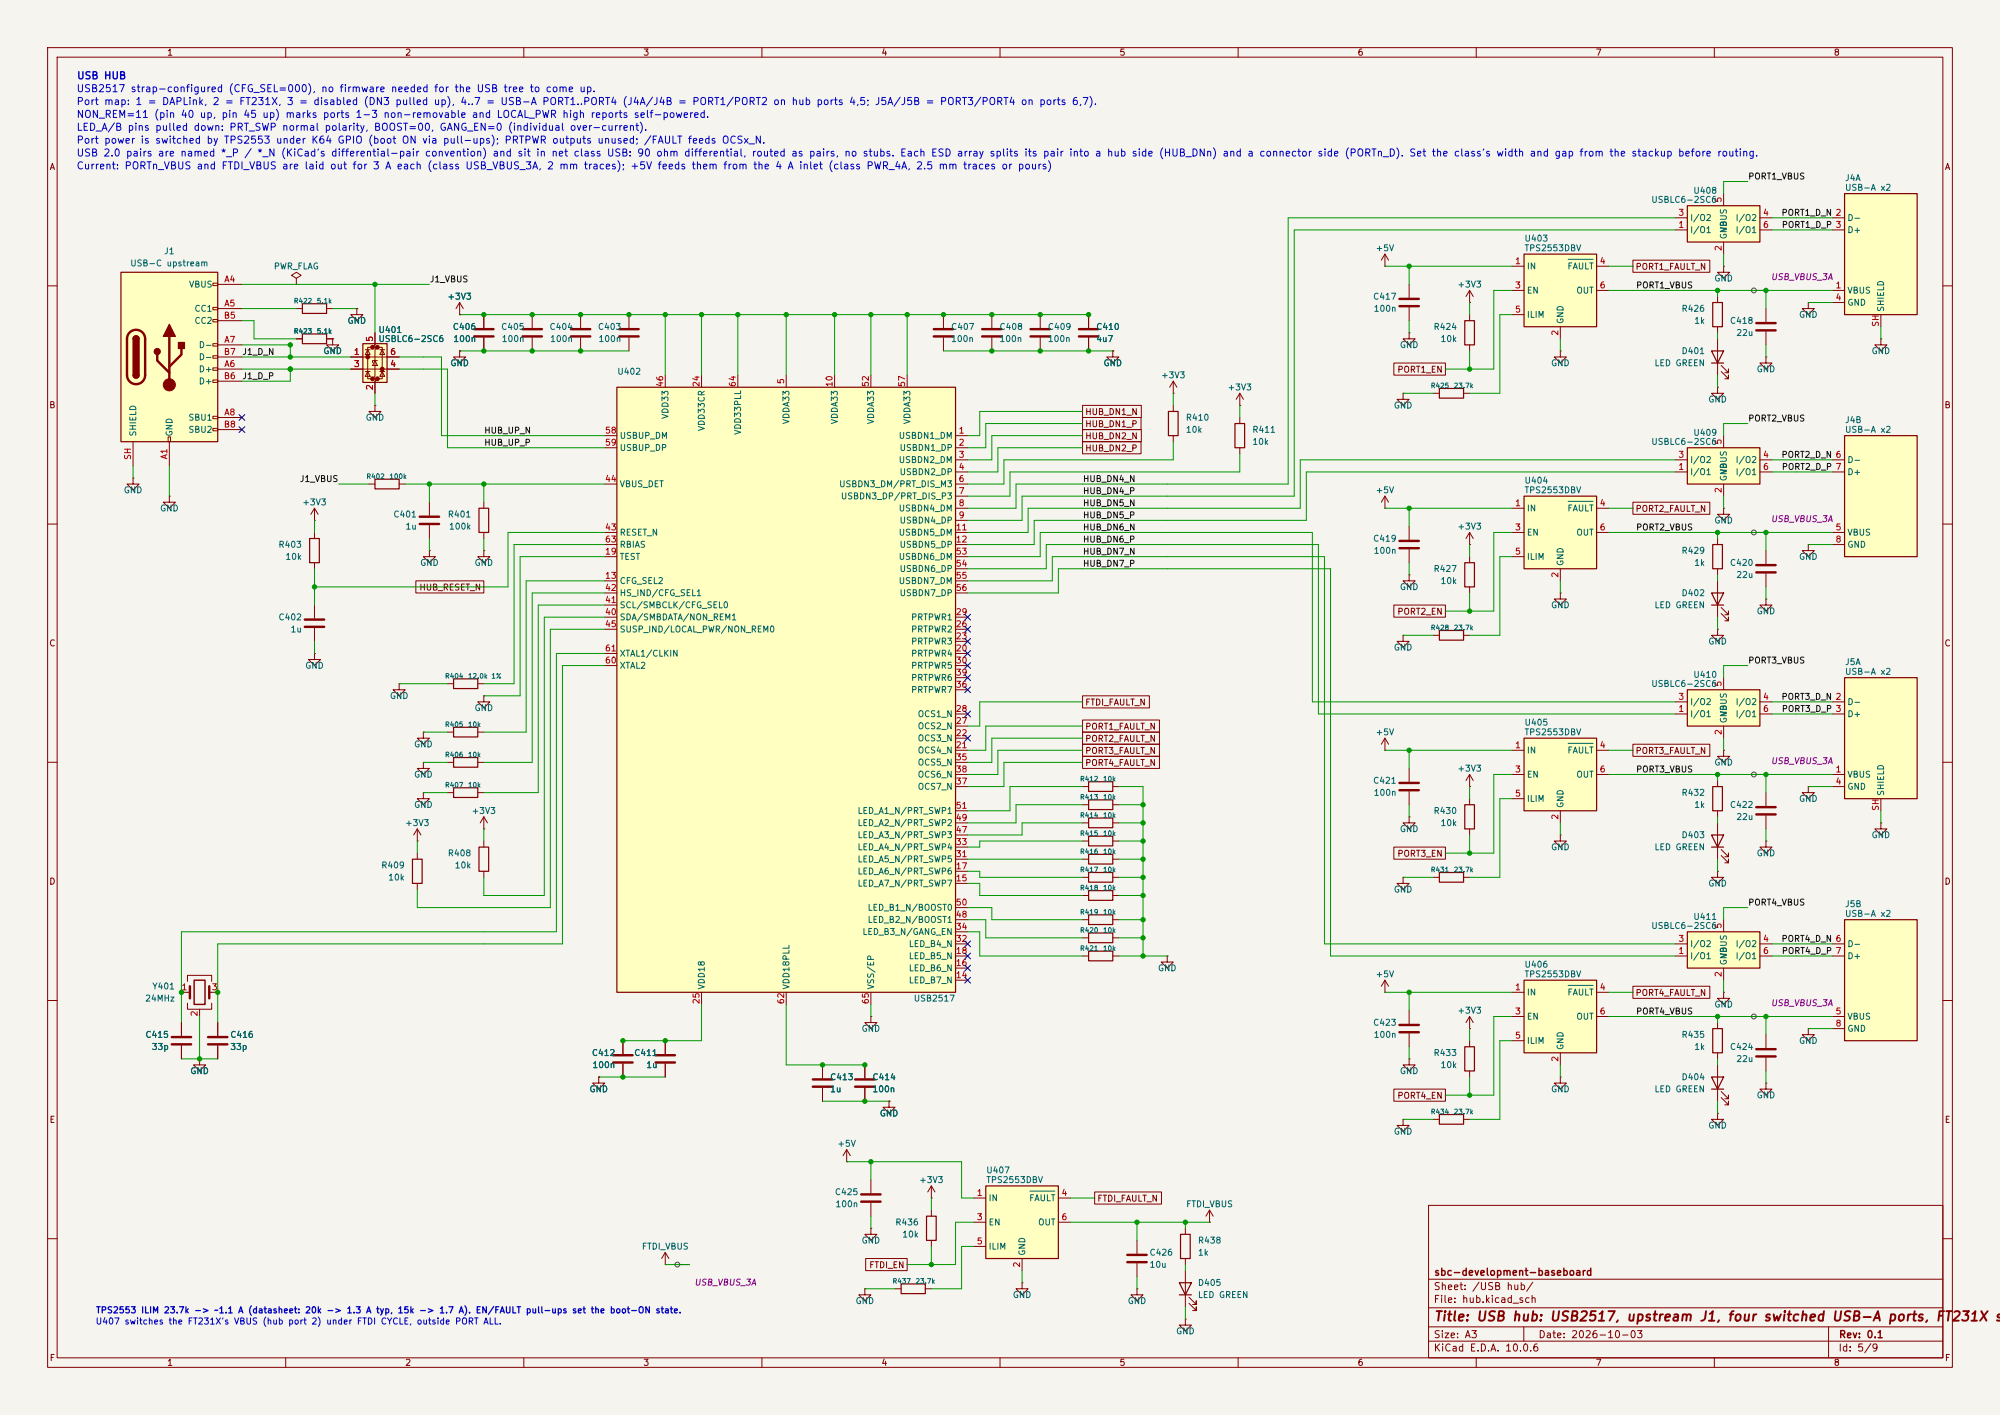
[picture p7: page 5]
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

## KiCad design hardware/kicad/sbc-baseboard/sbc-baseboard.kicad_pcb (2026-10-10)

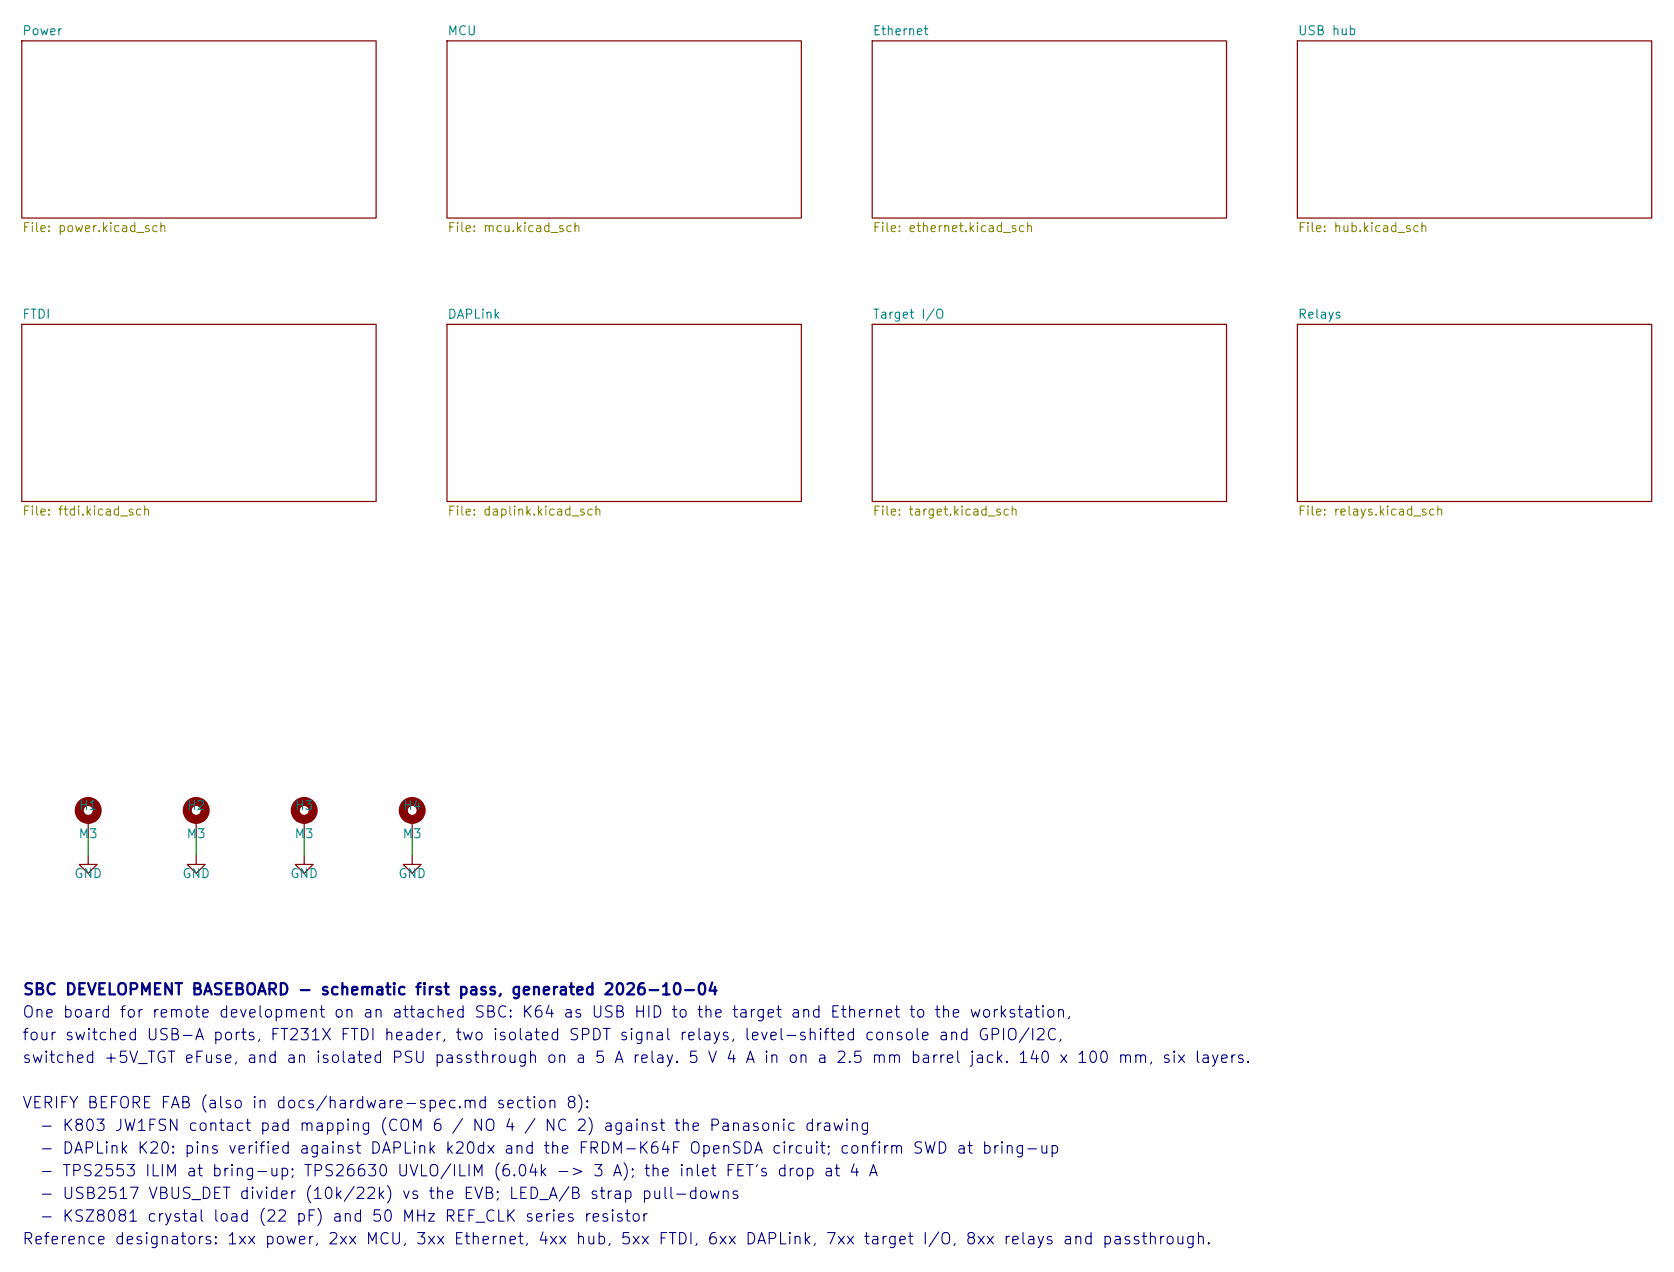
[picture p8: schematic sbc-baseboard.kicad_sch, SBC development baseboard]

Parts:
H1, H2, H3, H4: M3; MountingHole_3.2mm_M3_Pad

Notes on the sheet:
SBC DEVELOPMENT BASEBOARD - schematic first pass, generated 2026-10-04
One board for remote development on an attached SBC: K64 as USB HID to the target and Ethernet to the workstation,
four switched USB-A ports, FT231X FTDI header, two isolated SPDT signal relays, level-shifted console and GPIO/I2C,
switched +5V_TGT eFuse, and an isolated PSU passthrough on a 5 A relay. 5 V 4 A in on a 2.5 mm barrel jack. 140 x 100 mm, six layers.
VERIFY BEFORE FAB (also in docs/hardware-spec.md section 8):
- K803 JW1FSN contact pad mapping (COM 6 / NO 4 / NC 2) against the Panasonic drawing
- DAPLink K20: pins verified against DAPLink k20dx and the FRDM-K64F OpenSDA circuit; confirm SWD at bring-up
- TPS2553 ILIM at bring-up; TPS26630 UVLO/ILIM (6.04k -> 3 A); the inlet FET's drop at 4 A
- USB2517 VBUS_DET divider (10k/22k) vs the EVB; LED_A/B strap pull-downs
- KSZ8081 crystal load (22 pF) and 50 MHz REF_CLK series resistor
Reference designators: 1xx power, 2xx MCU, 3xx Ethernet, 4xx hub, 5xx FTDI, 6xx DAPLink, 7xx target I/O, 8xx relays and passthrough.

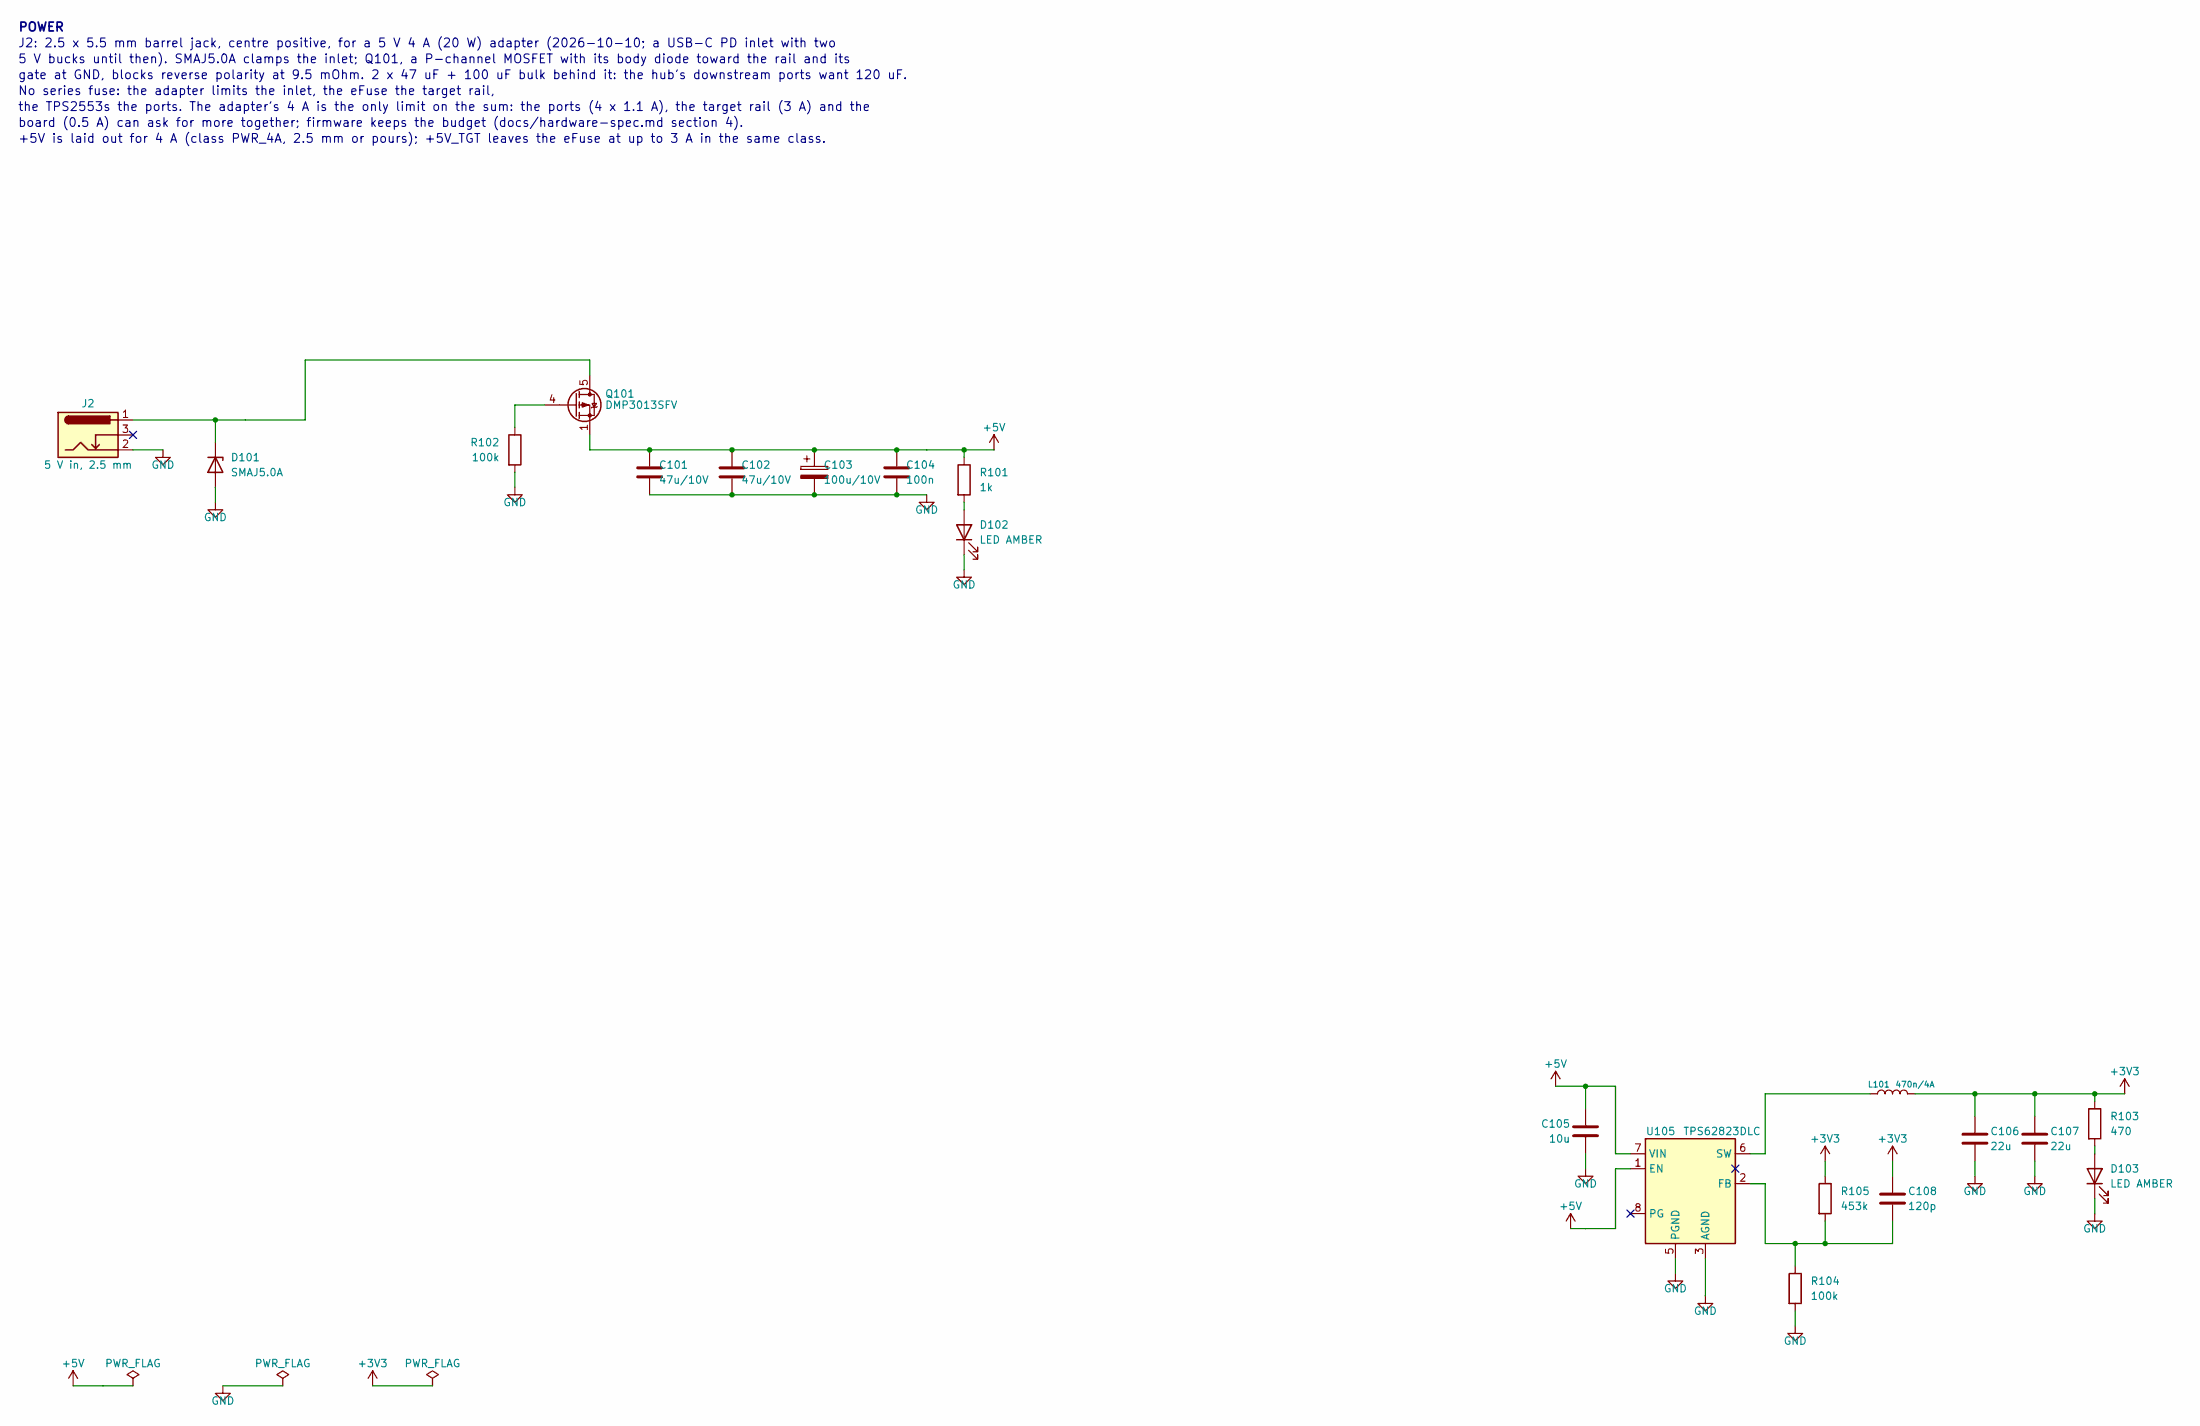
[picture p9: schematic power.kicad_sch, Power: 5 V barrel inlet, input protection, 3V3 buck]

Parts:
C101, C102: 47u/10V; C_1210_3225Metric
C103: 100u/10V; CP_Elec_8x10.5
C104: 100n; C_0603_1608Metric
C105: 10u; C_0805_2012Metric
C106, C107: 22u; C_0805_2012Metric
C108: 120p; C_0603_1608Metric
D101: SMAJ5.0A; D_SMA
D102, D103: LED AMBER; LED_0603_1608Metric
J2: 5 V in, 2.5 mm; BarrelJack_Kycon_KLDX-0202-xC_Horizontal
L101: 470n/4A; L_1210_3225Metric
Q101: DMP3013SFV; Diodes_PowerDI3333-8
R101: 1k; R_0603_1608Metric
R102, R104: 100k; R_0603_1608Metric
R103: 470; R_0603_1608Metric
R105: 453k; R_0603_1608Metric
U105: TPS62823DLC; Texas_VSON-HR-8_1.5x2mm_P0.5mm

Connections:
unnamed: D101.1 (K), J2.1, Q101.5 (D)
unnamed: D102.2 (A), R101.2
unnamed: D103.2 (A), R103.2
unnamed: Q101.4 (G), R102.1
unnamed: C108.2, R104.1, R105.2, U105.2 (FB)
unnamed: L101.1, U105.6 (SW)

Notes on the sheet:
POWER
J2: 2.5 x 5.5 mm barrel jack, centre positive, for a 5 V 4 A (20 W) adapter (2026-10-10; a USB-C PD inlet with two
5 V bucks until then). SMAJ5.0A clamps the inlet; Q101, a P-channel MOSFET with its body diode toward the rail and its
gate at GND, blocks reverse polarity at 9.5 mOhm. 2 x 47 uF + 100 uF bulk behind it: the hub's downstream ports want 120 uF.
No series fuse: the adapter limits the inlet, the eFuse the target rail,
the TPS2553s the ports. The adapter's 4 A is the only limit on the sum: the ports (4 x 1.1 A), the target rail (3 A) and the
board (0.5 A) can ask for more together; firmware keeps the budget (docs/hardware-spec.md section 4).
+5V is laid out for 4 A (class PWR_4A, 2.5 mm or pours); +5V_TGT leaves the eFuse at up to 3 A in the same class.

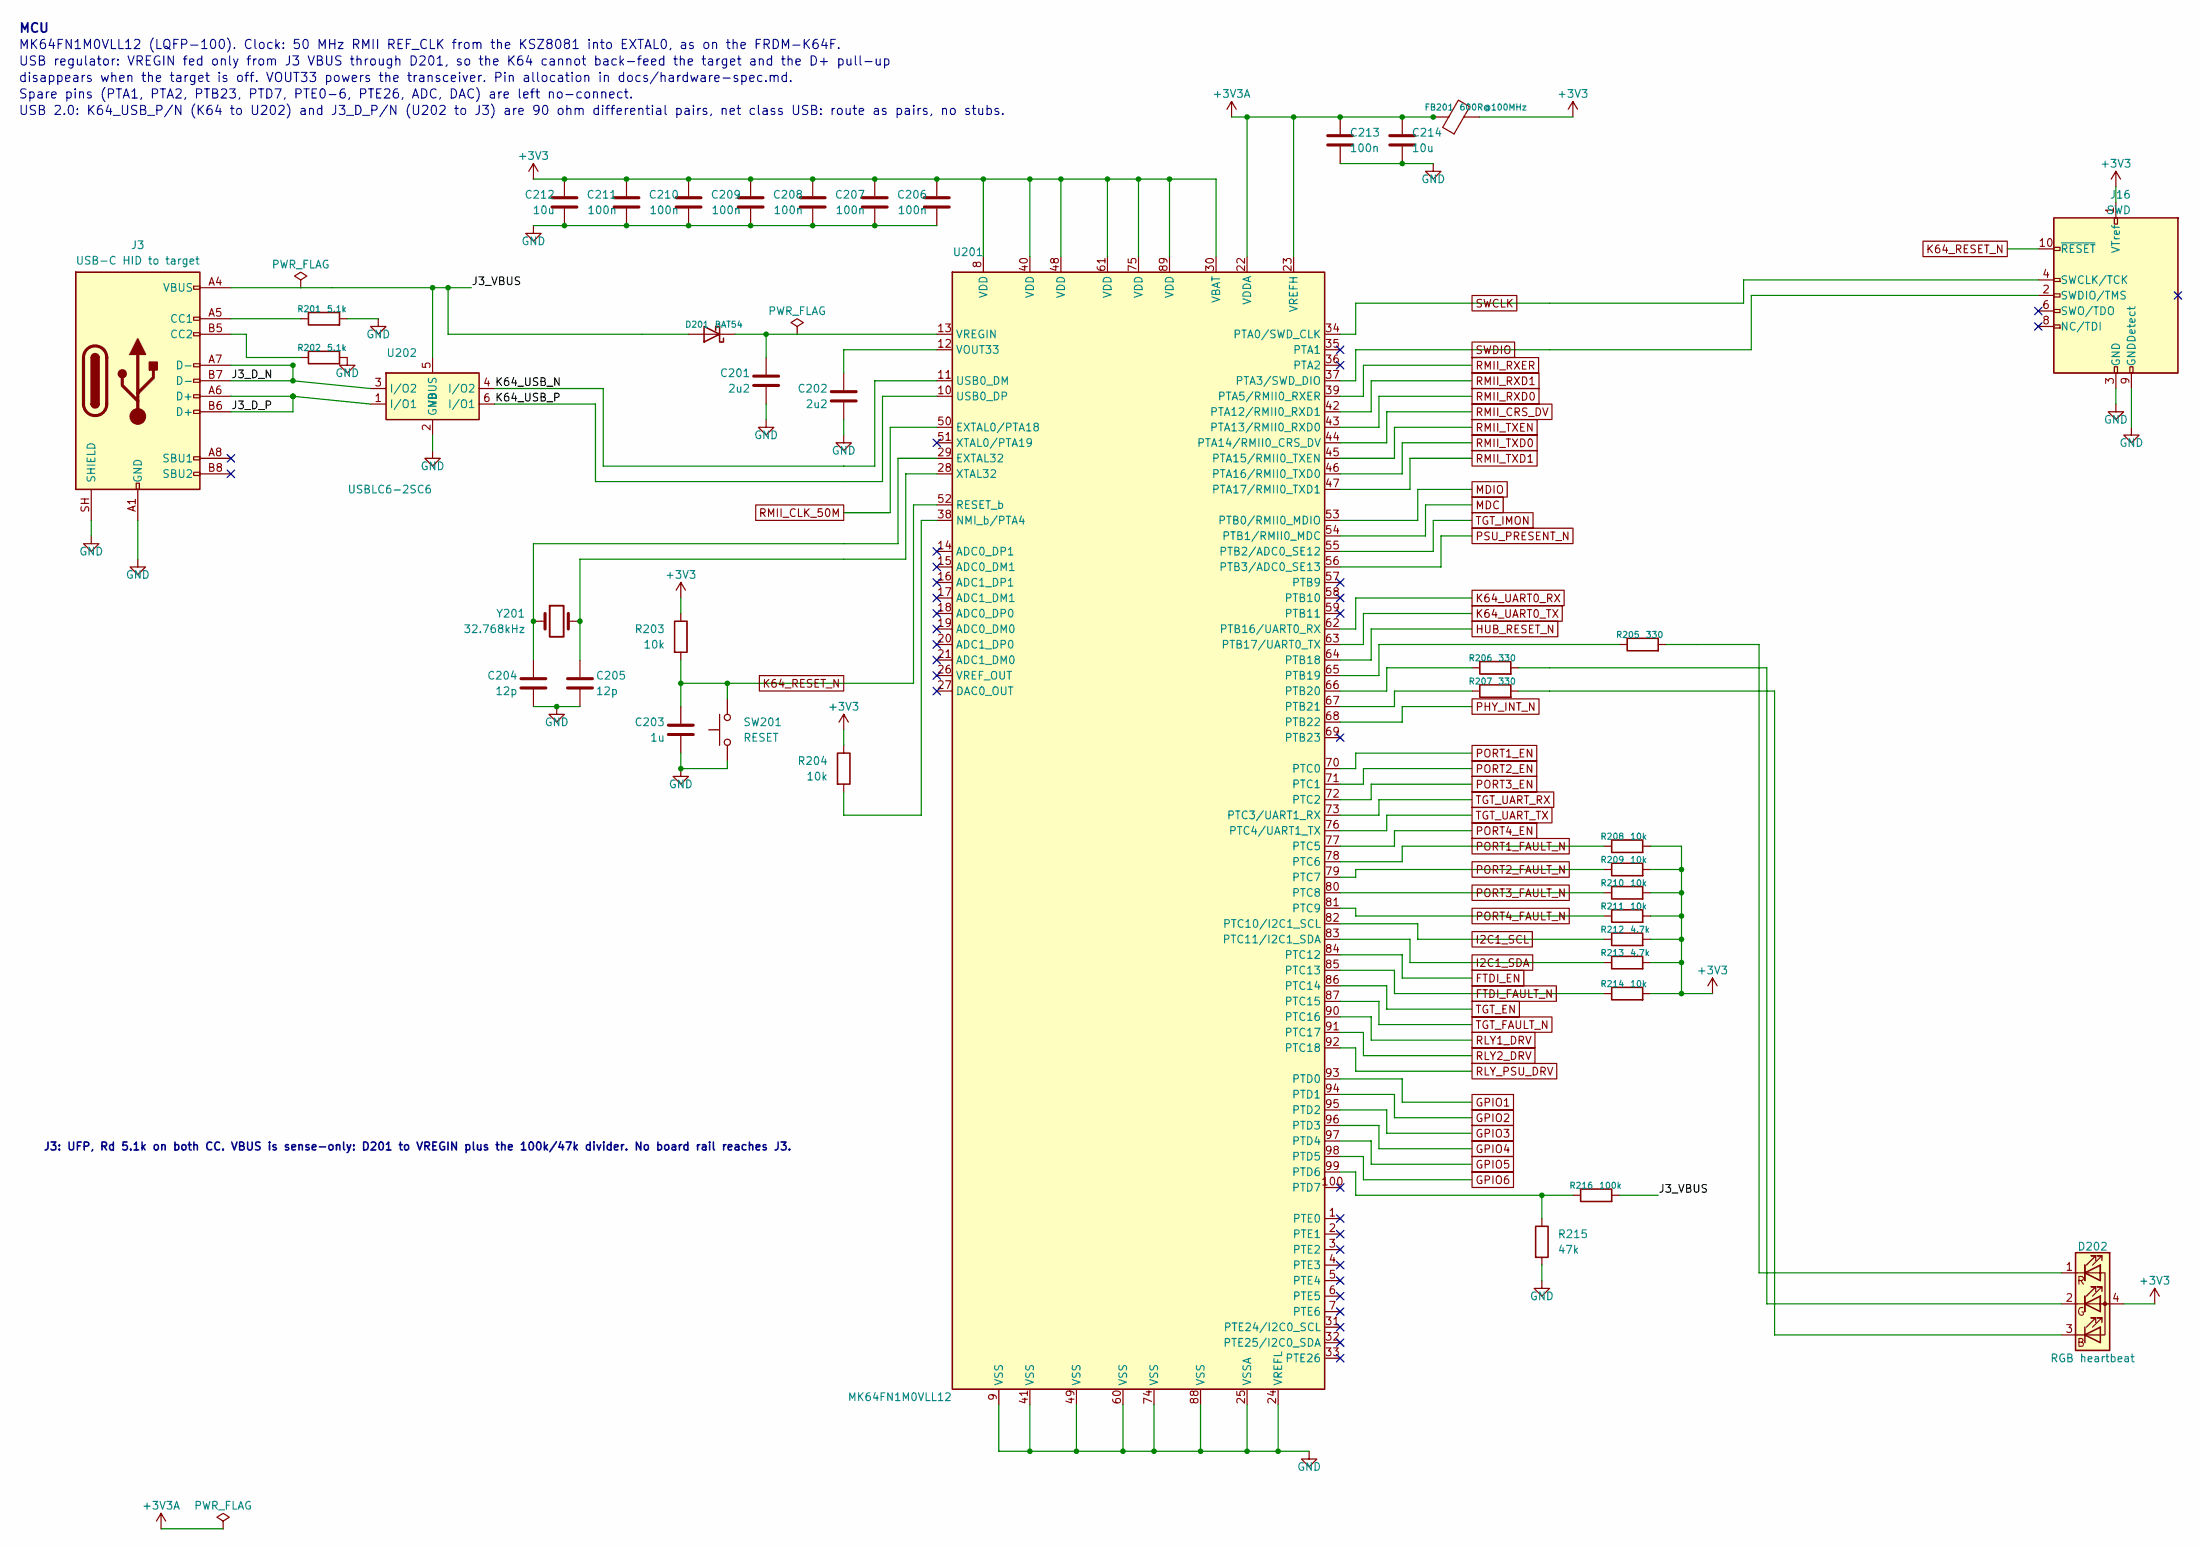
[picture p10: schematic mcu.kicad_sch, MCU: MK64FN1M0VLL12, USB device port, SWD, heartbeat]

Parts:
C201, C202: 2u2; C_0603_1608Metric
C203: 1u; C_0603_1608Metric
C204, C205: 12p; C_0603_1608Metric
C206, C207, C208, C209, C210, C211, C213: 100n; C_0603_1608Metric
C212, C214: 10u; C_0805_2012Metric
D201: BAT54; D_SOD-123
D202: RGB heartbeat; LED_RGB_1210
FB201: 600R@100MHz; L_0603_1608Metric
J3: USB-C HID to target; USB_C_Receptacle_GCT_USB4105-xx-A_16P_TopMnt_Horizontal_Peg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
J16: SWD; PinHeader_2x05_P1.27mm_Vertical
R201, R202: 5.1k; R_0603_1608Metric
R203, R204, R208, R209, R210, R211, R214: 10k; R_0603_1608Metric
R205, R206, R207: 330; R_0603_1608Metric
R212, R213: 4.7k; R_0603_1608Metric
R215: 47k; R_0603_1608Metric
R216: 100k; R_0603_1608Metric
SW201: RESET; SW_SPST_PTS645Sx43SMTR92
U201: MK64FN1M0VLL12; LQFP-100_14x14mm_P0.5mm
U202: USBLC6-2SC6; SOT-23-6
Y201: 32.768kHz; Crystal_SMD_3215-2Pin_3.2x1.5mm

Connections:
/MCU/J3_D_N: J3.A7 (D-), J3.B7 (D-), U202.3 (I/O2)
/MCU/J3_D_P: J3.A6 (D+), J3.B6 (D+), U202.1 (I/O1)
/MCU/K64_USB_N: U201.11 (USB0_DM), U202.4 (I/O2)
/MCU/K64_USB_P: U201.10 (USB0_DP), U202.6 (I/O1)
FTDI_EN: U201.84 (PTC12); also elsewhere on the board
FTDI_FAULT_N: R214.1, U201.85 (PTC13); also elsewhere on the board
GPIO1: U201.93 (PTD0); also elsewhere on the board
GPIO2: U201.94 (PTD1); also elsewhere on the board
GPIO3: U201.95 (PTD2); also elsewhere on the board
GPIO4: U201.96 (PTD3); also elsewhere on the board
GPIO5: U201.97 (PTD4); also elsewhere on the board
GPIO6: U201.98 (PTD5); also elsewhere on the board
HUB_RESET_N: U201.64 (PTB18); also elsewhere on the board
I2C1_SCL: R212.1, U201.82 (PTC10/I2C1_SCL); also elsewhere on the board
I2C1_SDA: R213.1, U201.83 (PTC11/I2C1_SDA); also elsewhere on the board
K64_RESET_N: C203.1, J16.10 (~RESET), R203.2, SW201.2, U201.52 (RESET_b); also elsewhere on the board
K64_UART0_RX: U201.62 (PTB16/UART0_RX); also elsewhere on the board
K64_UART0_TX: U201.63 (PTB17/UART0_TX); also elsewhere on the board
MDC: U201.54 (PTB1/RMII0_MDC); also elsewhere on the board
MDIO: U201.53 (PTB0/RMII0_MDIO); also elsewhere on the board
unnamed: D202.3 (BK), R207.2
unnamed: D202.2 (GK), R206.2
unnamed: D202.1 (RK), R205.2
unnamed: J3.A5 (CC1), R201.1
unnamed: J3.B5 (CC2), R202.1
unnamed: C204.1, U201.29 (EXTAL32), Y201.1
unnamed: R204.2, U201.38 (NMI_b/PTA4)
unnamed: R205.1, U201.65 (PTB19)
unnamed: R206.1, U201.66 (PTB20)
unnamed: R207.1, U201.67 (PTB21)
unnamed: R215.1, R216.1, U201.99 (PTD6)
unnamed: C202.1, U201.12 (VOUT33)
unnamed: C205.1, U201.28 (XTAL32), Y201.2
PHY_INT_N: U201.68 (PTB22); also elsewhere on the board
PORT1_EN: U201.70 (PTC0); also elsewhere on the board
PORT1_FAULT_N: R208.1, U201.78 (PTC6); also elsewhere on the board
PORT2_EN: U201.71 (PTC1); also elsewhere on the board
PORT2_FAULT_N: R209.1, U201.79 (PTC7); also elsewhere on the board
PORT3_EN: U201.72 (PTC2); also elsewhere on the board
PORT3_FAULT_N: R210.1, U201.80 (PTC8); also elsewhere on the board
PORT4_EN: U201.77 (PTC5); also elsewhere on the board
PORT4_FAULT_N: R211.1, U201.81 (PTC9); also elsewhere on the board
PSU_PRESENT_N: U201.56 (PTB3/ADC0_SE13); also elsewhere on the board
RLY1_DRV: U201.90 (PTC16); also elsewhere on the board
RLY2_DRV: U201.91 (PTC17); also elsewhere on the board
RLY_PSU_DRV: U201.92 (PTC18); also elsewhere on the board
RMII_CLK_50M: U201.50 (EXTAL0/PTA18); also elsewhere on the board
RMII_CRS_DV: U201.44 (PTA14/RMII0_CRS_DV); also elsewhere on the board
RMII_RXD0: U201.43 (PTA13/RMII0_RXD0); also elsewhere on the board
RMII_RXD1: U201.42 (PTA12/RMII0_RXD1); also elsewhere on the board
RMII_RXER: U201.39 (PTA5/RMII0_RXER); also elsewhere on the board
RMII_TXD0: U201.46 (PTA16/RMII0_TXD0); also elsewhere on the board
RMII_TXD1: U201.47 (PTA17/RMII0_TXD1); also elsewhere on the board
RMII_TXEN: U201.45 (PTA15/RMII0_TXEN); also elsewhere on the board
SWCLK: J16.4 (SWCLK/TCK), U201.34 (PTA0/SWD_CLK); also elsewhere on the board
SWDIO: J16.2 (SWDIO/TMS), U201.37 (PTA3/SWD_DIO); also elsewhere on the board
TGT_EN: U201.86 (PTC14); also elsewhere on the board
TGT_FAULT_N: U201.87 (PTC15); also elsewhere on the board
TGT_IMON: U201.55 (PTB2/ADC0_SE12); also elsewhere on the board
TGT_UART_RX: U201.73 (PTC3/UART1_RX); also elsewhere on the board
TGT_UART_TX: U201.76 (PTC4/UART1_TX); also elsewhere on the board

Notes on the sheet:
MCU
MK64FN1M0VLL12 (LQFP-100). Clock: 50 MHz RMII REF_CLK from the KSZ8081 into EXTAL0, as on the FRDM-K64F.
USB regulator: VREGIN fed only from J3 VBUS through D201, so the K64 cannot back-feed the target and the D+ pull-up
disappears when the target is off. VOUT33 powers the transceiver. Pin allocation in docs/hardware-spec.md.
Spare pins (PTA1, PTA2, PTB23, PTD7, PTE0-6, PTE26, ADC, DAC) are left no-connect.
USB 2.0: K64_USB_P/N (K64 to U202) and J3_D_P/N (U202 to J3) are 90 ohm differential pairs, net class USB: route as pairs, no stubs.
J3: UFP, Rd 5.1k on both CC. VBUS is sense-only: D201 to VREGIN plus the 100k/47k divider. No board rail reaches J3.

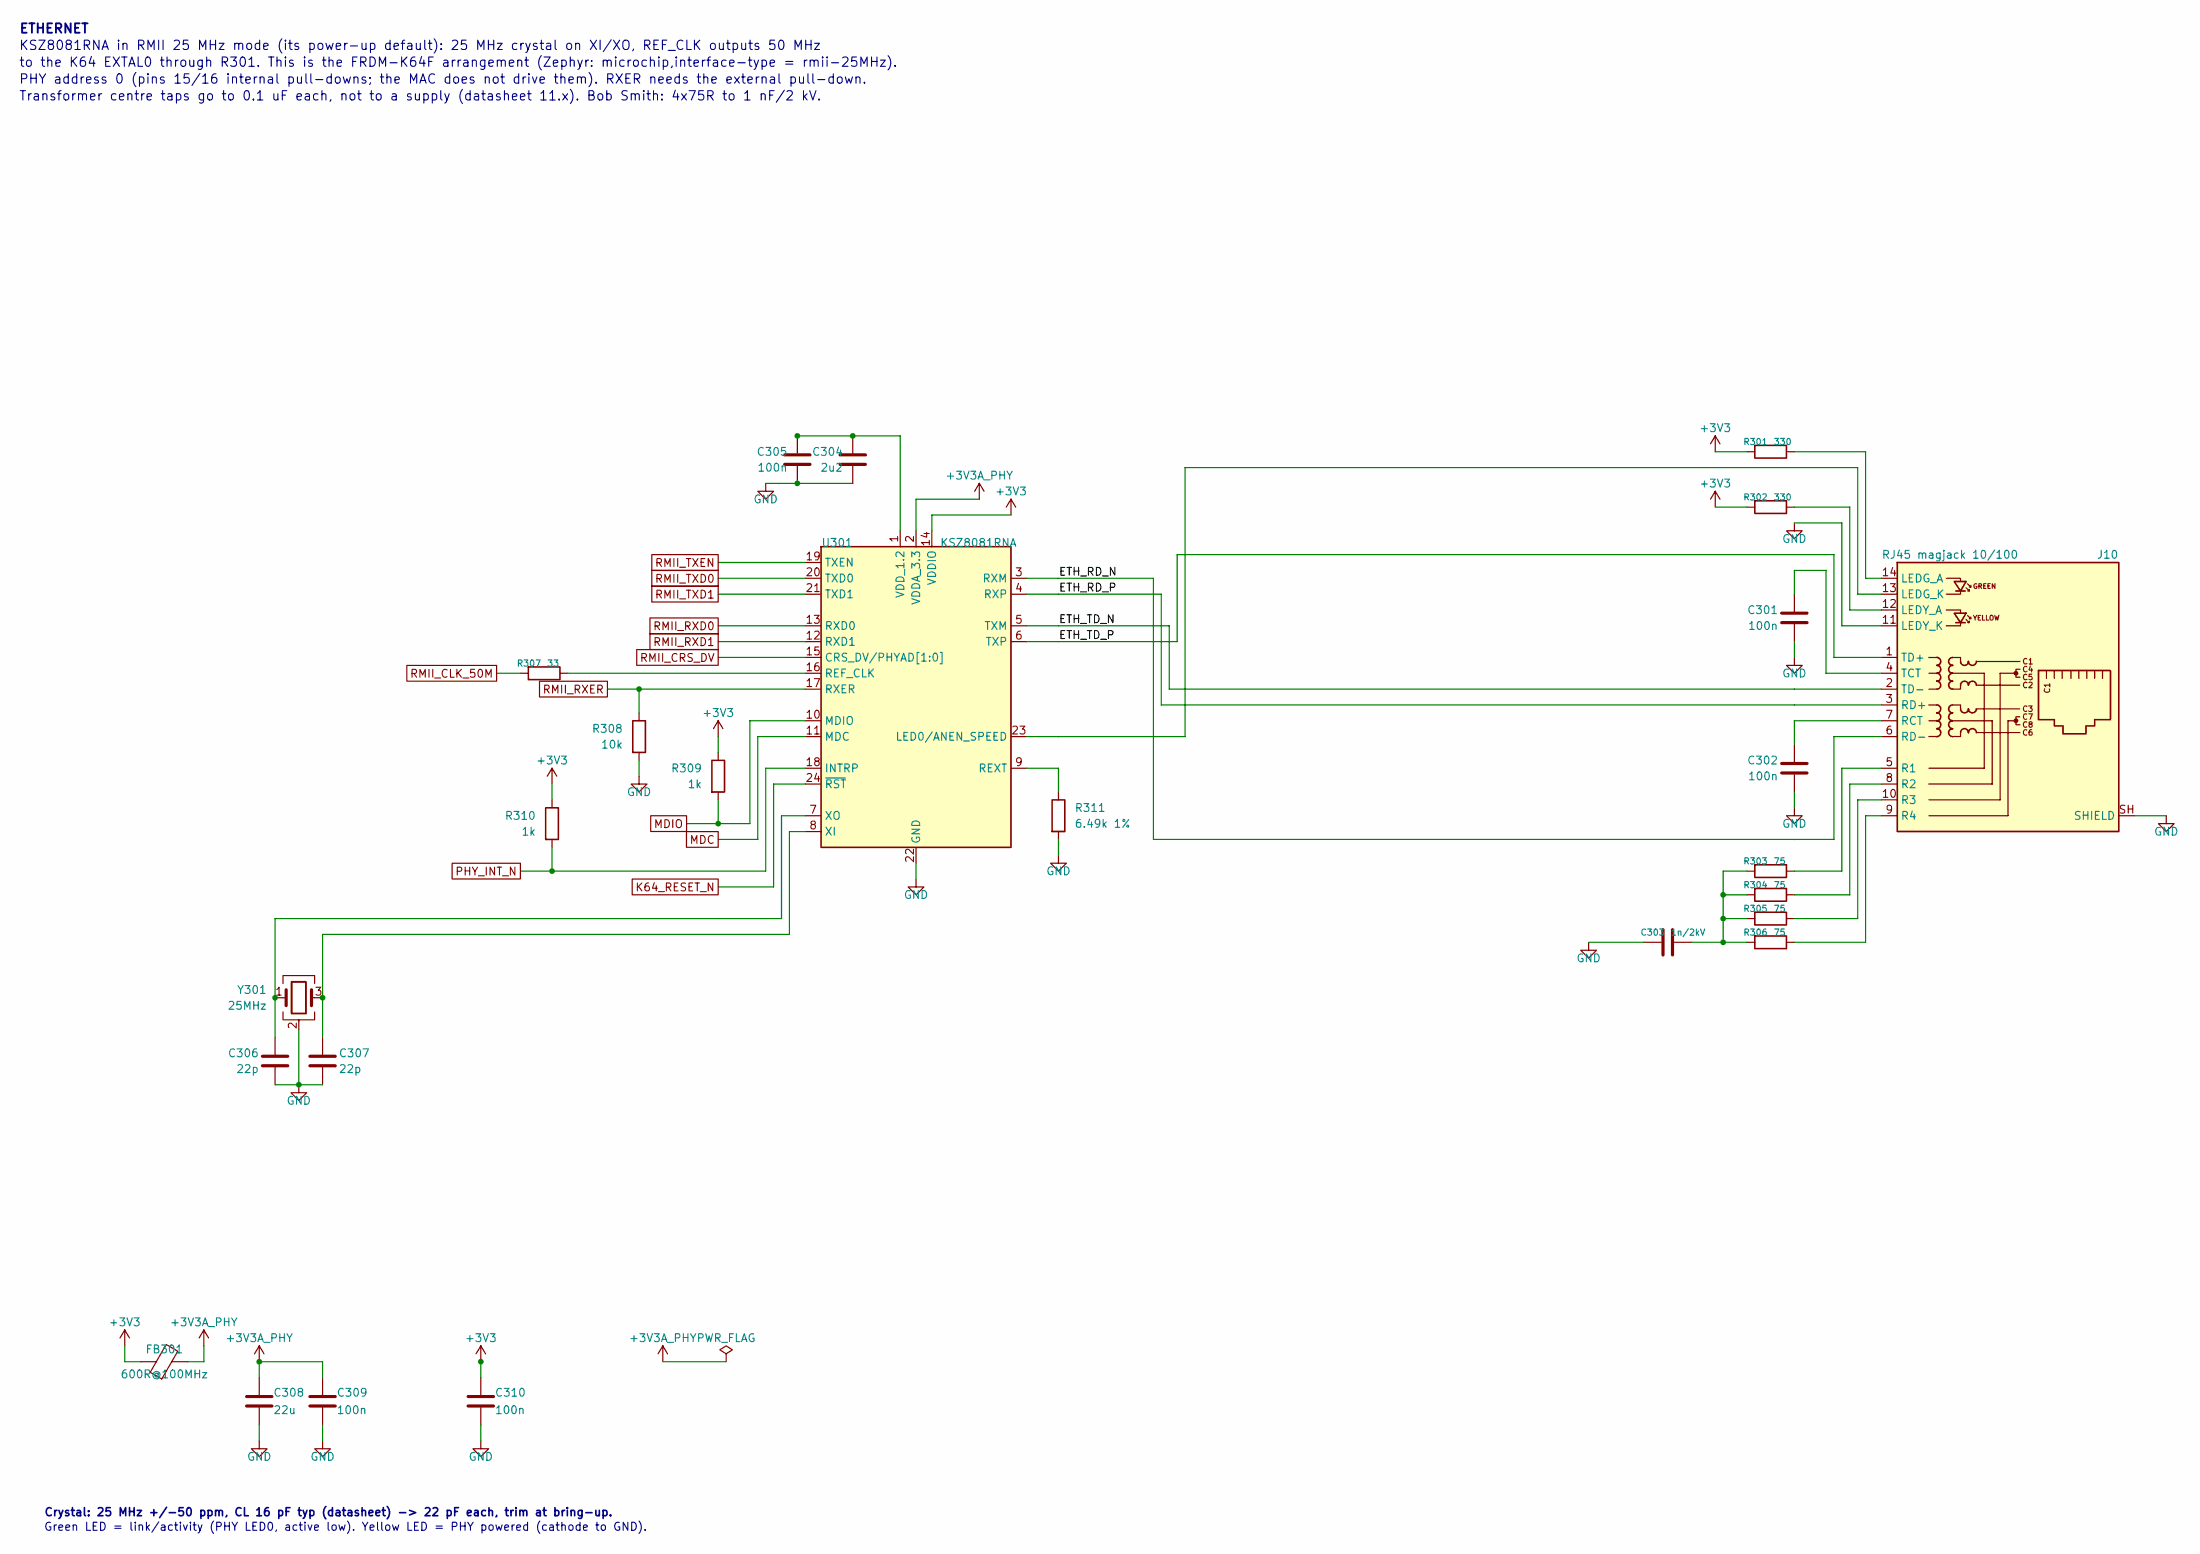
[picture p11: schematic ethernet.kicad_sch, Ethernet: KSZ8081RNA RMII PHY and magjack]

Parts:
C301, C302, C305, C309, C310: 100n; C_0603_1608Metric
C303: 1n/2kV; C_1206_3216Metric
C304: 2u2; C_0603_1608Metric
C306, C307: 22p; C_0603_1608Metric
C308: 22u; C_0805_2012Metric
FB301: 600R@100MHz; L_0603_1608Metric
J10: RJ45 magjack 10/100; RJ45_Kycon_G7LX-A88S7-BP-xx_Horizontal
R301, R302: 330; R_0603_1608Metric
R303, R304, R305, R306: 75; R_0603_1608Metric
R307: 33; R_0603_1608Metric
R308: 10k; R_0603_1608Metric
R309, R310: 1k; R_0603_1608Metric
R311: 6.49k 1%; R_0603_1608Metric
U301: KSZ8081RNA; QFN-24-1EP_4x4mm_P0.5mm_EP2.6x2.6mm
Y301: 25MHz; Crystal_SMD_3225-4Pin_3.2x2.5mm

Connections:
+3V3A_PHY: C308.1, C309.1, FB301.2, U301.2 (VDDA_3.3)
/Ethernet/ETH_RD_N: J10.6 (RD-), U301.3 (RXM)
/Ethernet/ETH_RD_P: J10.3 (RD+), U301.4 (RXP)
/Ethernet/ETH_TD_N: J10.2 (TD-), U301.5 (TXM)
/Ethernet/ETH_TD_P: J10.1 (TD+), U301.6 (TXP)
K64_RESET_N: U301.24 (~RST); also elsewhere on the board
MDC: U301.11 (MDC); also elsewhere on the board
MDIO: R309.2, U301.10 (MDIO); also elsewhere on the board
unnamed: C303.1, R303.2, R304.2, R305.2, R306.2
unnamed: J10.14 (LEDG_A), R301.1
unnamed: J10.13 (LEDG_K), U301.23 (LED0/ANEN_SPEED)
unnamed: J10.12 (LEDY_A), R302.1
unnamed: J10.5 (R1), R303.1
unnamed: J10.8 (R2), R304.1
unnamed: J10.10 (R3), R305.1
unnamed: J10.9 (R4), R306.1
unnamed: C302.1, J10.7 (RCT)
unnamed: C301.1, J10.4 (TCT)
unnamed: R307.1, U301.16 (REF_CLK)
unnamed: R311.1, U301.9 (REXT)
unnamed: C304.1, C305.1, U301.1 (VDD_1.2)
unnamed: C307.1, U301.8 (XI), Y301.3
unnamed: C306.1, U301.7 (XO), Y301.1
PHY_INT_N: R310.2, U301.18 (INTRP); also elsewhere on the board
RMII_CLK_50M: R307.2; also elsewhere on the board
RMII_CRS_DV: U301.15 (CRS_DV/PHYAD[1:0]); also elsewhere on the board
RMII_RXD0: U301.13 (RXD0); also elsewhere on the board
RMII_RXD1: U301.12 (RXD1); also elsewhere on the board
RMII_RXER: R308.1, U301.17 (RXER); also elsewhere on the board
RMII_TXD0: U301.20 (TXD0); also elsewhere on the board
RMII_TXD1: U301.21 (TXD1); also elsewhere on the board
RMII_TXEN: U301.19 (TXEN); also elsewhere on the board

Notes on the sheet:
ETHERNET
KSZ8081RNA in RMII 25 MHz mode (its power-up default): 25 MHz crystal on XI/XO, REF_CLK outputs 50 MHz
to the K64 EXTAL0 through R301. This is the FRDM-K64F arrangement (Zephyr: microchip,interface-type = rmii-25MHz).
PHY address 0 (pins 15/16 internal pull-downs; the MAC does not drive them). RXER needs the external pull-down.
Transformer centre taps go to 0.1 uF each, not to a supply (datasheet 11.x). Bob Smith: 4x75R to 1 nF/2 kV.
Crystal: 25 MHz +/-50 ppm, CL 16 pF typ (datasheet) -> 22 pF each, trim at bring-up.
Green LED = link/activity (PHY LED0, active low). Yellow LED = PHY powered (cathode to GND).

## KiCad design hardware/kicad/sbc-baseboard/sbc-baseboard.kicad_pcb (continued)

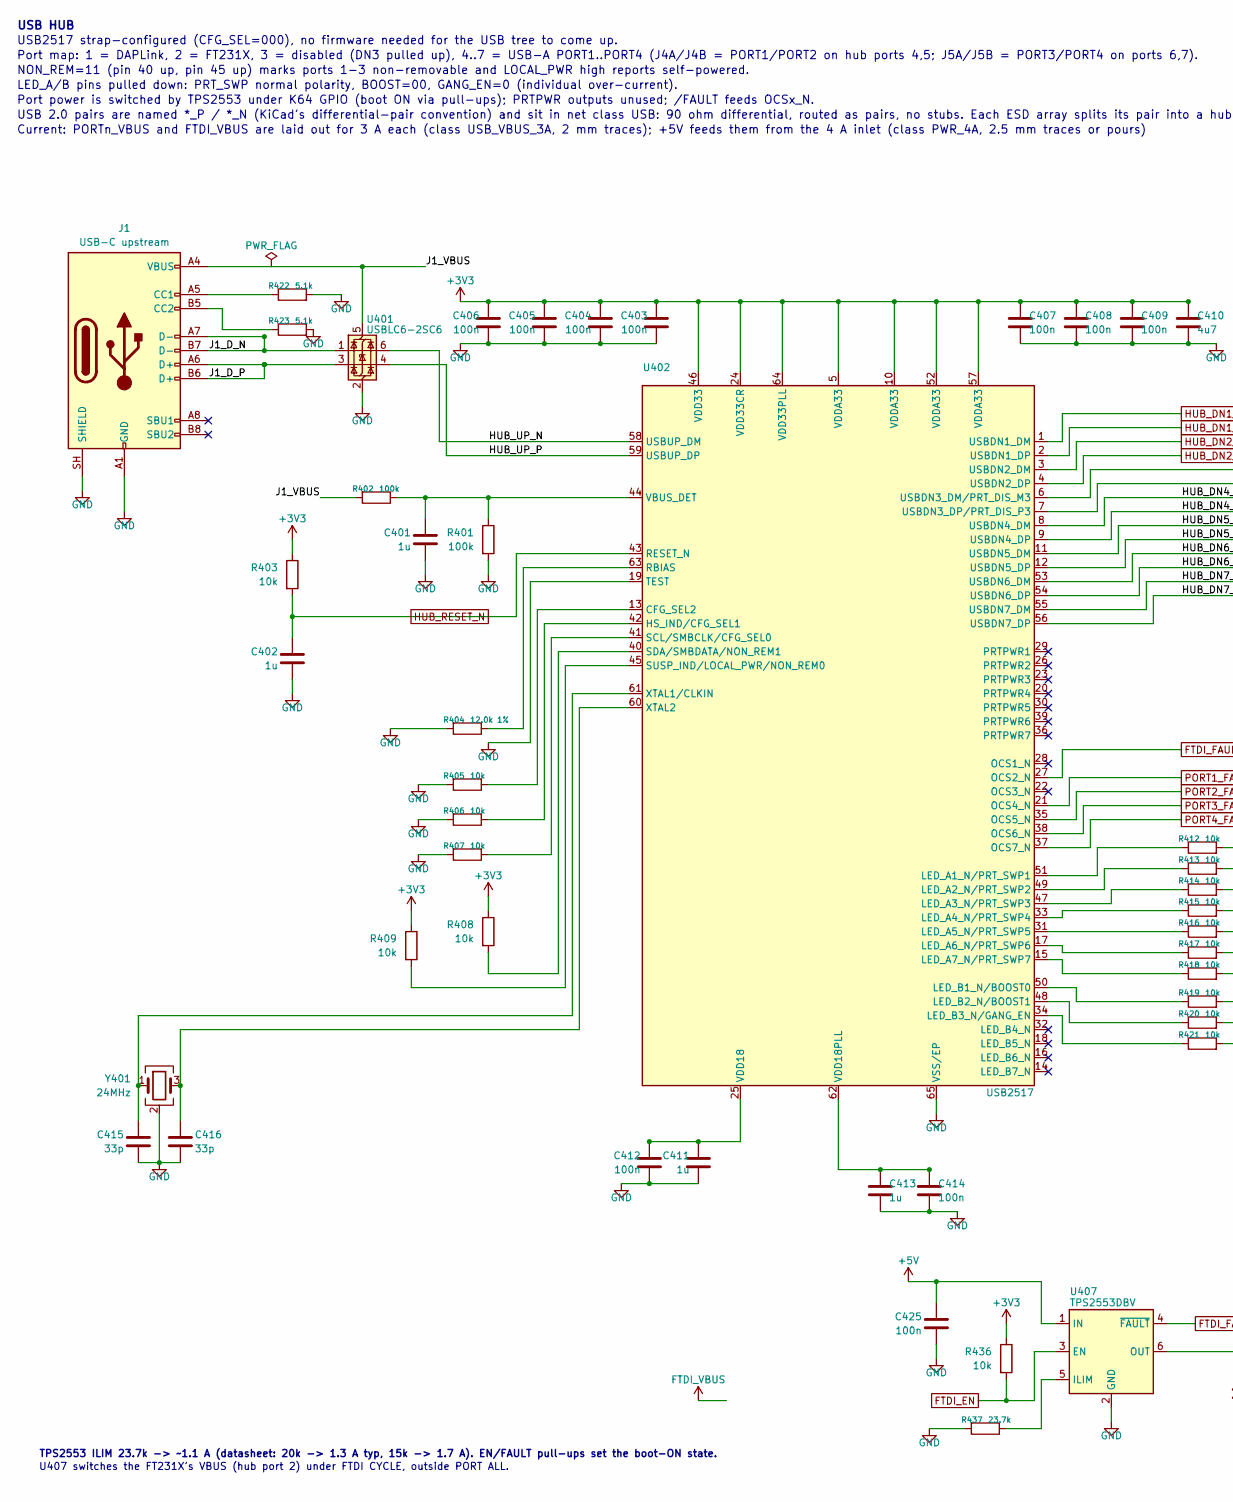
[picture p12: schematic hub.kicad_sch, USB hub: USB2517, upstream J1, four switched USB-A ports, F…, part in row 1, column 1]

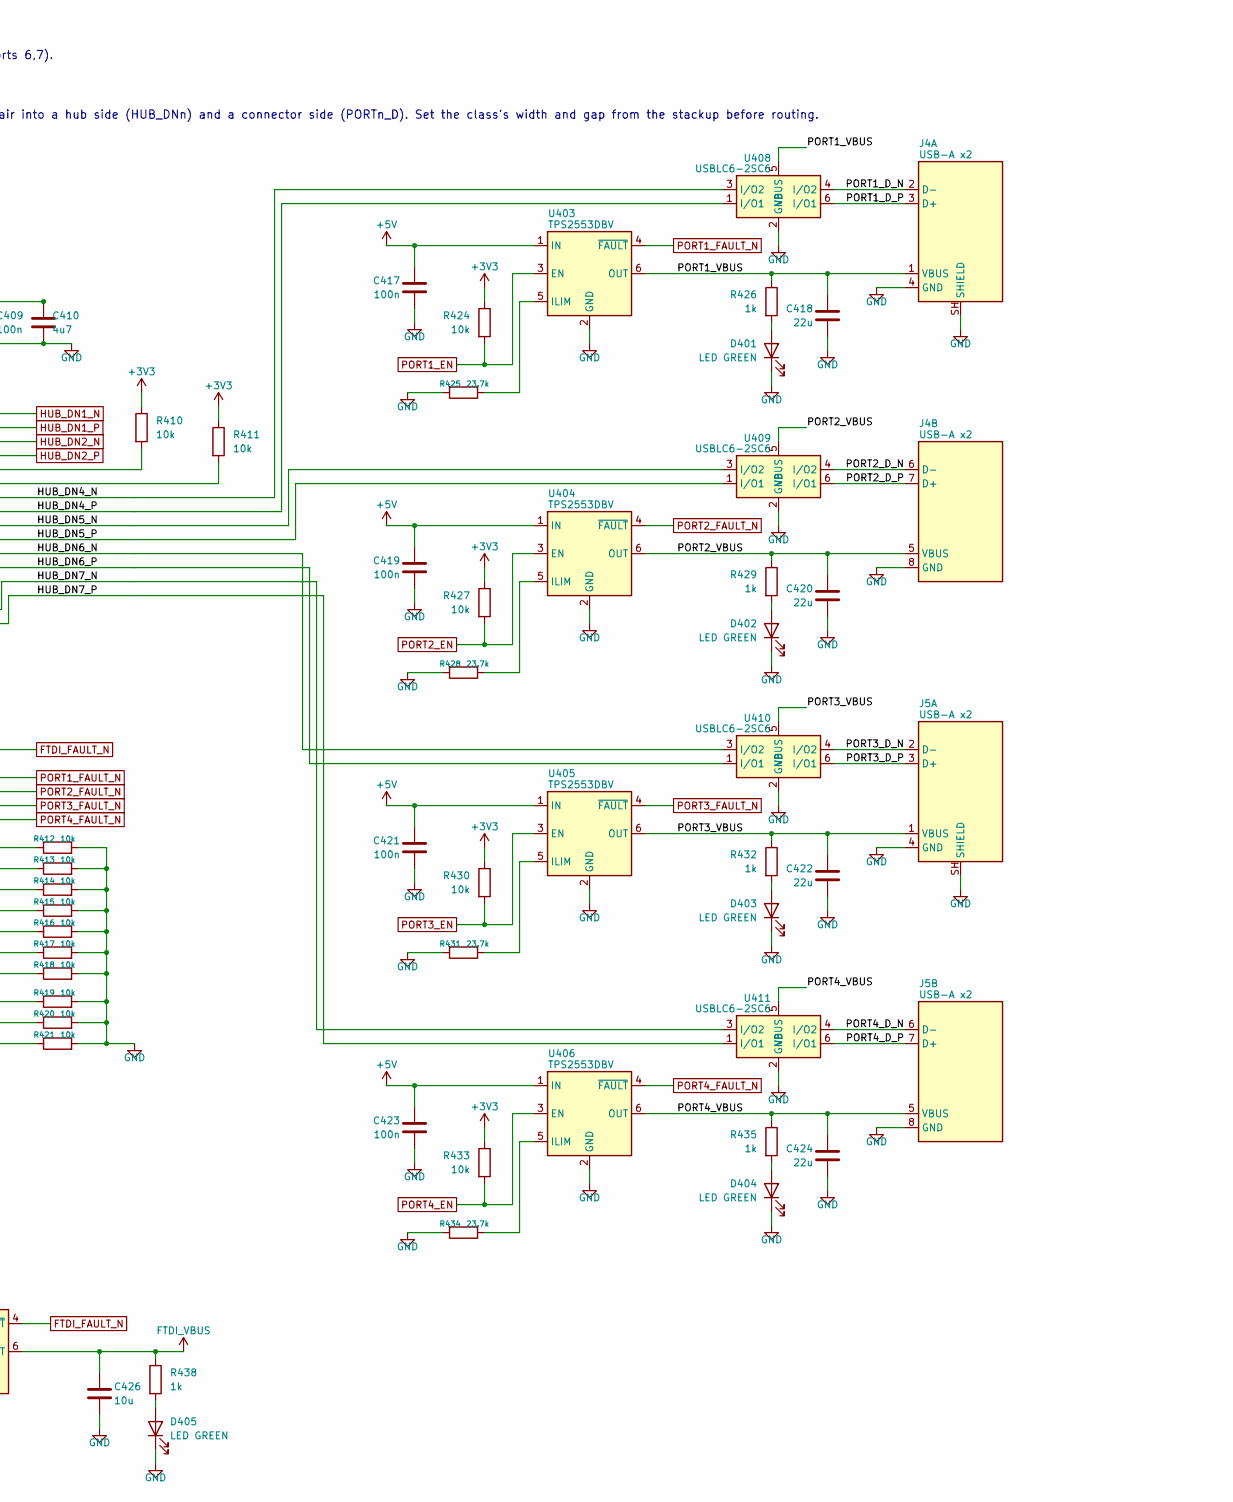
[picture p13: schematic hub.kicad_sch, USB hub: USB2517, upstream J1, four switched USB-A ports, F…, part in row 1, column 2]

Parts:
C401, C402, C411, C413: 1u; C_0603_1608Metric
C403, C404, C405, C406, C407, C408, C409, C412, C414, C417, C419, C421, C423, C425: 100n; C_0603_1608Metric
C410: 4u7; C_0805_2012Metric
C415, C416: 33p; C_0603_1608Metric
C418, C420, C422, C424: 22u; C_1206_3216Metric
C426: 10u; C_0805_2012Metric
D401, D402, D403, D404, D405: LED GREEN; LED_0603_1608Metric
J1: USB-C upstream; USB_C_Receptacle_GCT_USB4105-xx-A_16P_TopMnt_Horizontal_Peg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
J4, J5: USB-A x2; USB_A_Wuerth_61400826021_Horizontal_Stacked
R401, R402: 100k; R_0603_1608Metric
R403, R405, R406, R407, R408, R409, R410, R411, R412, R413, R414, R415, R416, R417, R418, R419, R420, R421, R424, R427, R430, R433, R436: 10k; R_0603_1608Metric
R404: 12.0k 1%; R_0603_1608Metric
R422, R423: 5.1k; R_0603_1608Metric
R425, R428, R431, R434, R437: 23.7k; R_0603_1608Metric
R426, R429, R432, R435, R438: 1k; R_0603_1608Metric
U401, U408, U409, U410, U411: USBLC6-2SC6; SOT-23-6
U402: USB2517; QFN-64-1EP_9x9mm_P0.5mm_EP7.15x7.15mm
U403, U404, U405, U406, U407: TPS2553DBV; SOT-23-6
Y401: 24MHz; Crystal_SMD_3225-4Pin_3.2x2.5mm

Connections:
/USB hub/HUB_DN4_N: U402.8 (USBDN4_DM), U408.3 (I/O2)
/USB hub/HUB_DN4_P: U402.9 (USBDN4_DP), U408.1 (I/O1)
/USB hub/HUB_DN5_N: U402.11 (USBDN5_DM), U409.3 (I/O2)
/USB hub/HUB_DN5_P: U402.12 (USBDN5_DP), U409.1 (I/O1)
/USB hub/HUB_DN6_N: U402.53 (USBDN6_DM), U410.3 (I/O2)
/USB hub/HUB_DN6_P: U402.54 (USBDN6_DP), U410.1 (I/O1)
/USB hub/HUB_DN7_N: U402.55 (USBDN7_DM), U411.3 (I/O2)
/USB hub/HUB_DN7_P: U402.56 (USBDN7_DP), U411.1 (I/O1)
/USB hub/HUB_UP_N: U401.6 (I/O1), U402.58 (USBUP_DM)
/USB hub/HUB_UP_P: U401.4 (I/O2), U402.59 (USBUP_DP)
/USB hub/J1_D_N: J1.A7 (D-), J1.B7 (D-), U401.1 (I/O1)
/USB hub/J1_D_P: J1.A6 (D+), J1.B6 (D+), U401.3 (I/O2)
/USB hub/J1_VBUS: J1.A4 (VBUS), J1.A9 (VBUS), J1.B4 (VBUS), J1.B9 (VBUS), R402.2, U401.5 (VBUS)
/USB hub/PORT1_D_N: J4.2 (D-), U408.4 (I/O2)
/USB hub/PORT1_D_P: J4.3 (D+), U408.6 (I/O1)
/USB hub/PORT1_VBUS: C418.1, J4.1 (VBUS), R426.1, U403.6 (OUT), U408.5 (VBUS)
/USB hub/PORT2_D_N: J4.6 (D-), U409.4 (I/O2)
/USB hub/PORT2_D_P: J4.7 (D+), U409.6 (I/O1)
/USB hub/PORT2_VBUS: C420.1, J4.5 (VBUS), R429.1, U404.6 (OUT), U409.5 (VBUS)
/USB hub/PORT3_D_N: J5.2 (D-), U410.4 (I/O2)
/USB hub/PORT3_D_P: J5.3 (D+), U410.6 (I/O1)
/USB hub/PORT3_VBUS: C422.1, J5.1 (VBUS), R432.1, U405.6 (OUT), U410.5 (VBUS)
/USB hub/PORT4_D_N: J5.6 (D-), U411.4 (I/O2)
/USB hub/PORT4_D_P: J5.7 (D+), U411.6 (I/O1)
/USB hub/PORT4_VBUS: C424.1, J5.5 (VBUS), R435.1, U406.6 (OUT), U411.5 (VBUS)
FTDI_EN: R436.2, U407.3 (EN); also elsewhere on the board
FTDI_FAULT_N: U402.27 (OCS2_N), U407.4 (~FAULT); also elsewhere on the board
FTDI_VBUS: C426.1, R438.1, U407.6 (OUT); also elsewhere on the board
HUB_DN1_N: U402.1 (USBDN1_DM); also elsewhere on the board
HUB_DN1_P: U402.2 (USBDN1_DP); also elsewhere on the board
HUB_DN2_N: U402.3 (USBDN2_DM); also elsewhere on the board
HUB_DN2_P: U402.4 (USBDN2_DP); also elsewhere on the board
HUB_RESET_N: C402.1, R403.2, U402.43 (RESET_N); also elsewhere on the board
unnamed: D401.2 (A), R426.2
unnamed: D402.2 (A), R429.2
unnamed: D403.2 (A), R432.2
unnamed: D404.2 (A), R435.2
unnamed: D405.2 (A), R438.2
unnamed: J1.A5 (CC1), R422.1
unnamed: J1.B5 (CC2), R423.1
unnamed: R405.1, U402.13 (CFG_SEL2)
unnamed: R406.1, U402.42 (HS_IND/CFG_SEL1)
unnamed: R412.1, U402.51 (LED_A1_N/PRT_SWP1)
unnamed: R413.1, U402.49 (LED_A2_N/PRT_SWP2)
unnamed: R414.1, U402.47 (LED_A3_N/PRT_SWP3)
unnamed: R415.1, U402.33 (LED_A4_N/PRT_SWP4)
unnamed: R416.1, U402.31 (LED_A5_N/PRT_SWP5)
unnamed: R417.1, U402.17 (LED_A6_N/PRT_SWP6)
unnamed: R418.1, U402.15 (LED_A7_N/PRT_SWP7)
unnamed: R419.1, U402.50 (LED_B1_N/BOOST0)
unnamed: R420.1, U402.48 (LED_B2_N/BOOST1)
unnamed: R421.1, U402.34 (LED_B3_N/GANG_EN)
unnamed: R404.1, U402.63 (RBIAS)
unnamed: R407.1, U402.41 (SCL/SMBCLK/CFG_SEL0)
unnamed: R408.2, U402.40 (SDA/SMBDATA/NON_REM1)
unnamed: R409.2, U402.45 (SUSP_IND/LOCAL_PWR/NON_REM0)
unnamed: R410.2, U402.6 (USBDN3_DM/PRT_DIS_M3)
unnamed: R411.2, U402.7 (USBDN3_DP/PRT_DIS_P3)
unnamed: C401.1, R401.1, R402.1, U402.44 (VBUS_DET)
unnamed: C411.1, C412.1, U402.25 (VDD18)
unnamed: C413.1, C414.1, U402.62 (VDD18PLL)
unnamed: C415.1, U402.61 (XTAL1/CLKIN), Y401.1
unnamed: C416.1, U402.60 (XTAL2), Y401.3
unnamed: R425.1, U403.5 (ILIM)
unnamed: R428.1, U404.5 (ILIM)
unnamed: R431.1, U405.5 (ILIM)
unnamed: R434.1, U406.5 (ILIM)
unnamed: R437.1, U407.5 (ILIM)
PORT1_EN: R424.2, U403.3 (EN); also elsewhere on the board
PORT1_FAULT_N: U402.21 (OCS4_N), U403.4 (~FAULT); also elsewhere on the board
PORT2_EN: R427.2, U404.3 (EN); also elsewhere on the board
PORT2_FAULT_N: U402.35 (OCS5_N), U404.4 (~FAULT); also elsewhere on the board
PORT3_EN: R430.2, U405.3 (EN); also elsewhere on the board
PORT3_FAULT_N: U402.38 (OCS6_N), U405.4 (~FAULT); also elsewhere on the board
PORT4_EN: R433.2, U406.3 (EN); also elsewhere on the board
PORT4_FAULT_N: U402.37 (OCS7_N), U406.4 (~FAULT); also elsewhere on the board

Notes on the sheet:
USB HUB
USB2517 strap-configured (CFG_SEL=000), no firmware needed for the USB tree to come up.
Port map: 1 = DAPLink, 2 = FT231X, 3 = disabled (DN3 pulled up), 4..7 = USB-A PORT1..PORT4 (J4A/J4B = PORT1/PORT2 on hub ports 4,5; J5A/J5B = PORT3/PORT4 on ports 6,7).
NON_REM=11 (pin 40 up, pin 45 up) marks ports 1-3 non-removable and LOCAL_PWR high reports self-powered.
LED_A/B pins pulled down: PRT_SWP normal polarity, BOOST=00, GANG_EN=0 (individual over-current).
Port power is switched by TPS2553 under K64 GPIO (boot ON via pull-ups); PRTPWR outputs unused; /FAULT feeds OCSx_N.
USB 2.0 pairs are named *_P / *_N (KiCad's differential-pair convention) and sit in net class USB: 90 ohm differential, routed as pairs, no stubs. Each ESD array splits its pair into a hub side (HUB_DNn) and a connector side (PORTn_D). Set the class's width and gap from the stackup before routing.
Current: PORTn_VBUS and FTDI_VBUS are laid out for 3 A each (class USB_VBUS_3A, 2 mm traces); +5V feeds them from the 4 A inlet (class PWR_4A, 2.5 mm traces or pours)
TPS2553 ILIM 23.7k -> ~1.1 A (datasheet: 20k -> 1.3 A typ, 15k -> 1.7 A). EN/FAULT pull-ups set the boot-ON state.
U407 switches the FT231X's VBUS (hub port 2) under FTDI CYCLE, outside PORT ALL.

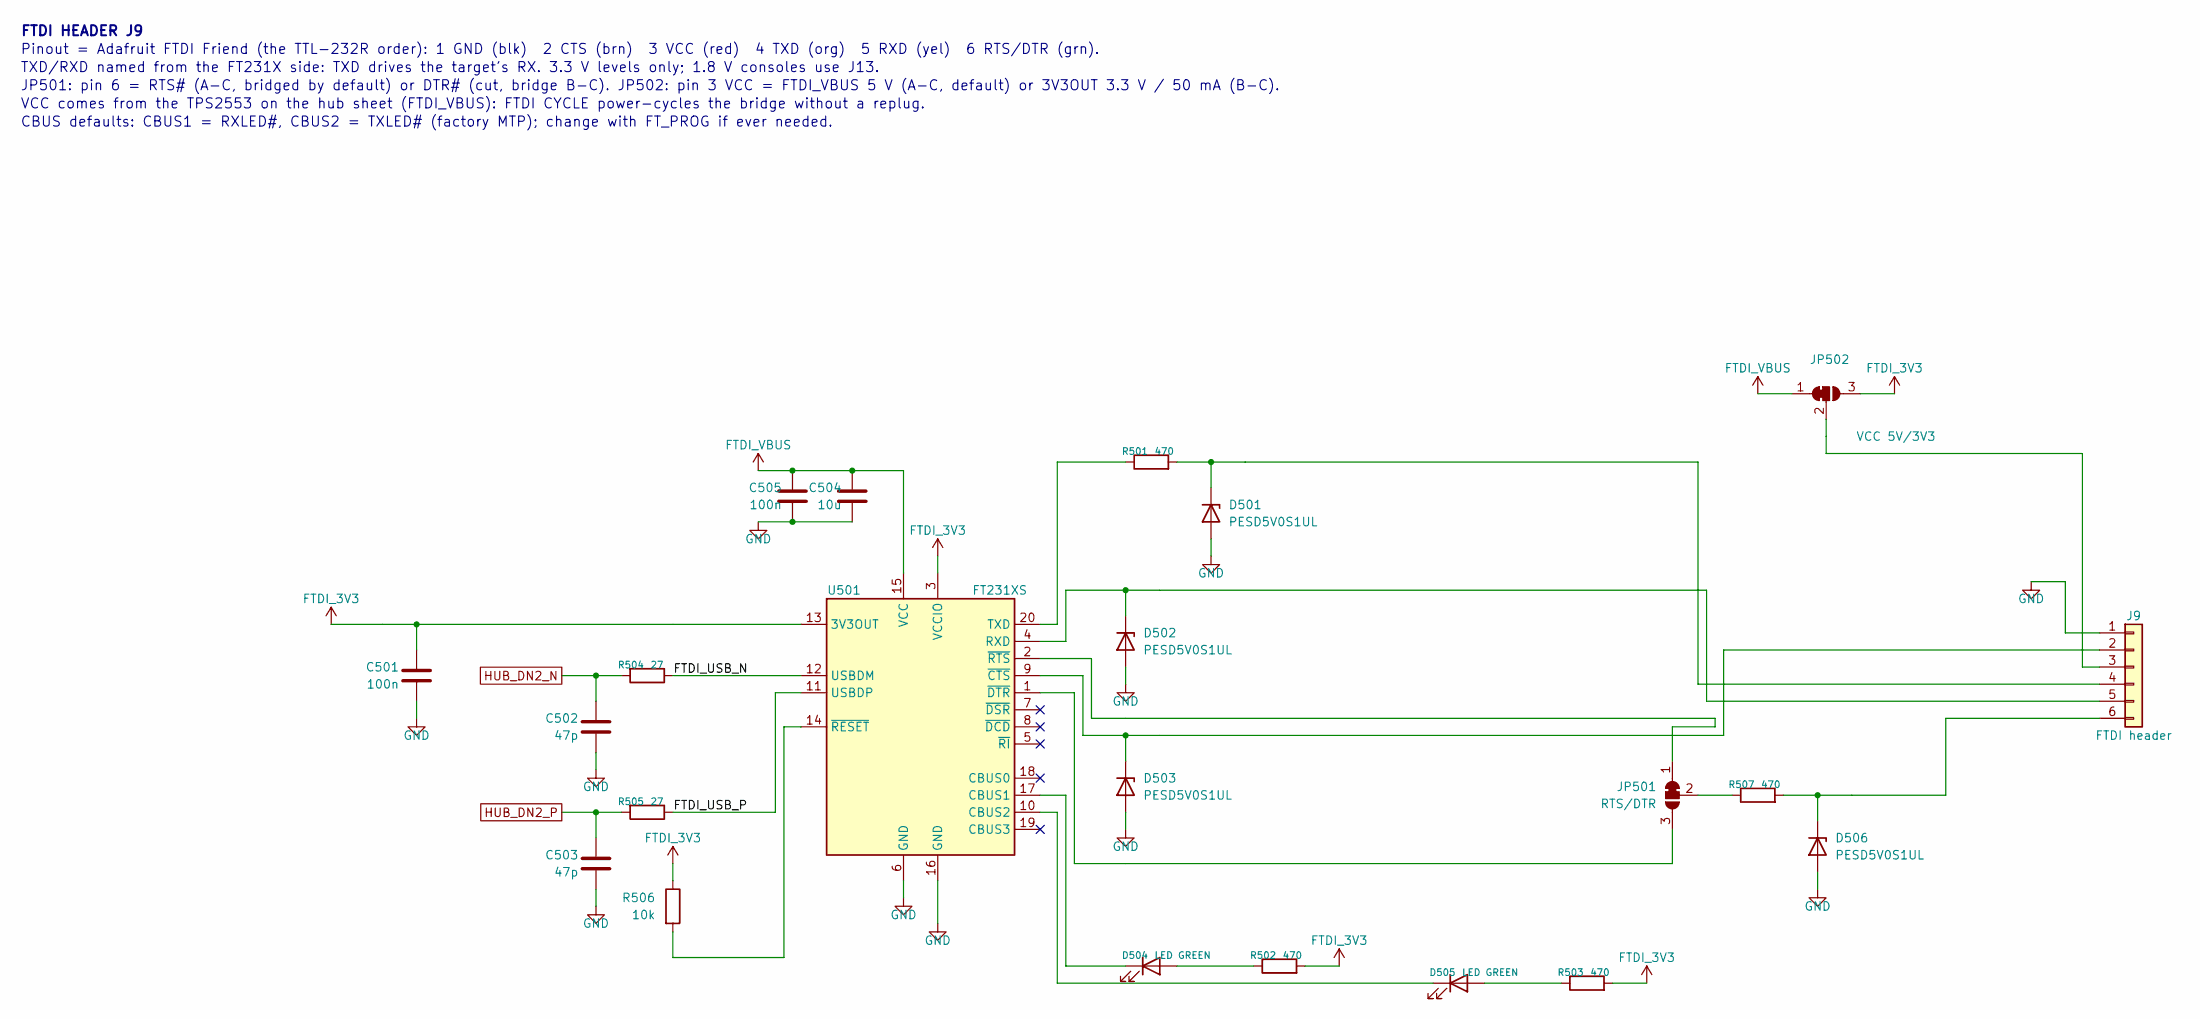
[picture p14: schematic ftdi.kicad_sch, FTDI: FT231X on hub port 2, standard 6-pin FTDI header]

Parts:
C501, C505: 100n; C_0603_1608Metric
C502, C503: 47p; C_0603_1608Metric
C504: 10u; C_0805_2012Metric
D501, D502, D503, D506: PESD5V0S1UL; D_SOD-882
D504, D505: LED GREEN; LED_0603_1608Metric
J9: FTDI header; PinHeader_1x06_P2.54mm_Horizontal
JP501: RTS/DTR; SolderJumper-3_P1.3mm_Bridged12_RoundedPad1.0x1.5mm
JP502: VCC 5V/3V3; SolderJumper-3_P1.3mm_Bridged12_RoundedPad1.0x1.5mm
R501, R502, R503, R507: 470; R_0603_1608Metric
R504, R505: 27; R_0603_1608Metric
R506: 10k; R_0603_1608Metric
U501: FT231XS; SSOP-20_3.9x8.7mm_P0.635mm

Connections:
/FTDI/FTDI_USB_N: R504.1, U501.12 (USBDM)
/FTDI/FTDI_USB_P: R505.1, U501.11 (USBDP)
FTDI_3V3: C501.1, JP502.3 (B), R502.2, R503.2, R506.1, U501.3 (VCCIO), U501.13 (3V3OUT)
FTDI_VBUS: C504.1, C505.1, JP502.1 (A), U501.15 (VCC); also elsewhere on the board
HUB_DN2_N: C502.1, R504.2; also elsewhere on the board
HUB_DN2_P: C503.1, R505.2; also elsewhere on the board
unnamed: D501.1 (K), J9.4, R501.2
unnamed: D502.1 (K), J9.5, U501.4 (RXD)
unnamed: D503.1 (K), J9.2, U501.9 (~CTS)
unnamed: D504.2 (A), R502.1
unnamed: D504.1 (K), U501.17 (CBUS1)
unnamed: D505.2 (A), R503.1
unnamed: D505.1 (K), U501.10 (CBUS2)
unnamed: D506.1 (K), J9.6, R507.2
unnamed: J9.3, JP502.2 (C)
unnamed: JP501.1 (A), U501.2 (~RTS)
unnamed: JP501.3 (B), U501.1 (~DTR)
unnamed: JP501.2 (C), R507.1
unnamed: R501.1, U501.20 (TXD)
unnamed: R506.2, U501.14 (~RESET)

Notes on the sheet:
FTDI HEADER J9
Pinout = Adafruit FTDI Friend (the TTL-232R order): 1 GND (blk) 2 CTS (brn) 3 VCC (red) 4 TXD (org) 5 RXD (yel) 6 RTS/DTR (grn).
TXD/RXD named from the FT231X side: TXD drives the target's RX. 3.3 V levels only; 1.8 V consoles use J13.
JP501: pin 6 = RTS# (A-C, bridged by default) or DTR# (cut, bridge B-C). JP502: pin 3 VCC = FTDI_VBUS 5 V (A-C, default) or 3V3OUT 3.3 V / 50 mA (B-C).
VCC comes from the TPS2553 on the hub sheet (FTDI_VBUS): FTDI CYCLE power-cycles the bridge without a replug.
CBUS defaults: CBUS1 = RXLED#, CBUS2 = TXLED# (factory MTP); change with FT_PROG if ever needed.

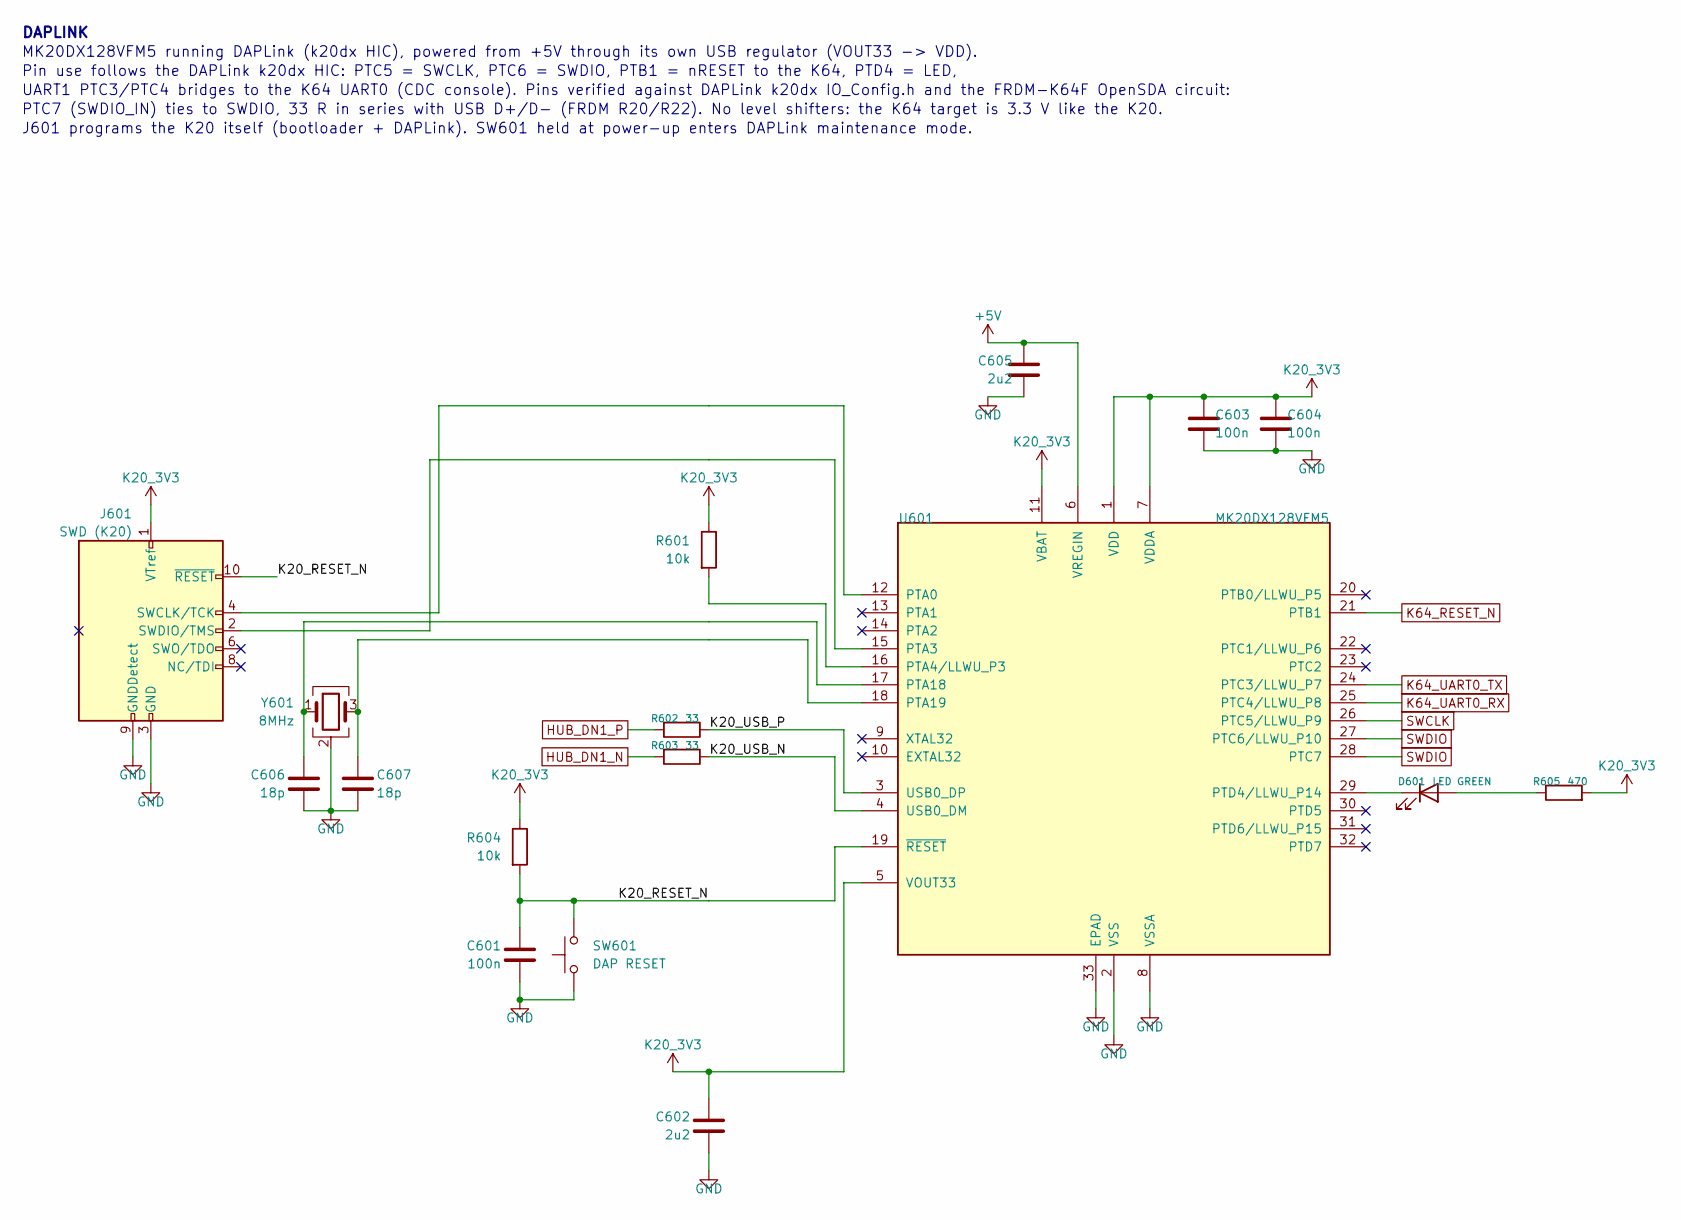
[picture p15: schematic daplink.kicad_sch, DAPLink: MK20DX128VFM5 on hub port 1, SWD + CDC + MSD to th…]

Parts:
C601, C603, C604: 100n; C_0603_1608Metric
C602, C605: 2u2; C_0603_1608Metric
C606, C607: 18p; C_0603_1608Metric
D601: LED GREEN; LED_0603_1608Metric
J601: SWD (K20); PinHeader_2x05_P1.27mm_Vertical
R601, R604: 10k; R_0603_1608Metric
R602, R603: 33; R_0603_1608Metric
R605: 470; R_0603_1608Metric
SW601: DAP RESET; SW_SPST_PTS645Sx43SMTR92
U601: MK20DX128VFM5; QFN-32-1EP_5x5mm_P0.5mm_EP3.45x3.45mm
Y601: 8MHz; Crystal_SMD_3225-4Pin_3.2x2.5mm

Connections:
/DAPLink/K20_RESET_N: C601.1, J601.10 (~RESET), R604.2, SW601.2, U601.19 (~RESET)
/DAPLink/K20_USB_N: R603.1, U601.4 (USB0_DM)
/DAPLink/K20_USB_P: R602.1, U601.3 (USB0_DP)
HUB_DN1_N: R603.2; also elsewhere on the board
HUB_DN1_P: R602.2; also elsewhere on the board
K20_3V3: C602.1, C603.1, C604.1, J601.1 (VTref), R601.1, R604.1, R605.2, U601.1 (VDD), U601.5 (VOUT33), U601.7 (VDDA), U601.11 (VBAT)
K64_RESET_N: U601.21 (PTB1); also elsewhere on the board
K64_UART0_RX: U601.25 (PTC4/LLWU_P8); also elsewhere on the board
K64_UART0_TX: U601.24 (PTC3/LLWU_P7); also elsewhere on the board
unnamed: D601.2 (A), R605.1
unnamed: D601.1 (K), U601.29 (PTD4/LLWU_P14)
unnamed: J601.4 (SWCLK/TCK), U601.12 (PTA0)
unnamed: J601.2 (SWDIO/TMS), U601.15 (PTA3)
unnamed: R601.2, U601.16 (PTA4/LLWU_P3)
unnamed: C606.1, U601.17 (PTA18), Y601.1
unnamed: C607.1, U601.18 (PTA19), Y601.3
SWCLK: U601.26 (PTC5/LLWU_P9); also elsewhere on the board
SWDIO: U601.27 (PTC6/LLWU_P10), U601.28 (PTC7); also elsewhere on the board

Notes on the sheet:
DAPLINK
MK20DX128VFM5 running DAPLink (k20dx HIC), powered from +5V through its own USB regulator (VOUT33 -> VDD).
Pin use follows the DAPLink k20dx HIC: PTC5 = SWCLK, PTC6 = SWDIO, PTB1 = nRESET to the K64, PTD4 = LED,
UART1 PTC3/PTC4 bridges to the K64 UART0 (CDC console). Pins verified against DAPLink k20dx IO_Config.h and the FRDM-K64F OpenSDA circuit:
PTC7 (SWDIO_IN) ties to SWDIO, 33 R in series with USB D+/D- (FRDM R20/R22). No level shifters: the K64 target is 3.3 V like the K20.
J601 programs the K20 itself (bootloader + DAPLink). SW601 held at power-up enters DAPLink maintenance mode.

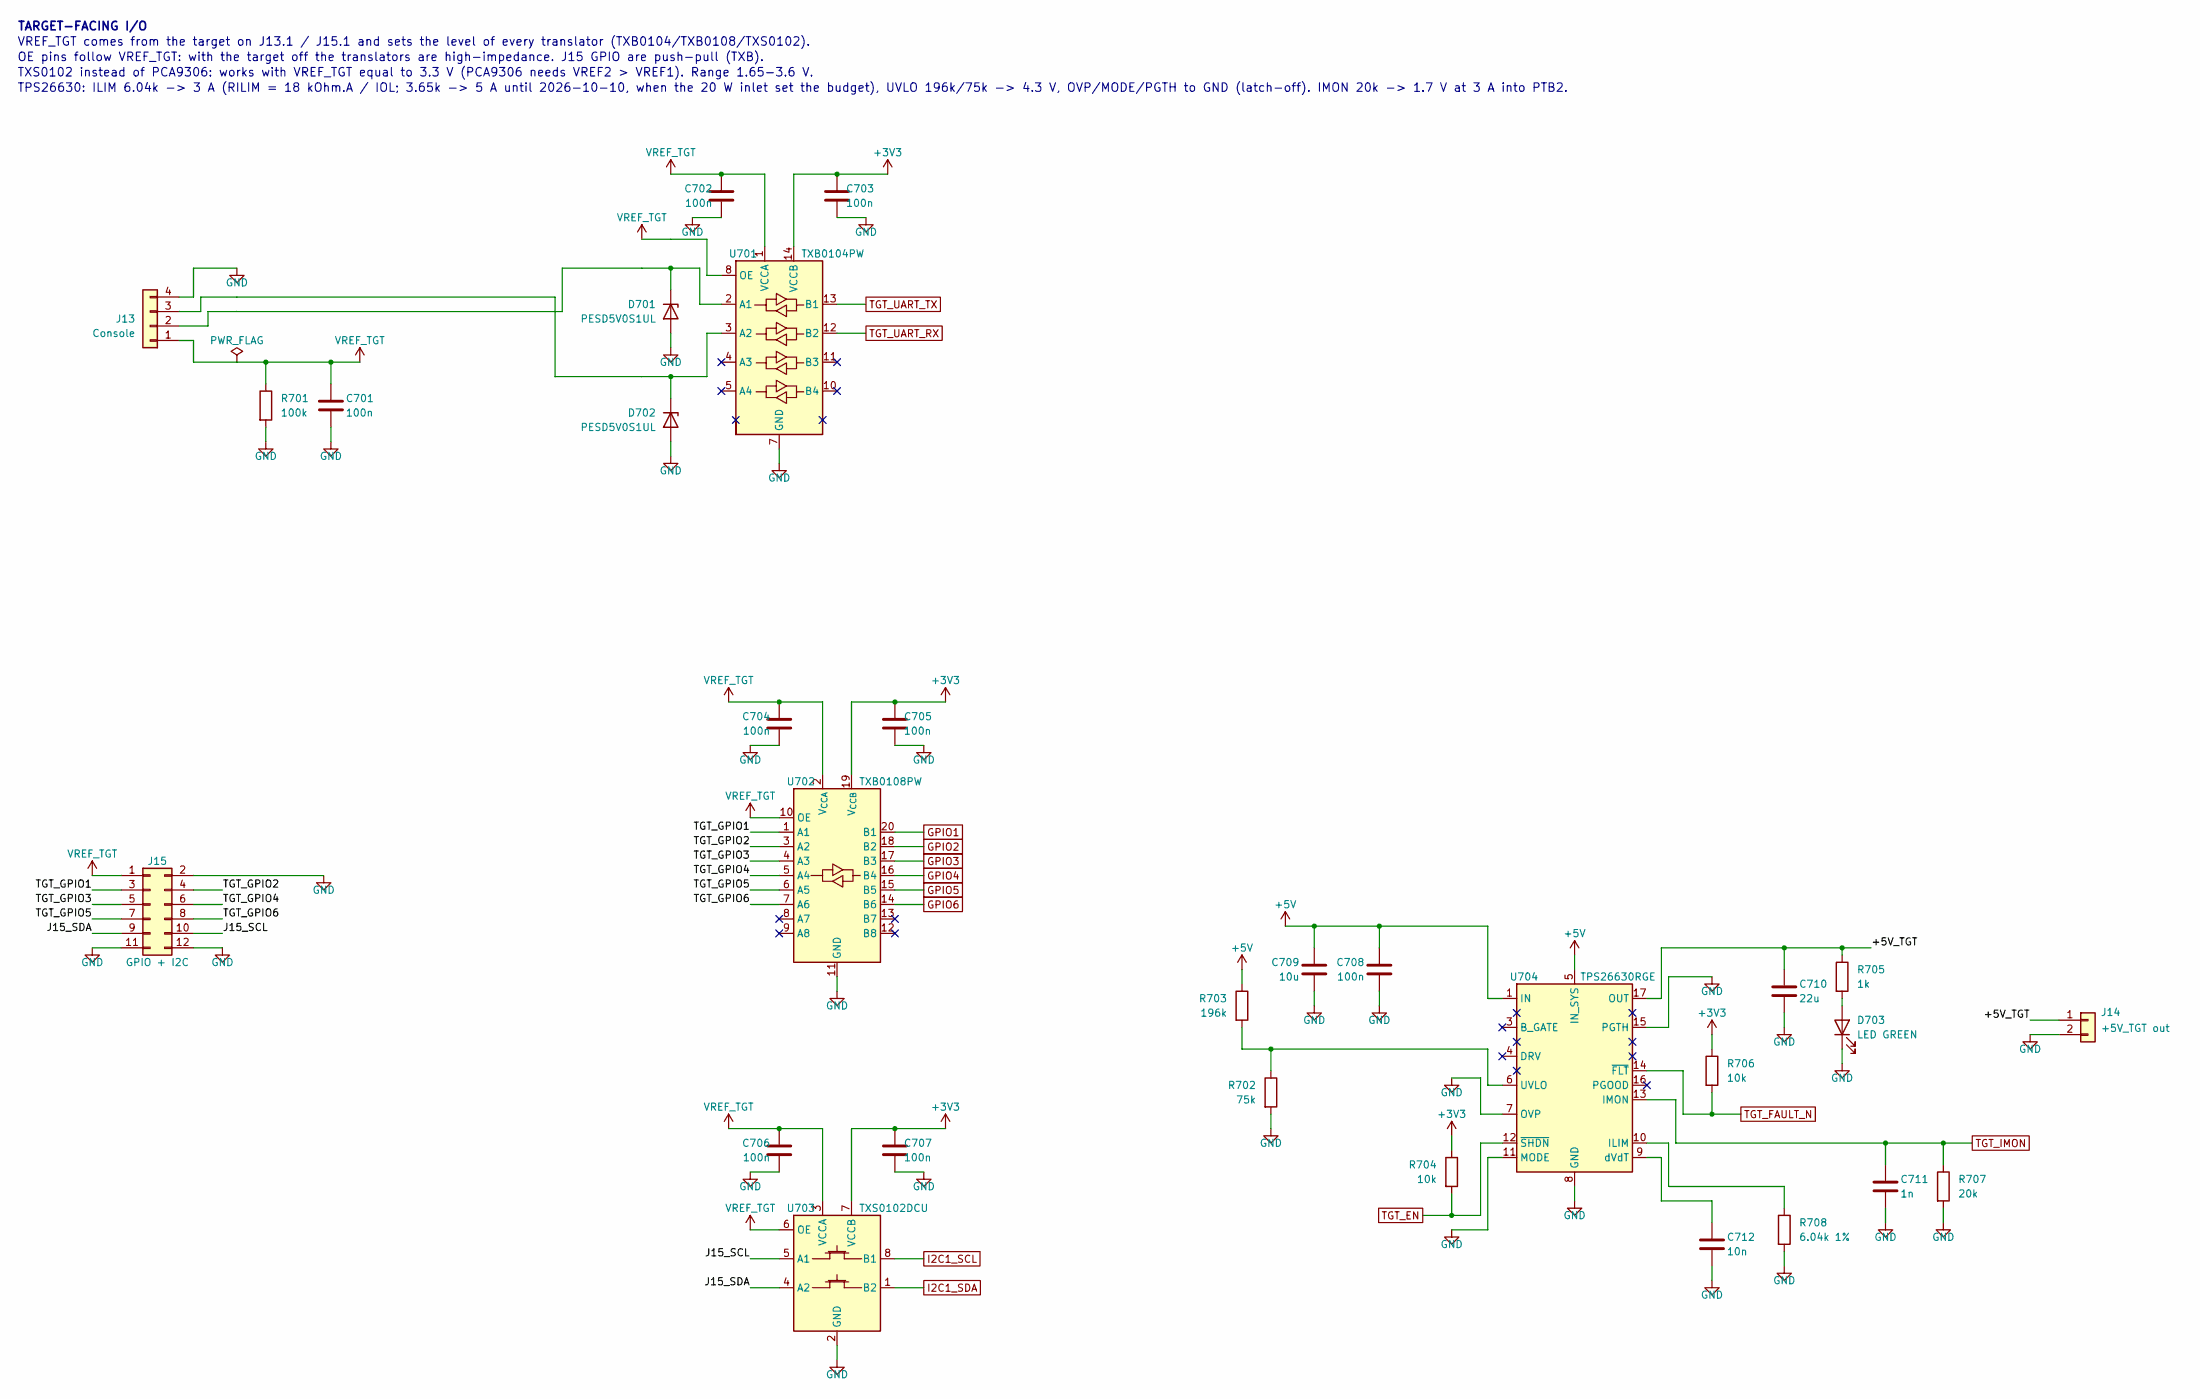
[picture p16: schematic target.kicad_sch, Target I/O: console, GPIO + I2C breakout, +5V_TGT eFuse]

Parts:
C701, C702, C703, C704, C705, C706, C707, C708: 100n; C_0603_1608Metric
C709: 10u; C_0805_2012Metric
C710: 22u; C_1206_3216Metric
C711: 1n; C_0603_1608Metric
C712: 10n; C_0603_1608Metric
D701, D702: PESD5V0S1UL; D_SOD-882
D703: LED GREEN; LED_0603_1608Metric
J13: Console; PhoenixContact_MC_1,5_4-G-3.5_1x04_P3.50mm_Horizontal
J14: +5V_TGT out; PhoenixContact_MSTBA_2,5_2-G-5,08_1x02_P5.08mm_Horizontal
J15: GPIO + I2C; PinHeader_2x06_P2.54mm_Vertical
R701: 100k; R_0603_1608Metric
R702: 75k; R_0603_1608Metric
R703: 196k; R_0603_1608Metric
R704, R706: 10k; R_0603_1608Metric
R705: 1k; R_0603_1608Metric
R707: 20k; R_0603_1608Metric
R708: 6.04k 1%; R_0603_1608Metric
U701: TXB0104PW; TSSOP-14_4.4x5mm_P0.65mm
U702: TXB0108PW; TSSOP-20_4.4x6.5mm_P0.65mm
U703: TXS0102DCU; VSSOP-8_2.3x2mm_P0.5mm
U704: TPS26630RGE; Texas_RGE0024H_VQFN-24-1EP_4x4mm_P0.5mm_EP2.7x2.7mm_Thermal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

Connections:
/Target I/O/+5V_TGT: C710.1, J14.1, R705.1, U704.17 (OUT), U704.18 (OUT)
/Target I/O/J15_SCL: J15.10, U703.5 (A1)
/Target I/O/J15_SDA: J15.9, U703.4 (A2)
/Target I/O/TGT_GPIO1: J15.3, U702.1 (A1)
/Target I/O/TGT_GPIO2: J15.4, U702.3 (A2)
/Target I/O/TGT_GPIO3: J15.5, U702.4 (A3)
/Target I/O/TGT_GPIO4: J15.6, U702.5 (A4)
/Target I/O/TGT_GPIO5: J15.7, U702.6 (A5)
/Target I/O/TGT_GPIO6: J15.8, U702.7 (A6)
GPIO1: U702.20 (B1); also elsewhere on the board
GPIO2: U702.18 (B2); also elsewhere on the board
GPIO3: U702.17 (B3); also elsewhere on the board
GPIO4: U702.16 (B4); also elsewhere on the board
GPIO5: U702.15 (B5); also elsewhere on the board
GPIO6: U702.14 (B6); also elsewhere on the board
I2C1_SCL: U703.8 (B1); also elsewhere on the board
I2C1_SDA: U703.1 (B2); also elsewhere on the board
unnamed: D701.1 (K), J13.2, U701.2 (A1)
unnamed: D702.1 (K), J13.3, U701.3 (A2)
unnamed: D703.2 (A), R705.2
unnamed: R708.1, U704.10 (ILIM)
unnamed: R702.1, R703.2, U704.6 (UVLO)
unnamed: C712.1, U704.9 (dVdT)
TGT_EN: R704.2, U704.12 (~SHDN); also elsewhere on the board
TGT_FAULT_N: R706.2, U704.14 (~FLT); also elsewhere on the board
TGT_IMON: C711.1, R707.1, U704.13 (IMON); also elsewhere on the board
TGT_UART_RX: U701.12 (B2); also elsewhere on the board
TGT_UART_TX: U701.13 (B1); also elsewhere on the board
VREF_TGT: C701.1, C702.1, C704.1, C706.1, J13.1, J15.1, R701.1, U701.1 (VCCA), U701.8 (OE), U702.2 (V_{CCA}), U702.10 (OE), U703.3 (VCCA), U703.6 (OE)

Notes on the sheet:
TARGET-FACING I/O
VREF_TGT comes from the target on J13.1 / J15.1 and sets the level of every translator (TXB0104/TXB0108/TXS0102).
OE pins follow VREF_TGT: with the target off the translators are high-impedance. J15 GPIO are push-pull (TXB).
TXS0102 instead of PCA9306: works with VREF_TGT equal to 3.3 V (PCA9306 needs VREF2 > VREF1). Range 1.65-3.6 V.
TPS26630: ILIM 6.04k -> 3 A (RILIM = 18 kOhm.A / IOL; 3.65k -> 5 A until 2026-10-10, when the 20 W inlet set the budget), UVLO 196k/75k -> 4.3 V, OVP/MODE/PGTH to GND (latch-off). IMON 20k -> 1.7 V at 3 A into PTB2.

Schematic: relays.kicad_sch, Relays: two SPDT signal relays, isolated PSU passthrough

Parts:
D801, D803, D805, D807: 1N4148W; D_SOD-123
D802, D804, D806: LED RED; LED_0603_1608Metric
J11, J12: COM/NO/NC; PhoenixContact_MC_1,5_3-G-3.5_1x03_P3.50mm_Horizontal
J18: PSU in (isolated); PhoenixContact_MSTBA_2,5_2-G-5,08_1x02_P5.08mm_Horizontal
J19: PSU out (isolated); PhoenixContact_MSTBA_2,5_2-G-5,08_1x02_P5.08mm_Horizontal
K801, K802: G6K-2F-Y DC5; Relay_DPDT_Omron_G6K-2F-Y
K803: JW1FSN-DC5V; Relay_SPDT_Panasonic_JW1_FormC
Q801, Q802: 2N7002; SOT-23
Q803: AO3400A; SOT-23
R801, R804, R807: 2.2k; R_0603_1608Metric
R802, R805, R808: 100k; R_0603_1608Metric
R803, R806, R809: 1k; R_0603_1608Metric
R810, R811: 1.8k; R_1206_3216Metric
R812: 10k; R_0603_1608Metric
U801: LTV-817; DIP-4_W7.62mm

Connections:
/Relays/PSU_SENSE: D807.1 (K), R810.1, U801.1
/Relays/PSU_SENSE_R: R810.2, R811.1
/Relays/PSU_VOUT: J19.1, K803.4 (NO)
/Relays/PSU_VP: J18.1, K803.6 (COM), R811.2
unnamed: D801.2 (A), D802.1 (K), K801.1, Q801.3 (D)
unnamed: D802.2 (A), R801.2
unnamed: D803.2 (A), D804.1 (K), K802.1, Q802.3 (D)
unnamed: D804.2 (A), R804.2
unnamed: D805.2 (A), D806.1 (K), K803.8 (COIL-), Q803.3 (D)
unnamed: D806.2 (A), R807.2
unnamed: J11.1, K801.3
unnamed: J11.2, K801.4
unnamed: J11.3, K801.2
unnamed: J12.1, K802.3
unnamed: J12.2, K802.4
unnamed: J12.3, K802.2
unnamed: Q801.1 (G), R802.1, R803.1
unnamed: Q802.1 (G), R805.1, R806.1
unnamed: Q803.1 (G), R808.1, R809.1
PSU_GND: D807.2 (A), J18.2, J19.2, U801.2
PSU_PRESENT_N: R812.2, U801.4; also elsewhere on the board
RLY1_DRV: R803.2; also elsewhere on the board
RLY2_DRV: R806.2; also elsewhere on the board
RLY_PSU_DRV: R809.2; also elsewhere on the board

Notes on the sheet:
RELAYS AND PASSTHROUGH
K801/K802 G6K-2F-Y: pole 1 used (COM 3, NC 2, NO 4), pole 2 unused. Coils boot de-energized (gate pull-downs).
Red LEDs sit across each coil and show the energized state. Flyback 1N4148W on every coil.
Passthrough J18 -> K803 (NO contact) -> J19 on nets PSU_VP / PSU_VOUT / PSU_GND that touch no board net: PSU_GND is its own ground.
Only the optocoupler's emitter sits across the passthrough, sized for 5-30 V. No indicator LED there.
K803 JW1FSN pad map COM=6 NO=4 NC=2: VERIFY against the Panasonic terminal drawing before fab.
Current: the passthrough J18 -> K803 -> J19 (PSU_VP, PSU_VOUT, PSU_GND) is laid out for 3 A continuous: class PSU_3A, 2 mm traces or pours, two vias per layer change.
Opto LED: 2x1.8k 1206 in series, 1 mA at 5 V, 8 mA / 0.12 W each at 30 V. The antiparallel 1N4148W protects a reversed PSU.
PSU_PRESENT_N is active low at the K64.

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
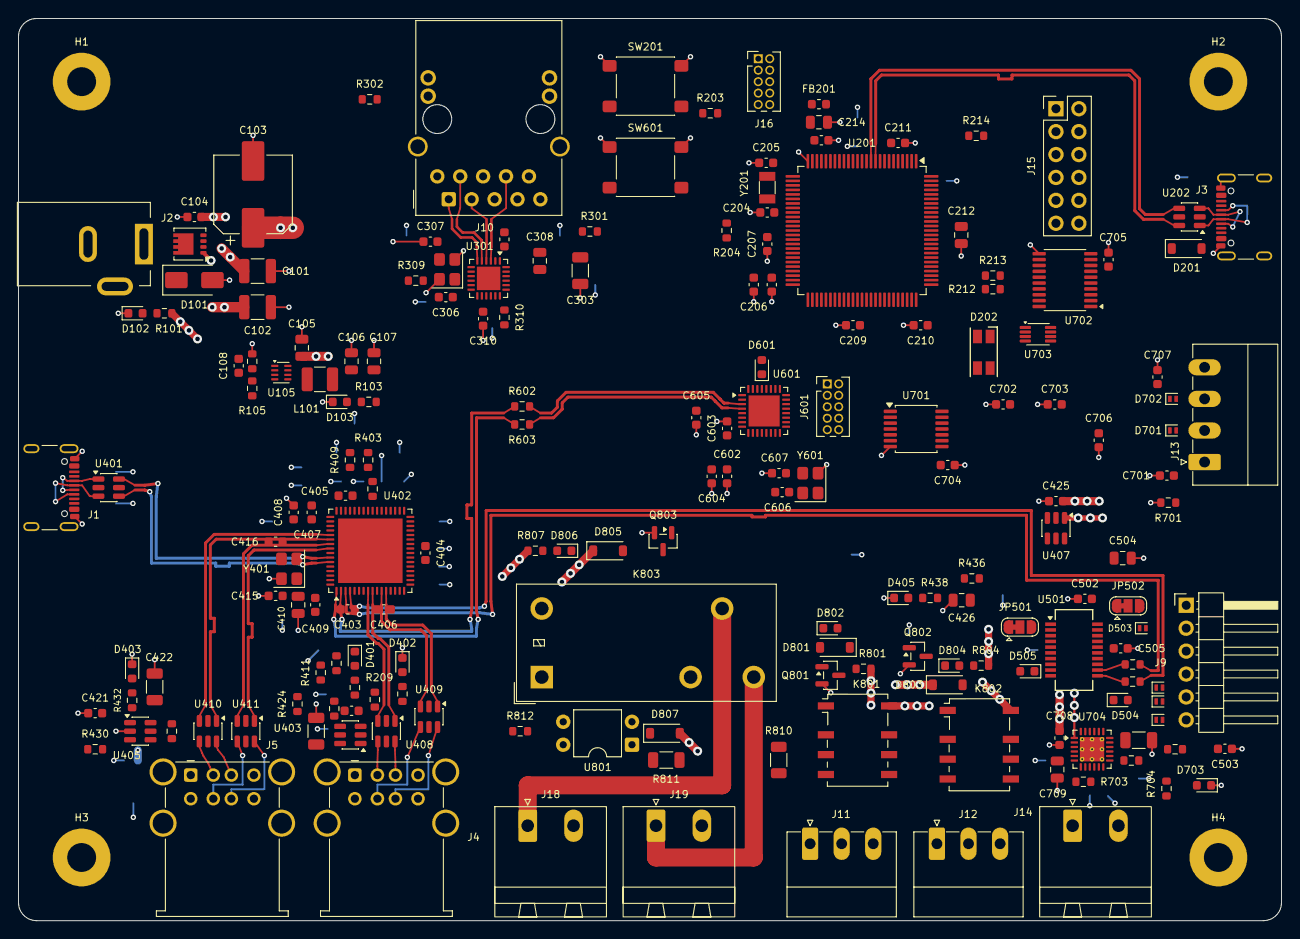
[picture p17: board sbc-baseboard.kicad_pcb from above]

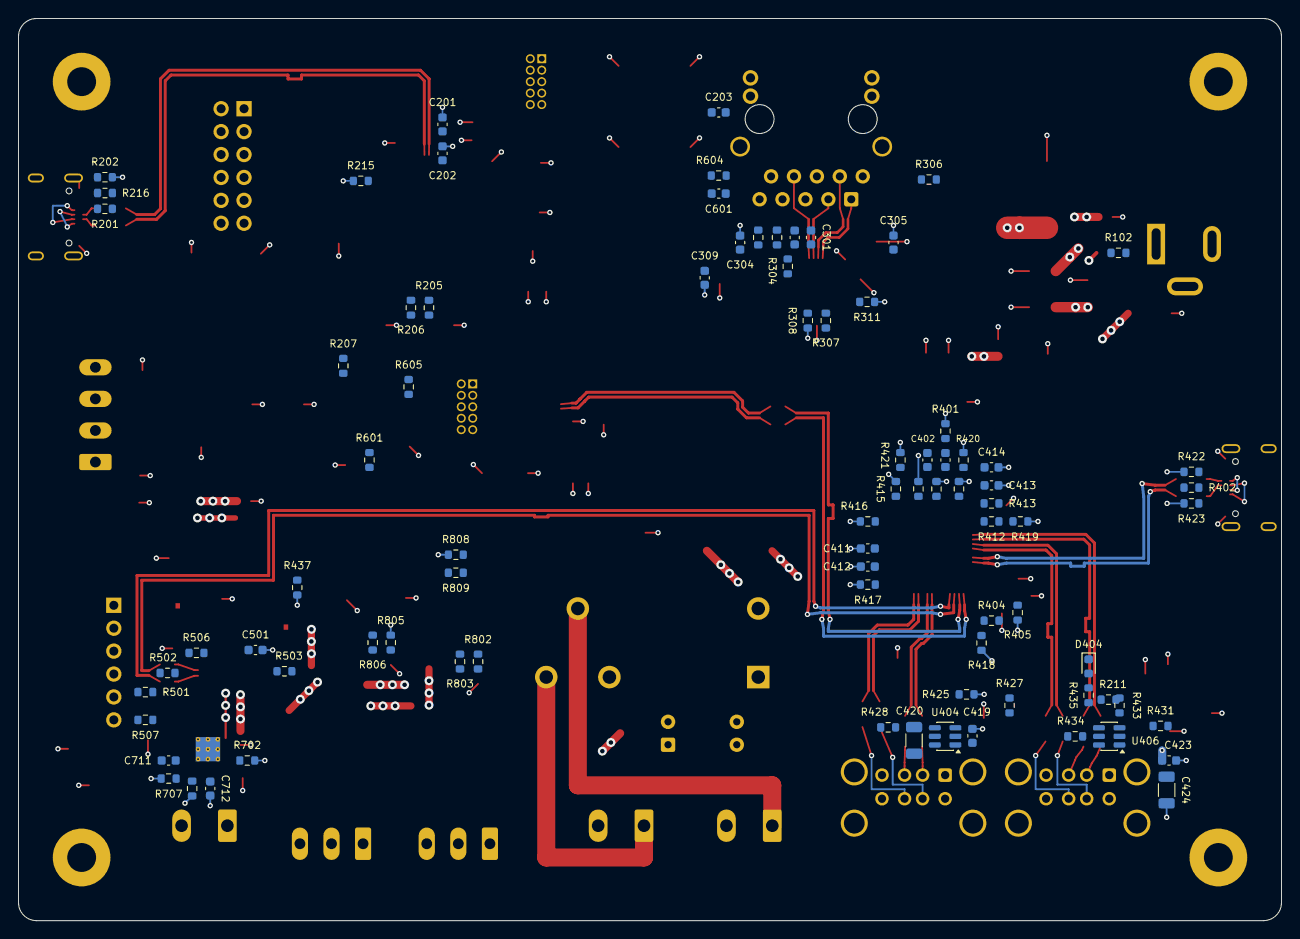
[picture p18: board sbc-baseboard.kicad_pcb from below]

Board: 6 copper layers, 140.0 x 100.0 mm, 271 parts (84 on the bottom side), 222 nets.

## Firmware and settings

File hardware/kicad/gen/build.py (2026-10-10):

#!/usr/bin/env python3
"""Generate the KiCad project, run ERC, export the PDF.

    ./build.py            # writes ../sbc-baseboard/*, runs ERC + PDF export

The generated files are a first pass. Once they are edited by hand in KiCad,
the KiCad files are the source of truth and this generator is retired.
"""
import os, re, sys, json, subprocess, shutil, glob
sys.path.insert(0, os.path.dirname(os.path.abspath(__file__)))
import kisym
from sch import Schematic, uid, set_project, DATE
from kit import Sheet, FP
import sheets_a, sheets_b, sheets_c

HERE = os.path.dirname(os.path.abspath(__file__))
OUT = os.path.normpath(os.path.join(HERE, "..", "sbc-baseboard"))
LIBS = os.path.normpath(os.path.join(HERE, "..", "libs"))          # the ecad-libraries submodule
PROJECT = "sbc-baseboard"
PAIR_CLASSES = {"USB", "ETH"}                        # the controlled-impedance classes; every _P/_N net is in one (checked at build)
# the house symbol libraries, by their nickname (file stem), as the project's sym-lib-table names them
kisym.EXTRA_LIBS = {os.path.splitext(os.path.basename(f))[0]: f for f in glob.glob(os.path.join(LIBS, "symbols", "*.kicad_sym"))}


def netclass(name, **kw):
    """A net class as KiCad 10 writes it (net_settings version 4). Geometry is KiCad's default;
    the USB class's differential width and gap are set from the stackup before routing."""
    c = {"bus_width": 12, "clearance": 0.2, "diff_pair_gap": 0.25, "diff_pair_via_gap": 0.25, "diff_pair_width": 0.2,   # Default clearance 0.15: 0.5 mm pitch parts (fab minimum 0.127)
         "line_style": 0, "microvia_diameter": 0.3, "microvia_drill": 0.1, "name": name, "pcb_color": "rgba(0, 0, 0, 0.000)",
         "priority": 2147483647, "schematic_color": "rgba(0, 0, 0, 0.000)", "track_width": 0.2, "via_diameter": 0.6,     # 0.2 mm signal tracks, 0.6/0.3 vias: layout.md 5 and 9
         "via_drill": 0.3, "wire_width": 6}
    c.update(kw)
    return c


def net_settings():
    # USB 2.0 pairs: every net named <base>_P / <base>_N (J1_D, J3_D, PORTn_D on the connector side; K64_USB, FTDI_USB at the chips; HUB_UP, HUB_DNn at the hub)
    # 90 ohm differential microstrip on Advanced Circuits' standard 6-layer 62 mil stackup (2026-10-09): 1 oz outer
    # copper over two 2116 sheets (9.8 mil pressed, er 4.3) to the L2 / L5 ground planes -> 0.33 mm traces, 0.20 mm gap; the ETH
    # pairs 100 ohm -> 0.29 mm, 0.25 mm gap (edge-coupled microstrip estimate); the fab's impedance calculator has the last word
    # current-carrying classes, the current in the name (1 oz outer copper, 10 C rise: 3 A ~ 1.5 mm, 4 A ~ 2.3 mm)
    return {"classes": [netclass("Default", clearance=0.15), netclass("USB", priority=0, diff_pair_width=0.33, diff_pair_gap=0.2, track_width=0.33),
                        netclass("PSU_3A", priority=1, track_width=2.0, clearance=0.3, via_diameter=1.0, via_drill=0.5),
                        netclass("USB_VBUS_3A", priority=2, track_width=2.0, via_diameter=1.0, via_drill=0.5),
                        netclass("PWR_4A", priority=3, track_width=2.5, via_diameter=1.0, via_drill=0.5),   # +5V from the 4 A inlet, and the target rail behind the 3 A eFuse
                        netclass("PSU_ISO", priority=4, track_width=0.25),
                        netclass("ETH", priority=5, diff_pair_width=0.29, diff_pair_gap=0.25, track_width=0.29),
                        netclass("PWR_1A", priority=6, track_width=0.6, clearance=0.15)],   # +3V3, routed (no room for a plane of it among the rails): 0.6 mm, since an inner 1 oz track carries about half of an outer one (IPC-2221); the default clearance, since it reaches 0.5 mm pitch pins   # 100 ohm MDI pairs on the same stackup (estimate; the fab's calculator rules)               # the opto's sense nets: isolated like PSU_3A, thin "meta": {"version": 4}, "net_colors": None,
            "netclass_assignments": None,
            "netclass_patterns": [{"netclass": "USB", "pattern": p} for p in ("*_USB_?", "*_D_?", "*HUB_UP_?", "*HUB_DN?_?")]   # sheet-local nets carry their sheet path: the leading * matches it
                               + [{"netclass": "PSU_3A", "pattern": p} for p in ("*PSU_VP", "*PSU_VOUT", "PSU_GND")]   # local nets carry their sheet path
                               + [{"netclass": "PSU_ISO", "pattern": "*PSU_SENSE*"}]
                               + [{"netclass": "ETH", "pattern": "*ETH_?D_?"}]
                               + [{"netclass": "USB_VBUS_3A", "pattern": p} for p in ("*PORT?_VBUS", "*FTDI_VBUS")]
                               + [{"netclass": "PWR_4A", "pattern": p} for p in ("+5V", "*+5V_TGT")]
                               + [{"netclass": "PWR_1A", "pattern": "+3V3"}]}


def main():
    os.makedirs(OUT, exist_ok=True)
    set_project(PROJECT)                          # UUIDs are derived in this project's namespace (see sch.py)
    plib = None                                   # every symbol comes from KiCad's libraries or the house submodule
    root = Schematic(PROJECT, "SBC development baseboard", "A3", 1, "/", file=f"{PROJECT}.kicad_sch")
    root.comments = ["140 x 80 mm, four M3. Spec: docs/hardware-spec.md"]
    defs = [("Power", "power.kicad_sch", sheets_a.power, 1), ("MCU", "mcu.kicad_sch", sheets_a.mcu, 2),
            ("Ethernet", "ethernet.kicad_sch", sheets_b.ethernet, 3), ("USB hub", "hub.kicad_sch", sheets_b.hub, 4),
            ("FTDI", "ftdi.kicad_sch", sheets_b.ftdi, 5), ("DAPLink", "daplink.kicad_sch", sheets_b.daplink, 6),
            ("Target I/O", "target.kicad_sch", sheets_c.target, 7), ("Relays", "relays.kicad_sch", sheets_c.relays, 8)]
    x, y = 30, 40
    for i, (name, file, fn, num) in enumerate(defs):
        suuid = uid("sheet", file)                # the (sheet ...) element in the root; the file has its own
        sh = fn(PROJECT, num, i + 2, "/" + suuid, plib)
        sh.emit(os.path.join(OUT, file), root.uuid)
        root.sheet(name, file, (x + (i % 4) * 60, y + (i // 4) * 40), (50, 25), suuid, i + 2)
    # root: mounting holes and the design summary
    for n in range(4):
        h = root.add("Mechanical", "MountingHole_Pad", f"H{n+1}", "M3", (40 + n * 15, 150), footprint=FP["HOLE"])
        root.pin_power(h, "1", "GND")
    notes = ["SBC DEVELOPMENT BASEBOARD - schematic first pass, generated 2026-10-04",
             "One board for remote development on an attached SBC: K64 as USB HID to the target and Ethernet to the workstation,",
             "four switched USB-A ports, FT231X FTDI header, two isolated SPDT signal relays, level-shifted console and GPIO/I2C,",
             "switched +5V_TGT eFuse, and an isolated PSU passthrough on a 5 A relay. 5 V 4 A in on a 2.5 mm barrel jack. 140 x 100 mm, six layers.",
             "",
             "VERIFY BEFORE FAB (also in docs/hardware-spec.md section 8):",
             "  - K803 JW1FSN contact pad mapping (COM 6 / NO 4 / NC 2) against the Panasonic drawing",
             "  - DAPLink K20: pins verified against DAPLink k20dx and the FRDM-K64F OpenSDA circuit; confirm SWD at bring-up",
             "  - TPS2553 ILIM at bring-up; TPS26630 UVLO/ILIM (6.04k -> 3 A); the inlet FET's drop at 4 A",
             "  - USB2517 VBUS_DET divider (10k/22k) vs the EVB; LED_A/B strap pull-downs",
             "  - KSZ8081 crystal load (22 pF) and 50 MHz REF_CLK series resistor",
             "Reference designators: 1xx power, 2xx MCU, 3xx Ethernet, 4xx hub, 5xx FTDI, 6xx DAPLink, 7xx target I/O, 8xx relays and passthrough."]
    for i, ln in enumerate(notes):
        root.text(ln, (30, 175 + i * 3.2), size=1.6, bold=(i == 0))
    root.emit(os.path.join(OUT, f"{PROJECT}.kicad_sch"), root.uuid)
    # project file, project symbol library, lib table
    # board constraints: Advanced Circuits' standard-process minimums (0.005" trace/space, 0.010" copper to edge,
    # 0.006" drill); thermal vias in the library footprints are 0.2 mm, which the fab allows
    rules = {"min_clearance": 0.127, "min_track_width": 0.127, "min_through_hole_diameter": 0.2, "min_hole_clearance": 0.25,
             "min_hole_to_hole": 0.25, "min_copper_edge_clearance": 0.25, "min_via_diameter": 0.5, "min_via_annular_width": 0.125,
             "min_connection": 0.127, "solder_mask_to_copper_clearance": 0.0,
             "min_text_height": 0.7, "min_text_thickness": 0.1}       # silk: the standard's smallest designator (section 6), the fab's 0.1 mm line
    # a pad the routing crowds so a zone reaches it with one spoke is connected: a warning for the hand pass, not an
    # error (ecad-standards/layout.md section 4); KiCad's default severity for it is error
    severities = {"starved_thermal": "warning"}
    pro = {"board": {"design_settings": {"defaults": {}, "rules": rules, "rule_severities": severities}, "layer_presets": [], "viewports": []},
           "boards": [], "cvpcb": {"equivalence_files": []}, "libraries": {"pinned_footprint_libs": [], "pinned_symbol_libs": []},
           "meta": {"filename": f"{PROJECT}.kicad_pro", "version": 1}, "net_settings": net_settings(),
           "pcbnew": {"page_layout_descr_file": ""}, "schematic": {"legacy_lib_dir": "", "legacy_lib_list": []},
           "sheets": [[root.uuid, "Root"]], "text_variables": {}}
    json.dump(pro, open(os.path.join(OUT, f"{PROJECT}.kicad_pro"), "w"), indent=2)
    # library tables: the fragments the submodule ships, which refer to it as ${KIPRJMOD}/../libs
    for table in ("sym-lib-table", "fp-lib-table"):
        shutil.copyfile(os.path.join(LIBS, "tables", table), os.path.join(OUT, table))
    print(f"wrote {OUT}")
    # ERC + PDF
    sch = os.path.join(OUT, f"{PROJECT}.kicad_sch")
    r = subprocess.run(["kicad-cli", "sch", "erc", "--severity-all", "--format", "report", "-o", os.path.join(OUT, "erc.txt"), sch],
                       capture_output=True, text=True)
    print((r.stdout + r.stderr).strip()[-300:])
    # the report header carries the export time: pin it to the title-block date so two builds of one design match
    erc = os.path.join(OUT, "erc.txt")
    lines = open(erc, encoding="utf-8").read().split("\n")
    lines[0] = re.sub(r"\(\d{4}-\d{2}-\d{2}T\d{2}:\d{2}:\d{2}", f"({DATE}T00:00:00", lines[0])
    open(erc, "w", encoding="utf-8").write("\n".join(lines))
    # every pair net (named _P/_N, on either side of a flow-through ESD array) must be in a pair class, or it is
    # routed at the default geometry instead of its impedance (ecad-standards/layout.md 3.8)
    xml = os.path.join(OUT, "netlist-check.xml")
    subprocess.run(["kicad-cli", "sch", "export", "netlist", "--format", "kicadxml", "-o", xml, sch], capture_output=True, text=True)
    import xml.etree.ElementTree as ET
    classes = {n.get("name"): (n.get("class") or "Default") for n in ET.parse(xml).getroot().iter("net")}
    pairs = {n: c for n, c in classes.items() if re.search(r"_[PN]$", n) and (n[:-1] + ("N" if n.endswith("P") else "P")) in classes}   # a _P with its _N
    os.remove(xml)
    unclassed = sorted(n for n, c in pairs.items() if c not in PAIR_CLASSES)
    print(f"pair nets: {len(pairs)}, in a pair class: {len(pairs) - len(unclassed)}" + (f"; NOT classed: {' '.join(unclassed)}" if unclassed else ""))
    if unclassed:
        raise SystemExit("pair nets outside a pair class")
    # BOM: grouped by value and footprint, full reference lists (no ranges), as the README documents
    r = subprocess.run(["kicad-cli", "sch", "export", "bom", "--fields", "Reference,Value,Footprint,${QUANTITY}",
                        "--labels", "Reference,Value,Footprint,QUANTITY", "--group-by", "Value,Footprint",
                        "--ref-range-delimiter", "", "-o", os.path.join(OUT, "bom.csv"), sch], capture_output=True, text=True)
    print((r.stdout + r.stderr).strip()[-200:])
    pdf = os.path.join(OUT, f"{PROJECT}.pdf")
    r = subprocess.run(["kicad-cli", "sch", "export", "pdf", "-o", pdf, sch], capture_output=True, text=True)
    print((r.stdout + r.stderr).strip()[-200:])
    # the PDF's creation date is the only thing that differs between two exports of one design: pin it too
    # (same length as what KiCad wrote, so the file's offsets stay valid)
    raw = open(pdf, "rb").read()
    stamp = DATE.replace("-", ":").encode() + b":00:00:00"
    raw2 = re.sub(rb"/CreationDate \(D:\d{4}:\d{2}:\d{2}:\d{2}:\d{2}:\d{2}\)", b"/CreationDate (D:" + stamp + b")", raw)
    if raw2 != raw:
        open(pdf, "wb").write(raw2)


if __name__ == "__main__":
    main()

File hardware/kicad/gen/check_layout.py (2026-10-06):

#!/usr/bin/env python3
"""Layout review of a generated sheet: text that overlaps something, wires that
run through a symbol body, and power symbols pointing the wrong way.

Usage: check_layout.py <sheet.kicad_sch> [-v]

Text boxes are estimated (1.0 mm per character at 1.27 mm, 1.5 mm tall; global
labels get a 2.5 mm box). A field's angle is the symbol's rotation plus its
own, which is how KiCad draws it."""
import sys, math
from kisym import parse, Sym, pins_of, transform
from check_pins import text_w as glyph_w         # stroke-font glyph widths, shared with the pin-name check

SIZE = 1.27


def child(node, name):
    for c in node[1:]:
        if isinstance(c, list) and c and c[0] == Sym(name):
            return c


def props(node):
    out = {}
    for c in node[1:]:
        if isinstance(c, list) and c and c[0] == Sym("property"):
            at = child(c, "at")
            eff = child(c, "effects")
            hide = any(isinstance(x, list) and x and x[0] == Sym("hide") and x[1] == Sym("yes") for x in c[3:])
            just = None
            if eff:
                j = child(eff, "justify")
                if j:
                    just = " ".join(str(x) for x in j[1:])
            size = SIZE
            if eff:
                f = child(eff, "font")
                if f:
                    sz = child(f, "size")
                    if sz: size = float(sz[1])
            out[c[1]] = (c[2], float(at[1]), float(at[2]), float(at[3]) if len(at) > 3 else 0.0, just, hide, size)
    return out


def text_box(text, x, y, angle, just, size=SIZE, pad=0.0):
    w = max(1.0, glyph_w(text, size)) + pad
    h = size * 1.2 + pad
    angle = angle % 180
    if angle == 0:
        if just and "left" in just:
            x0 = x
        elif just and "right" in just:
            x0 = x - w
        else:
            x0 = x - w / 2
        return (x0, y - h / 2, x0 + w, y + h / 2)
    # vertical text: extends along y
    if just and "left" in just:
        y1 = y
        y0 = y - w
    elif just and "right" in just:
        y0 = y
        y1 = y + w
    else:
        y0, y1 = y - w / 2, y + w / 2
    return (x - h / 2, y0, x + h / 2, y1)


def overlap(a, b, tol=0.05):
    return a[0] < b[2] - tol and b[0] < a[2] - tol and a[1] < b[3] - tol and b[1] < a[3] - tol


def seg_box(a, b, tol=0.0):
    return (min(a[0], b[0]) - tol, min(a[1], b[1]) - tol, max(a[0], b[0]) + tol, max(a[1], b[1]) + tol)


def main(path, verbose=False):
    root = parse(open(path, encoding="utf-8").read())
    libs = {}
    ls = child(root, "lib_symbols")
    for sym in ls[1:]:
        if isinstance(sym, list) and sym[0] == Sym("symbol"):
            libs[sym[1]] = sym
    texts, bodies, stubs, wires, powers = [], [], [], [], []
    for node in root[1:]:
        if not isinstance(node, list) or not node:
            continue
        tag = node[0]
        if tag == Sym("wire"):
            pts = child(node, "pts")
            a, b = [(float(c[1]), float(c[2])) for c in pts[1:]]
            wires.append((a, b))
        elif tag in (Sym("label"), Sym("global_label")):
            at = child(node, "at")
            x, y, rot = float(at[1]), float(at[2]), float(at[3]) if len(at) > 3 else 0.0
            glob = tag == Sym("global_label")
            w = glyph_w(node[1], SIZE) + (3.0 if glob else 0.5)
            if glob:
                # a global label's flag is centred on the anchor line
                h = 2.0
                if rot % 180 == 0:
                    box = (x, y - h / 2, x + w, y + h / 2) if rot == 0 else (x - w, y - h / 2, x, y + h / 2)
                else:
                    box = (x - h / 2, y - w, x + h / 2, y) if rot == 90 else (x - h / 2, y, x + h / 2, y + w)
            else:
                # a local label's text sits above its wire whichever way it reads: 0.38 to 1.90 mm
                # above the anchor, measured on KiCad's render; a 0.1 mm margin each way
                a, b = 2.0, 0.28
                if rot % 180 == 0:
                    box = (x, y - a, x + w, y - b) if rot == 0 else (x - w, y - a, x, y - b)
                else:
                    box = (x + b, y - w, x + a, y) if rot == 90 else (x - a, y, x - b, y + w)
            texts.append((f"label {node[1]}", box, None, (x, y)))
        elif tag == Sym("netclass_flag"):
            at = child(node, "at")
            x, y, rot = float(at[1]), float(at[2]), float(at[3]) if len(at) > 3 else 0.0
            dx, dy = {0: (2.54, 0), 90: (0, -2.54), 180: (-2.54, 0), 270: (0, 2.54)}[int(rot) % 360]
            wires.append(((x, y), (x + dx, y + dy)))                      # the stem, as a wire nothing may print over
            for pr in node[1:]:
                if isinstance(pr, list) and pr and pr[0] == Sym("property") and pr[1] == "Netclass":
                    pat = child(pr, "at"); px, py = float(pat[1]), float(pat[2])
                    w = glyph_w(pr[2], SIZE) + 0.5
                    box = (px - w, py - 0.9, px, py + 0.9) if int(rot) % 360 == 180 else (px, py - 0.9, px + w, py + 0.9)
                    texts.append((f"netclass {pr[2]}", box, None, (x, y)))
        elif tag == Sym("text"):
            pass
        elif tag == Sym("symbol"):
            lib_id = child(node, "lib_id")[1]
            at = child(node, "at")
            X, Y, rot = float(at[1]), float(at[2]), int(float(at[3])) if len(at) > 3 else 0
            m = child(node, "mirror"); mirror = str(m[1]) if m else None
            pr = props(node)
            ref, val = pr["Reference"][0], pr["Value"][0]
            lib = libs[lib_id]
            is_power = lib_id.startswith("power:")
            # body: rectangles from the lib, else the pin extent shrunk by the stubs
            rects = []
            for sub in lib[1:]:
                if isinstance(sub, list) and sub and sub[0] == Sym("symbol"):
                    for g in sub[1:]:
                        if isinstance(g, list) and g and g[0] == Sym("rectangle"):
                            s0, e0 = child(g, "start"), child(g, "end")
                            p = transform(float(s0[1]), float(s0[2]), X, Y, rot, mirror)
                            q = transform(float(e0[1]), float(e0[2]), X, Y, rot, mirror)
                            rects.append(seg_box(p, q))
            pins = pins_of(lib)
            pin_pts = []
            pn = child(lib, "pin_numbers")
            nums_hidden = bool(pn) and any(str(x) == "hide" or (isinstance(x, list) and x and str(x[0]) == "hide" and str(x[1]) == "yes") for x in pn[1:])
            seen = set()
            unit_node = child(node, "unit"); unit = int(unit_node[1]) if unit_node else 1
            for p in pins:
                if p.unit not in (0, unit):
                    continue
                px, py = transform(p.x, p.y, X, Y, rot, mirror)
                # stub toward the body
                ang = ((180 - p.angle) if mirror == "y" else p.angle)
                ang = (ang + rot) % 360
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

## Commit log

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2026-10-04 Select the Panasonic JW1FSN for the passthrough; defer the USB VID
    Read the NC ratings off the datasheets rather than trusting headlines.
    G5Q-1 is the trap: a "10 A" relay whose NC contact carries 3 A. The
    JW1FSN rates its whole form C at 10 A / 30 VDC with AgSnO2 contacts;
    G2R-1 and G5LE-1 also pass. Table recorded in the spec. Coil budget
    corrected to the JW1FSN's 106 mA.
    USB VID/PID deferred indefinitely by decision; the Zephyr VID stays on
    the bench.
    [block-diagram.py]
2026-10-04 Switch the passthrough relay to the NO contact
    De-energized is target off; TGT PSU ON energizes the coil and the
    target powers. Nothing on J19 comes up until the baseboard is up and
    has been told to, and a dead baseboard leaves the target off. Power is
    something the bench grants.
    The cost is stated plainly in the spec: a baseboard reset is now a
    target power cycle, since the gate pulldown drops the coil in reset and
    firmware cannot restore it for a few hundred milliseconds. Firmware
    persists and restores the commanded state first thing at boot (new
    firmware rule 3; open question 13 asks whether it should). The G2RK-1
    latching relay is recorded as the hardware answer if the gap ever
    matters.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
    [block-diagram.py]
2026-10-04 Form factor, indicators, and the passthrough boot policy
    140 x 80 mm, four M3 holes 10 mm from each corner. Connectors facing
    you leave the left edge, those facing the target the right. The corner
    holes leave ~54 mm of usable edge, and the target-side connectors alone
    are 73 mm of Phoenix bodies, so the short edges carry the primary cable
    connectors and the rest go on the front long edge at the matching end.
    100 x 140 is recorded as the alternative that fits everything on the
    short edges. Passthrough copper widened to 8 mm for the ~110 mm run.
    An LED on every load-switch output, every rail and every relay coil,
    on the net rather than on an MCU pin, so it shows the actual state and
    costs not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
    [block-diagram.py]
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2026-10-04 Placement pass: every sheet clean on all four layout gates
    Hanging parts now sit with their near pin between rows, so a pull-up on
    the next lane crosses only its lead; parts slide past a neighbour's parts
    and text, not its plain wire, and never let a wire run through a body or
    a rail symbol. Chains on top/bottom pins run sideways first. Route
    channels are numbered per route. Power symbols that would land on a
    neighbouring wire get a jog or a hook. The VBUS sense divider moved to
    the K64's ADC pin so J3's VBUS lane is a short stretch the ESD array taps;
    the J1 tap sits before its divider. Relay coil clusters are drawn by the
    engine. Port switches moved so OUT stays on the VBUS row.
    ERC 0, no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
    [daplink.kicad_sch, ethernet.kicad_sch, ftdi.kicad_sch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]
2026-10-04 Symbol name clearance, divider at the reading pin, inlet TVS orientation
    Symbols: a top or bottom pin's name runs vertically into the body, so box
    symbols now grow outward by whole rows wherever such a name would reach a
    side pin's name (USB2517 three rows on top, K64 two rows top and bottom,
    PCA9517A three rows on top); the side-pin rows stay where they were so the
    sheet layouts are unaffected. U402's VDD names no longer print over USBUP_DP.
    Frame pass: nothing on the sheet frame or the title block, enforced by the
    layout gate (usable area 15..405 x 15..282 mm, title block from 300/253).
    Flow pass: pull-ups hang up to their rail, pull-downs hang down (R408/R409
    and the other strap and sen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
    [daplink.kicad_sch, ethernet.kicad_sch, ftdi.kicad_sch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]
2026-10-04 Pin-name overlap gate; symbol clearance from shared glyph widths
    gen/check_pins.py estimates the box of every visible pin name inside every
    symbol on a sheet (KiCad stroke font, per-glyph advance; hidden and stacked
    same-name pins skipped) and reports names that print over each other. Run
    on the last commit's sheets it finds exactly the overlaps seen on paper
    (U402 VDD33/VDDA33 over the first side rows, K64 VDD/VDDA/VREFH/VREFL over
    VREGIN, PTA0/SWD_CLK and PTE26, PCA9517A VCC(A)/VCC(B) marginal) and none in
    the KiCad library symbols. check_layout.py reports it as the pin-name
    category, and --gaps lists the closest name pairs.
    parts.py now uses the same glyph widths for the box-symbol clear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
    [daplink.kicad_sch, ethernet.kicad_sch, ftdi.kicad_sch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]
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2026-10-05 Clock sources flow downward; USB pairs ordered as on the ESD array
    Every crystal is now drawn by one helper: the two XTAL lanes run out past
    the side's route channels to two columns 7.62 mm apart, drop at right
    angles through the crystal lying across them, on into one load capacitor
    each and a shared GND rail with one GND symbol, which also takes the
    crystal's ground pins. The capacitors no longer hang off the lanes beside
    the hub with the crystal somewhere else; nothing crosses.
    Library v0.2.2: USB pairs are listed D- above D+, the order of the lines
    through a USBLC6 array, so J3/U202 now sit on the K64's USB rows with
    straight wires and the hub's upstream routes no longer cross; the hub's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
    [daplink.kicad_sch, ethernet.kicad_sch, ftdi.kicad_sch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]
2026-10-06 Reset circuits flow downward: pull-up, capacitor and button in one cluster
    A Reset attachment in the fan engine draws the network at the lane end, top to
    bottom: rail symbol, pull-up, the node row where the lane arrives, the capacitor
    straight below in the same column, one GND under it; a push button hangs from
    the lane one column nearer the hub and shares the GND rail. It declares its
    reaches, so the spread and slide passes keep the neighbouring rows clear. Used
    for the K64 (RESET), the USB2517 and the K20 (DAP RESET); the K20's SWD header
    takes the K20_RESET_N label instead of a fourth wire into the node. Netlist
    membership unchanged (356 nets); ERC, geometry, connectivity and layout gates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
    [daplink.kicad_sch, ethernet.kicad_sch, ftdi.kicad_sch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]
2026-10-06 Derived UUIDs and pinned export dates: builds are reproducible
    Every UUID is a UUID5 in a namespace made from the project name, keyed by what
    the element is (symbol: reference and unit; pin: its symbol; wire: sheet and
    ends; label: sheet, net and position; sheet: file name; identical keys get a
    counter in draw order). The ERC report header and the PDF creation date are
    pinned to the title-block date. Two builds of one design now give byte-identical
    files; no duplicate UUIDs across 4477. The BOM export is back in the build.
    Also: one Value for both units of each stacked USB-A connector. KiCad treated
    the differing unit values as an annotation error on every netlist export and
    listed them as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
    [bom.csv, daplink.kicad_sch, ethernet.kicad_sch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]
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2026-10-06 Nothing drawn over anything else; FTDI Friend header; DAPLink per FRDM-K64F; 90 ohm USB class
    Geometry gate now also reports two wires sharing a stretch, and is at zero on
    every sheet. Routes into a stacked connector from one side take staggered
    columns and rows; the signal relays are flipped so COM meets the header's
    first pin without crossings; the opto-isolator moves above the passthrough
    wires and taps the relay's COM lane; a tag before a route ends at the route's
    target; routes into joined pins end at the join; the K64's VREGIN diode taps
    the VBUS lane beside the ESD's stub; symbol mirrors are applied after
    rotation, as KiCad does.
    FT231X: the 3V3OUT lane stays on its pin row with its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
    [bom.csv, daplink.kicad_sch, ftdi.kicad_sch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]
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2026-10-06 First board: generated placement from the layout directives; current classes on the sheets
    gen/pcb.py (pcbnew) builds sbc-baseboard.kicad_pcb once from the netlist, the
    project file and gen/layout.py (docs/layout-directives.md as data): 140 x 80
    outline with 2 mm corners, M3 holes on GND with corner keep-outs, the Advanced
    Circuits 4-layer stackup, every footprint with its nets, edge connectors facing
    outward (USB-C on their footprint's PCB Edge mark), interior parts packed by
    function next to their connectors, the L2 ground plane with an isolated PSU_GND
    island, and sbc-baseboard.kicad_dru with the passthrough's keep-out and 2 mm
    creepage rules. DRC: no errors but twelve inside the GCT USB-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
    [bom.csv, power.kicad_sch, relays.kicad_sch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]
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2026-10-06 Lanes and two-sided placement: the PSU passthrough lanes laid and kept clear, small passives under the pins they serve
    Lanes (gen/layout.py LANES): a corridor reserved for one routed path, from
    pad to pad through axis-aligned legs, as wide as the class track plus
    clearance plus 0.25 mm, kept free of parts on both sides (footprint keep-out
    rule areas stopping at the parts the lane joins) and laid as copper at the
    class width. Two lanes carry the passthrough: J18 pin 1 to K803 COM and
    K803 NO to J19 pin 1, 2 mm PSU_3A tracks; PSU_GND goes through the L2
    island. The generator refuses a lane with a diagonal leg, a pad off its net
    or a fixed part in its way.
    Sides: connectors, ICs, relays, induc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
    [sbc-baseboard.kicad_pcb]
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2026-10-06 RJ45 to the back edge, the USB-C inlets spread around the middle of the left edge
    J10 now sits on the back edge from x = 14, facing out; J2 (PD in) is
    centred at y = 30 and J1 (upstream) at y = 54, split around the middle of
    the left edge, so the lower-left corner carries only J1's protection and
    the USB-A port band. The PHY turned to face the jack above it; the PD
    controller, its bus buffer and the programming header moved up with J2.
    The back edge no longer lies flat against a wall or rail, which the spec
    and the directives record. DRC unchanged: 12 documented errors, zero
    warnings; board reproducible.
    [sbc-baseboard.kicad_pcb]
2026-10-07 Calibrate the engine against 79 published KiCad boards; the measured practice becomes the standard's numbers
    scripts/reference-boards.txt and fetch-reference-boards.sh mirror Olimex,
    MNT Reform, SparkFun and Raspberry Pi designs into reference-boards/
    (git-ignored); scripts/harvest-placement.py measures each board with
    pcbnew (decoupling distance and side, ESD and crystal distance, pad gaps,
    edge clearance, bottom-side shares, tuck and through-hole margins,
    designator visibility and size, track widths) into docs/reference-boards.csv;
    docs/reference-boards.md records the method, the medians and the decisions.
    Set from the measurement: decoupling tries its IC's first two rings on top
    before t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
    [reference-boards.csv, sbc-baseboard.kicad_pcb]
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2026-10-07 Default signal track 0.2 mm from measured practice; the routing comparison in the reference write-up
    The net-class default track width goes from 0.25 to 0.2 mm (reference
    boards: 0.18 to 0.2 mm at 0.13 to 0.15 mm clearance); vias stay 0.6/0.3.
    docs/reference-boards.md gains the routing table (tracks, vias, layer
    usage, stitching, zones, pairs) and what the standard took from it.
    [reference-boards.csv]
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2026-10-07 The board routed: the engine's lanes and pairs, then FreeRouting over them; 189 connections left for the hand pass
    The autorouter ran over the locked lanes, the pair tracks and the L3
    rail regions (gen/pcb.py --route: the corridors open to it, the isolation
    region hardened and grown by the creepage, widths capped at 1 mm since
    the planes carry the current, inner layers as planes). Twelve passes:
    3067 track segments, 297 vias, 189 of 499 connections left, among them the
    rail pieces still wanting vias; DRC at the 12 documented USB-C errors with
    20 isolated-copper warnings for those pieces. The standards submodule is
    at the tool fixes. From here the board file is the source of truth: the
    hand p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
    [reference-boards.csv, sbc-baseboard.kicad_pcb]
2026-10-07 Ground floods on both outer layers and 297 stitching vias over the routed board, from the standard's new copper pass
    FLOODS and STITCH directives in gen/layout.py (GND on the plane's notched
    outline top and bottom, PSU_GND inside the passthrough region, a 5 mm grid kept
    out of the region by its creepage and stitched inside it inset by the same);
    gen/pcb.py --copper runs the standard's tools/copper.py over the routed board
    without regenerating placement. Floods cover 47 % of the top and 56 % of the
    bottom; 2.7 ground vias per cm² outside the region; 142 connections left for
    the hand pass; DRC at the 12 documented USB-C footprint errors, 35
    starved-thermal warnings where the routing crowds a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
    [sbc-baseboard.kicad_pcb]
2026-10-07 The board grows to 140 x 100: routing discarded, 20 mm added below y 52, the front-edge blocks moved with the edge, placement recomputed
    gen/layout.py: BOARD 140 x 100, H3/H4 at y 93, J1 at y 74, the USB-A stacks,
    PSU terminals, relay terminals and J14 at the new front edge, the ESD arrays,
    relays, eFuse, K803 and U801 20 mm down with them, the isolation region at
    y 62-100 with its plane notch, rail rectangles, floods and stitching
    rectangles, the PSU and port lanes' legs. Regenerated by the engine: 339
    footprints, 0 parked, lanes matched to 0.00 mm, DRC at the 12 documented
    footprint errors, 499 unrouted (no routing: the routed 140 x 80 board stays
    at a94a986). Directives, spec, READMEs and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
    [sbc-baseboard.kicad_pcb]
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2026-10-07 The hub 5 mm down and left toward the ports; the PD controller behind J2, placed from ST's evaluation board
    gen/layout.py: U402 to (39, 59) with the HUB_UP, DN1, DN2, DN4 legs following
    and DN5 given a leg (U409 is no longer in line with its pins); U101 to
    (16, 41) behind J2 with its CC pins toward it and the STUSB4500 template
    from UM2398 Figure 24 (STEVAL-ISC005V1 top composite: decoupling above,
    VBUS sense and enable right, I2C pull-ups below, reset left, top side),
    U102 and J17 beside it, the 3V3 buck 3 mm left. Measured: CC pins 12-13.6 mm
    from J2's CC pads, every PD part 1.6-2.5 mm from its pin, none on the
    bottom; voids clean, nothing parked, DRC unchanged. Directives, the
    guideline r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
    [sbc-baseboard.kicad_pcb]
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2026-10-07 The right-edge connectors spaced 10 mm apart: J13 10 mm and J9 20 mm down the edge, the console shifters and the FTDI island following
    gen/layout.py: J13 to y 49.2, J9 to y 65.0; U702/U703 to y 46.5 behind J13
    (clear of the HUB_DN2 leg at x 112), U501 to (117, 70) with R504/R505 at
    71.6/73.5 behind J9, the HUB_DN2 lane's last legs reaching them from y 62
    along x 126.5 as before, a 5V_PORTS piece to the FTDI switch. Regenerated:
    voids clean, nothing parked, DRC at the 12 documented errors (one starved
    thermal and one more rail island on L3 for the hand pass). Directives, the
    README and the block diagram's inset follow.
    [sbc-baseboard.kicad_pcb]
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2026-10-08 The three USB-C receptacles use the house GCT footprint with the peg holes clear of the outer ground pads: DRC at zero errors
    gen/kit.py points USBC at calico:USB_C_Receptacle_GCT_USB4105-xx-A_16P_TopMnt_Horizontal_PegClear
    (ecad-libraries 0.3.5, submodule bumped): KiCad's footprint rebuilt pad for pad
    with A1, A12, B1 and B12 0.1 mm shorter at the peg end, hole to copper 0.29 mm
    against the fab's 0.25 mm. Schematic rebuilt (ERC clean, the footprint field on
    J1-J3, BOM, PDF), board regenerated with the placement unchanged; the twelve
    hole-clearance errors are gone. README and the reference-design review record
    the deviation from GCT's drawing.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
    [bom.csv, hub.kicad_sch, mcu.kicad_sch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]
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2026-10-08 The board routed: FreeRouting over the locked lanes and planes, then the copper pass; 129 connections left for the hand pass
    gen/pcb.py --route --copper on the 140 x 100 board: 3 148 tracks (47 % on the
    bottom), 664 vias with 360 ground stitching on the 5 mm grid, floods over 52 %
    of the top and 60 % of the bottom, the 282 lane tracks locked and intact with
    every pair at 0.00 mm. DRC at zero errors; 39 starved thermals, three rail
    islands and one dangling track end as warnings for the hand pass. The
    generator writes starved_thermal at warning severity into the project file.
    The three receptacles carry the libraries' 0.3.6 metadata. README and the
    reference write-up carry the measured result;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
    [sbc-baseboard.kicad_pcb]
2026-10-08 The port VBUS nets join their 3 A class; the passthrough region 2 mm right; the inset follows the placed connectors
    The project's net class patterns are globs over the full hierarchical
    name, and PORT?_VBUS matched nothing: the four port VBUS nets were in
    Default and the router laid them at 0.2 mm. The patterns for the
    sheet-local nets now start with *, the standard's engine (d1d4ac4) stops
    on a class no net resolves to, and the README says why.
    layout.py: J18/J19, K801/K802, K803/U801, the isolation region, its plane
    hole and the planes around it move 2 mm right so J4's shield pads stand
    outside the passthrough's creepage band; RAIL_VIAS by class; 24 router
    passes. The block diagram's boar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
    [block-diagram.py, build.py, layout.py]
2026-10-08 The board re-routed with the port VBUS nets in their class: 2 798 tracks, 799 vias, DRC at zero errors, 137 connections for the hand pass
    FreeRouting over the locked lanes and planes with the corrected net
    classes (24 passes, 2 h 20 min), the pair-net sweep, the 10 µm clearance
    margin in its rules, then the copper pass: ground floods over 50 % of the
    top and 59 % of the bottom, 334 stitching vias, the port VBUS nets at
    2 mm. DRC reports no errors, 23 starved thermals and 16 rail islands on
    L3; 137 of the 499 connections go to the hand pass. The README's routed
    paragraph and the reference-boards measurements carry the new figures.
    [sbc-baseboard.kicad_pcb]
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2026-10-08 The board re-routed over the corrected anchors and the rail vias: 2 823 tracks, 813 vias, DRC at zero errors, 131 connections for the hand pass
    FreeRouting over the locked lanes, the 233 rail vias and the planes (24
    passes, 2 h 27 min), the pair-net sweep (44 items; HUB_DN2's shunt
    capacitors keep the router's copper, named in the log), the copper pass:
    floods over 50 % of the top and 61 % of the bottom, 336 stitching vias.
    DRC reports no errors, 28 starved thermals and one rail island; 131 of
    the 499 connections go to the hand pass, most of them plane-net pads with
    no room for a rail via. The DRC report now carries its unconnected items
    as a tally per net. The standard at d0f58a6.
    Co-Autho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
    [sbc-baseboard.kicad_pcb]
2026-10-08 L3 carries the three heavy rails, each one piece; +3V3 is routed in a 0.5 mm class
    The second verification pass found the +5V_PORTS rail drawn as four
    unjoined pieces with its band short of every port-switch pad, the +3V3
    base cut into three islands by the other rails, and 16 of the +3V3 rail
    vias standing in copper another rail had carved away. On one rail layer
    the two 6 A trees and the 3 A inlet leave no planar room for a fourth
    net: the +3V3 base is gone, +3V3 is routed (PWR_1A, 0.5 mm, the default
    clearance for its 0.5 mm pitch pins), and the three rails are redrawn as
    single pieces (the band over the port switches to y 83, a bridge above
    the region to the DAPLink's VBUS, L102's piece t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
    [build.py, layout.py]
2026-10-08 The board routed over the three one-piece rails with +3V3 routed, saved with its fills: 2 833 tracks, 836 vias, DRC at zero errors, 116 connections for the hand pass
    FreeRouting over the locked lanes, the 237 rail vias (chains of the
    class's vias on the 6 A and 3 A pads now) and the planes (24 passes,
    3 h), the pair-net sweep (37 items), the copper pass with the floods
    and 340 stitching vias, the board saved filled so the pours are in the
    file as opened and rendered (the standard at d45c989). DRC reports no
    errors, 25 starved thermals and no rail island; 116 of the 499
    connections go to the hand pass. The README and the reference-boards
    measurements carry the figures.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
    [sbc-baseboard.kicad_pcb]
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2026-10-09 The six-layer board routed: 3 050 tracks, 939 vias, DRC at zero errors, 98 connections for the hand pass
    FreeRouting on L1, L3 and L6 over the locked lanes, the 237 rail vias
    and the planes on L2, L4 and L5 (24 passes, 5 h 12 min), the pair-net
    sweep, the faulted-and-dangling sweep, the copper pass with 332 stitching
    vias and the floods saved filled. 98 of the 499 connections go to the hand
    pass against 116 on four layers: the signals from 61 to 36, the power
    nets unchanged (pads with no room beside them for a rail via). The
    directives give the router a six-instance portfolio for the next run
    (the standard at 26811c7). The README and the reference-boards
    measurements carry the figures.
    Co-A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
    [sbc-baseboard.kicad_pcb]
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2026-10-10 The PD inlet and the two 5 V bucks go; a 2.5 mm barrel jack feeds one +5V rail through a reverse-polarity FET
    Power in is a 5 V 4 A (20 W) adapter on a Kycon KLDX-0202-BC barrel
    jack (J2, centre positive), clamped by an SMAJ5.0A, passed by a
    DMP3013SFV P-channel MOSFET (body diode toward the rail, gate at GND,
    9.5 mOhm) into +5V: two 47 uF and a 100 nF, an amber LED. The
    STUSB4500, its I2C buffer and Qwiic programming header, the two
    TPS54560B bucks and their islands, VBUS_IN, +5V_PORTS and +5V_TGT as
    separate rails are gone; +5V feeds the port switches, the relays, the
    FTDI switch, the 3V3 buck and the TPS26630 eFuse, whose output is the
    switched target rail +5V_TGT, now limited to 3 A (RIL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
    [bom.csv, daplink.kicad_sch, hub.kicad_sch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]
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2026-10-10 The RJ45 and its PHY 16 mm left along the back edge, into the corner the bucks left, opening the K64's side
    J10 from x 71 to x 55, the PHY U301 with it so the Ethernet pairs keep
    their 7 to 11 mm, the magnetics void following. The jack's body now ends
    12 mm short of the K64's island and the PHY's parts 10 mm short of its
    decoupling; the corner between the inlet and the jack (x 28 to 51) is
    free. Placed and gated, unrouted: 479 connections, DRC clean.
    [sbc-baseboard.kicad_pcb]
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2026-10-10 The generator reproduces the owner's hand placement: every part's pose harvested into gen/hand_placement.py
    The standard's tools/handplace.py (ecad-standards ca75146..fe3) reads every
    footprint's pose off the hand-placed board (c1628c5) into
    gen/hand_placement.py as HAND, 254 parts (84 on the bottom); layout.py
    merges HAND over FIXED, so a hand-fixed part outranks its anchor and the
    engine's own rule, and the edge connectors J1, J2, J3 and J10 have the
    positions the hand pass gave them in CONNECTORS. The regenerated board is
    the hand-placed one, part for part (handplace.py --check: 0 placed
    elsewhere, 0 missing; 271 fixed).
    placement.txt ends with the engine's new "hand placement" section: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
    [sbc-baseboard.kicad_pcb]
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

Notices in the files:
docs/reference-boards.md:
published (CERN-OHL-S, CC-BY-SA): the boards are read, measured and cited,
